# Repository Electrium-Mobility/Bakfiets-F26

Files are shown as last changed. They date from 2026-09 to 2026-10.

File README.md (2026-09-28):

# Bakfiets F26

Electrium Mobility's electric cargo bike ("Bak Choy"), Fall 2026. This repo holds everything from the 2024 build and the 2025 co-op CAD.

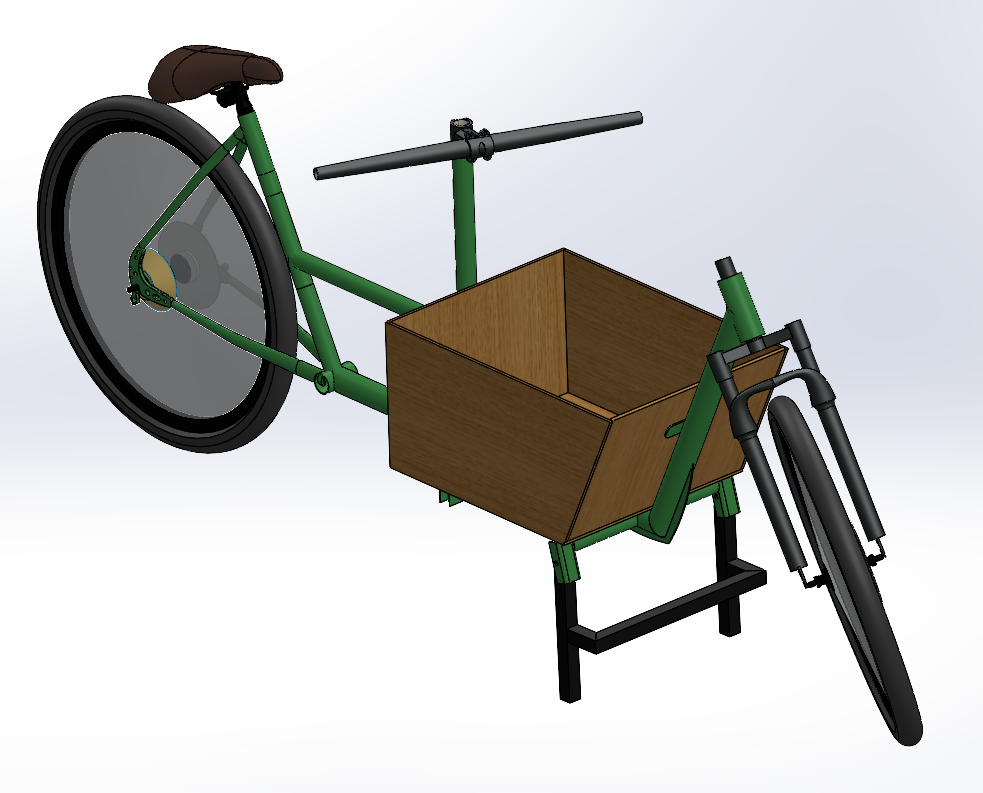
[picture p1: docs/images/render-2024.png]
2024 render of the bakfiets


## New here?

**Open [ONBOARDING.md](ONBOARDING.md).** Everything you need is there, starting with a short to-do list at the top. Setup takes about 2 to 3 hours. Questions go in your subteam's channel.

## What's in this repo

| Folder | What's inside | Start with |
| --- | --- | --- |
| [`mechanical/`](mechanical/) | All SolidWorks CAD | [`mechanical/README.md`](mechanical/README.md) |
| [`mechanical/cad-2025-coop/`](mechanical/cad-2025-coop/) | Newest model (May 2025), matches the partly built bike | `bakfiets_main_asm.SLDASM` |
| [`mechanical/cad-2024/`](mechanical/cad-2024/) | The 2024 design: frame, steering, kickstand, cargo box, welding jig, notching guides, FEA study | `Assem1.SLDASM` |
| [`electrical/`](electrical/) | The 2024 block diagram and notes on reusable boards | [`electrical/README.md`](electrical/README.md) |
| [`firmware/`](firmware/) | Display code, a ready-to-run desk demo, the CAN bus example | [`firmware/desk-demo/desk-demo.ino`](firmware/desk-demo/desk-demo.ino) |
| [`docs/setup/`](docs/setup/) | Extra setup detail and videos for each subteam | [`2-mechanical.md`](docs/setup/2-mechanical.md) |
| [`docs/term-projects.md`](docs/term-projects.md) | The main goals for the term, for after onboarding | |
| [`docs/reference-projects.md`](docs/reference-projects.md) | Other Electrium repos worth copying from | |
| [`docs/meetings/`](docs/meetings/) | Agenda and notes for each team meeting | [`2026-09-30.md`](docs/meetings/2026-09-30.md) |
| [`docs/diagrams/`](docs/diagrams/) | Onboarding path, bike overview, team structure, how to submit, term project map (with the scripts that draw them) | |
| [`docs/images/`](docs/images/) | Renders, CAD previews, photos | |
| [`docs/history/`](docs/history/) | Old README, website pages, and where every file came from | [`SOURCES.md`](docs/history/SOURCES.md) |

## Where the project stands

See [Where It Stands](ONBOARDING.md#where-it-stands) and [Open Questions](ONBOARDING.md#open-questions) in the onboarding guide. The main goals for the term are in [docs/term-projects.md](docs/term-projects.md).

## Rules for this repo

- Work on a branch and open a pull request. Don't push straight to `main`.
- Don't move or rename SolidWorks files inside `cad-2024/` or `cad-2025-coop/`. Assemblies find their parts by folder path, and moving files breaks them.
- Put new work in a new folder, for example `mechanical/cad-2026/` or `firmware/display-2026/`. Copy CAD with SolidWorks **Pack and Go**, and only one person edits a CAD file at a time.

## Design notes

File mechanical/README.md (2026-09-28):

# Mechanical

All SolidWorks files for the bakfiets. Setup steps are in [docs/setup/2-mechanical.md](../docs/setup/2-mechanical.md).

**Don't move or rename files inside `cad-2024/` or `cad-2025-coop/`.** The assemblies find their parts by folder path. Put new work in `cad-2026/`, copying what you need with **File > Pack and Go** (add a prefix so names don't clash). One person edits a CAD file at a time: say on your issue which files you're changing, because Git can't merge two edits to the same SolidWorks file.

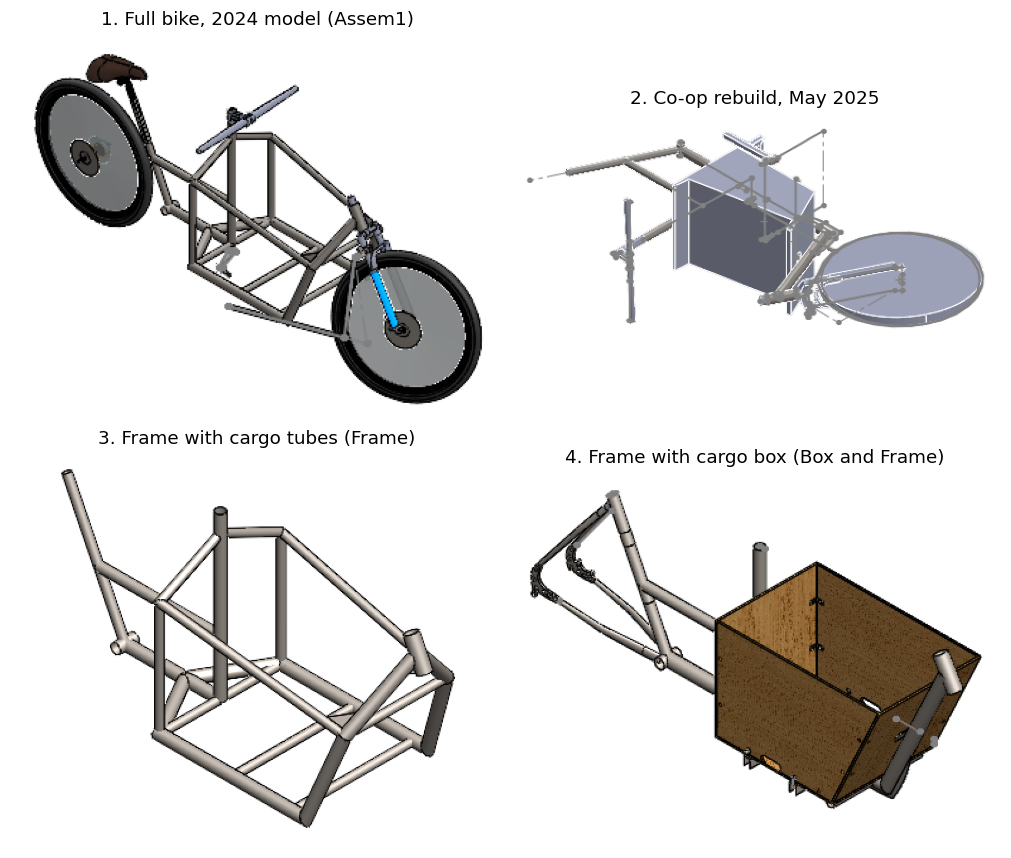
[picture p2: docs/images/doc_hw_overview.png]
CAD overview


## Which model to use

| Folder | What it is | When to use it |
| --- | --- | --- |
| [`cad-2025-coop/`](cad-2025-coop/) | A clean rebuild from May 2025, on the `summer2025coop` branch (GitHub user Anthony3141). One master sketch drives the frame, suspension, steering rod, kickstand and a simple cargo box. Its commit says it models the partly built bike | Start here |
| [`cad-2024/`](cad-2024/) | The full 2024 design, exactly as the 2024 team left it | For parts the co-op model lacks: the jig, the notching guides, detailed steering and cargo box |
| [`cad-2025-coop/edited-2024-parts/`](cad-2025-coop/edited-2024-parts/) | Five 2024 parts the `summer2025coop` branch changed (kickstand, cargo box, aluminium angles) | Compare with the 2024 versions before using either |

## cad-2025-coop: the newest model

| File | What it is |
| --- | --- |
| `bakfiets_main_asm.SLDASM` | **Open this.** The whole bike |
| `bakfiets_master_sketch.SLDPRT` | The layout sketch every part follows |
| `bakfiets_frame.SLDPRT` | The frame (weldment) |
| `bakfiets_front_suspension.SLDPRT`, `bakfiets_front_wheel.SLDPRT` | Front end |
| `bakfiets_steering_handlebars.SLDPRT`, `bakfiets_steering_rod.SLDPRT`, `bakfiets_ball_joint.SLDPRT` | Steering linkage |
| `bakfiets_kickstand.SLDPRT` | Kickstand |
| `bakfiets_cargo_box_low_detail.SLDPRT` | Simple cargo box |
| `bakfiets_weldment_profiles/` | Tube profiles. Add the `cad-2025-coop` folder under SolidWorks File Locations > Weldment Profiles (see the setup guide) |

## cad-2024: the full 2024 design

| Part | Where | Notes |
| --- | --- | --- |
| Whole bike | `Assem1.SLDASM` | The 2024 top-level assembly |
| Frame | `Frame 2.0.SLDPRT`, drawing `Frame 2.0-Sweep8.SLDDRW` | Latest 2024 frame. Nobody recorded whether the drawing was used to build it |
| Tube sizes | `Weldment Cross-section/` | In the file names, as outside diameter x wall. Main tube 1.5" x 0.065", steering tube 36 x 1.1 mm, cargo tube 1" x 0.065", bottom bracket 38.1 x 3.3 mm, seat tube 28.6 x 0.6 mm, top tube 31.7 x 0.5 mm, head tube 1" x 0.065" or 46 x 1.5 mm. Unverified: a 1" head tube can't hold a standard headset, and 0.5 to 0.6 mm walls are donor-bike tubing, not something students can TIG weld. Confirm on the real frame in #4 |
| FEA | `Frame 2.0-Static 2.*` | One static study on Frame 2.0 (June 2024). The 95 MB results file was left out, so rerun the study to regenerate it. No record of the loads used |
| Welding jig | `jig/Jig/JigV2.SLDASM`, cut files `jig/Jig/*.dwg`, `*.DXF` | Laser-cut MDF jig for the main frame |
| Notching guides | `notches/*.STL` | 3D-print, slide over the tube, and cut to the line |
| Steering | `steering system/steeringAssembly.SLDASM` | Linkage, ball joint, steering plates |
| Kickstand | `KickstandAssembly.SLDASM`, `Kickstand.SLDPRT`, `KickstandBracketFeb15.SLDPRT` | |
| Cargo box | `Cargo Box/Cargo Box.SLDASM`, `Box and Frame.SLDASM`, `Box with angles.SLDASM` | Several versions, none marked final |
| Motor | `MotorCrank/CrankMotorAssembly.SLDASM` | A crank-mounted (mid-drive) motor model |
| Printed parts | `scrap bike parts/stem parts/turnSignalCase*.STL`, `battery box/battery pack/Antispark cover.SLDPRT` | Turn signal housing and antispark cover |
| Donor parts | `scrap bike parts/` | Fork, wheels, seat and stem modelled from scrap bikes |

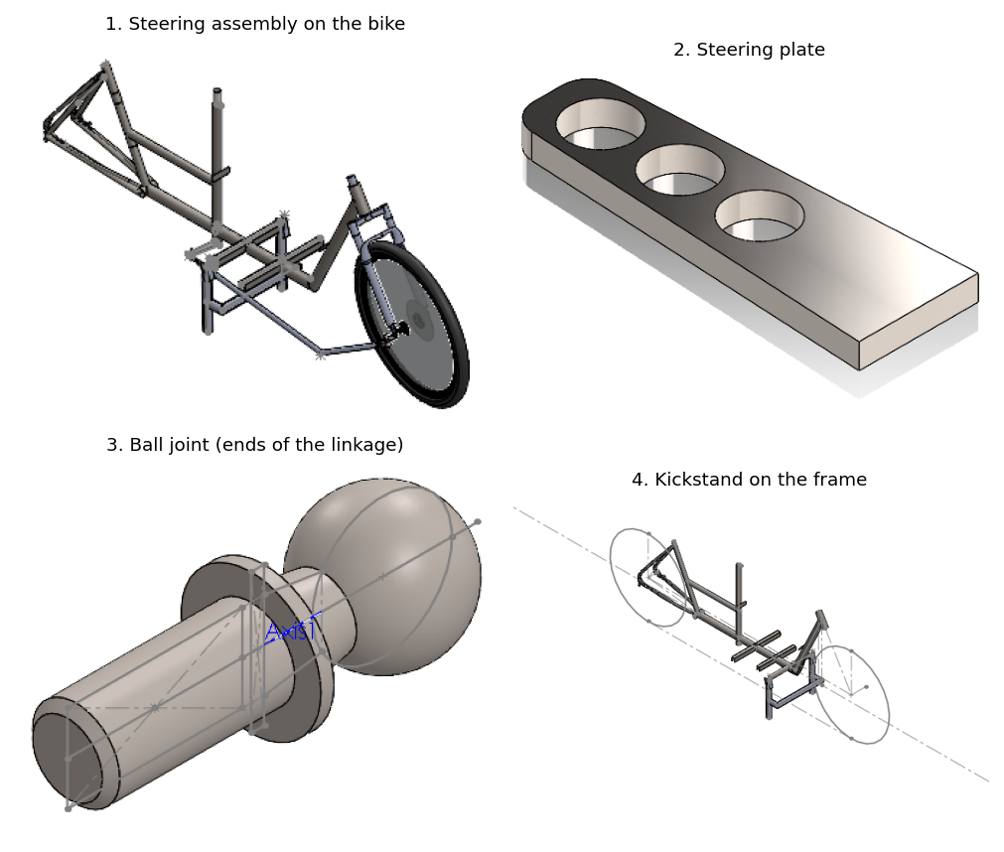
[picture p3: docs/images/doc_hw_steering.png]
Steering and kickstand


*How the steering works: the handlebars turn a plate under the frame. A rod with a ball joint at each end carries that motion forward to a plate on the fork, so the front wheel turns.*

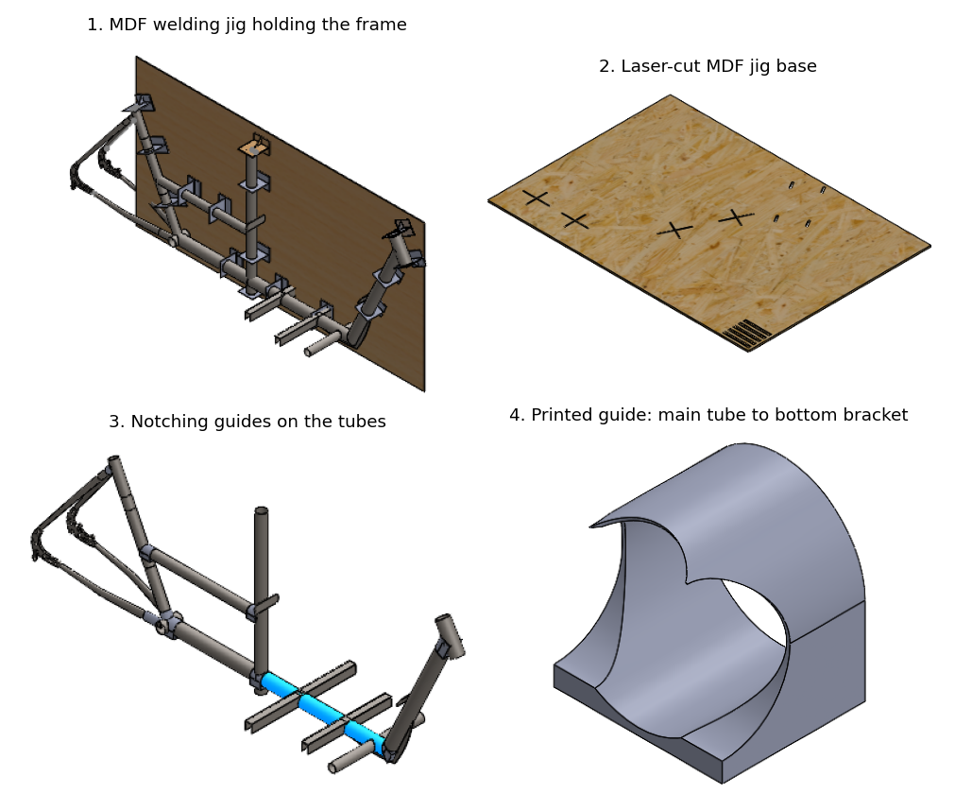
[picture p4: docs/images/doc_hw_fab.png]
Jig and notching guides


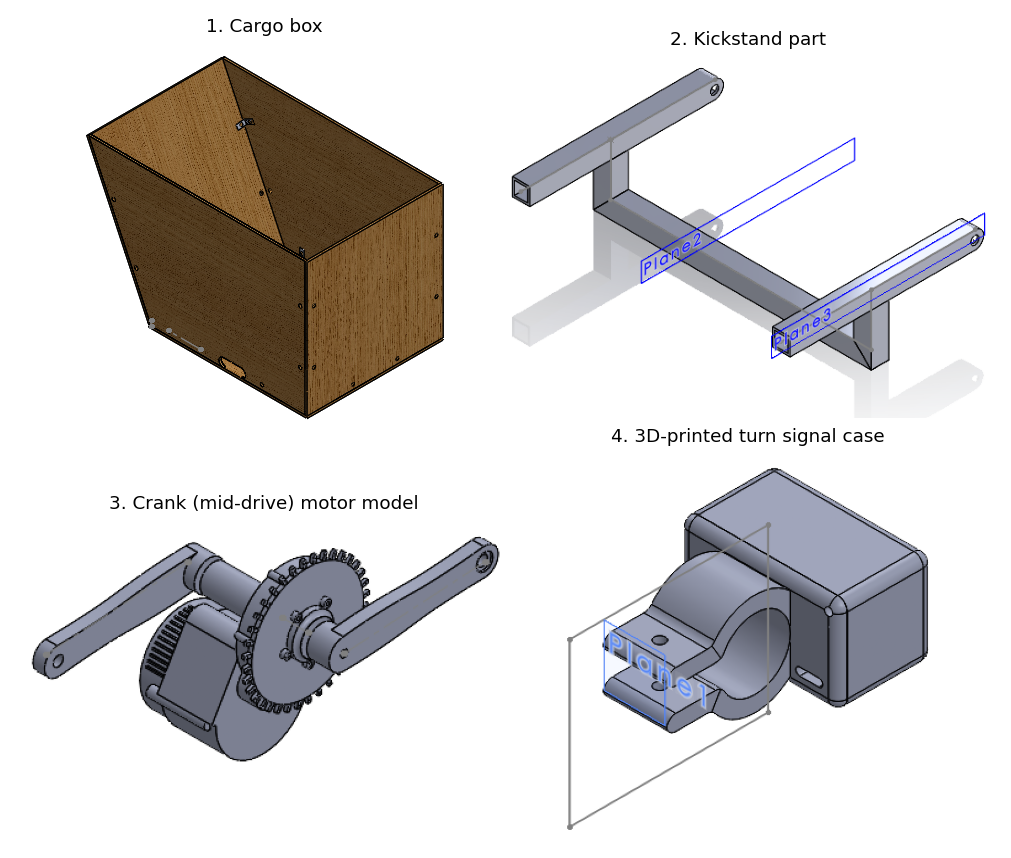
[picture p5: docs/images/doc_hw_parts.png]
Other parts


More previews of individual parts are in [`docs/images/cad-previews/`](../docs/images/cad-previews/).

## Gaps

- No record of the FEA loads or results
- No battery mount in any model
- Nobody has recorded how much of the real frame is welded

Don't send any drawing out for cutting or welding until the FEA loads and results are written down ([issue #6](https://github.com/Electrium-Mobility/Bakfiets-F26/issues/6)) and the mechanical lead and project lead have approved it.

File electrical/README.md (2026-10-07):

# Electrical

Setup steps are in [docs/setup/3-electrical.md](../docs/setup/3-electrical.md).

Only one electrical file survived from 2024: a block diagram, redrawn below. We'll use Pack 4, a 48 V pack labelled 12S2P, and a 48 V, 2000 W direct-drive hub motor in a 24" wheel. Both are in the Electrium bay ([#21](https://github.com/Electrium-Mobility/Bakfiets-F26/issues/21), [#1](https://github.com/Electrium-Mobility/Bakfiets-F26/issues/1)). The team already has a BMS and a charger, so neither needs buying. Photos of the motor, controller and packs are in [docs/photos/bay-2026-10](../docs/photos/bay-2026-10/README.md). We'll set the motor controller to 500 W in VESC Tool ([#18](https://github.com/Electrium-Mobility/Bakfiets-F26/issues/18)). The 2024 schematics and pack notes aren't in any Electrium repo. This term starts the electrical design fresh.

## The pack is "48 V"

Pack 4 is labelled 12S2P: 12 groups in series, each group being 2 cells in parallel, 24 cells in total. That's about 44 V nominal, 50.4 V full and about 36 V empty. "48 V" is the class name. (The website says the 2024 pack was 12S3P, but that pack hasn't been found.) **Every part that touches the battery must be rated well above 50.4 V: 100 V MOSFETs and capacitors, and fuses DC-rated for at least 60 V. The one exception is a surge (TVS) diode, whose standoff should sit just above 50.4 V (about 54 to 58 V), with its clamp voltage below 100 V.**

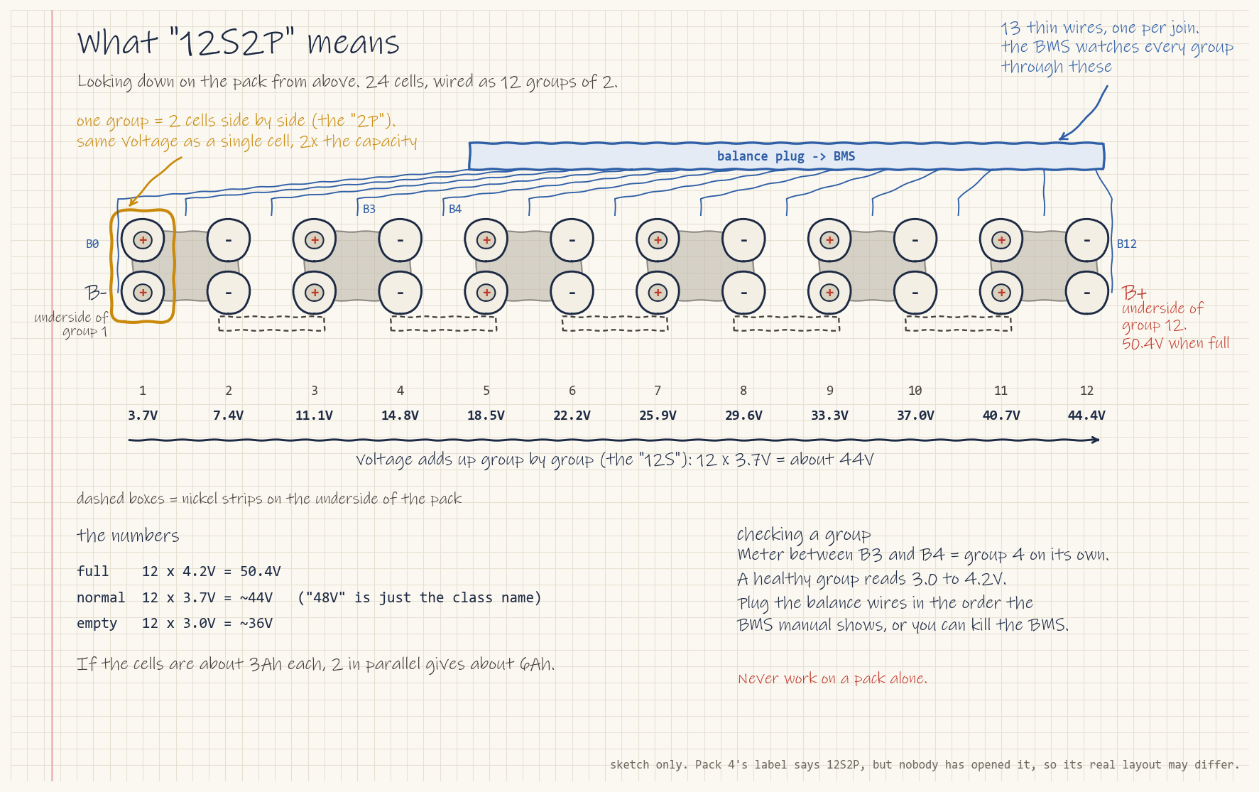
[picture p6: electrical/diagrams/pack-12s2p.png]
Inside a 12S2P pack


## How power flows through the bike

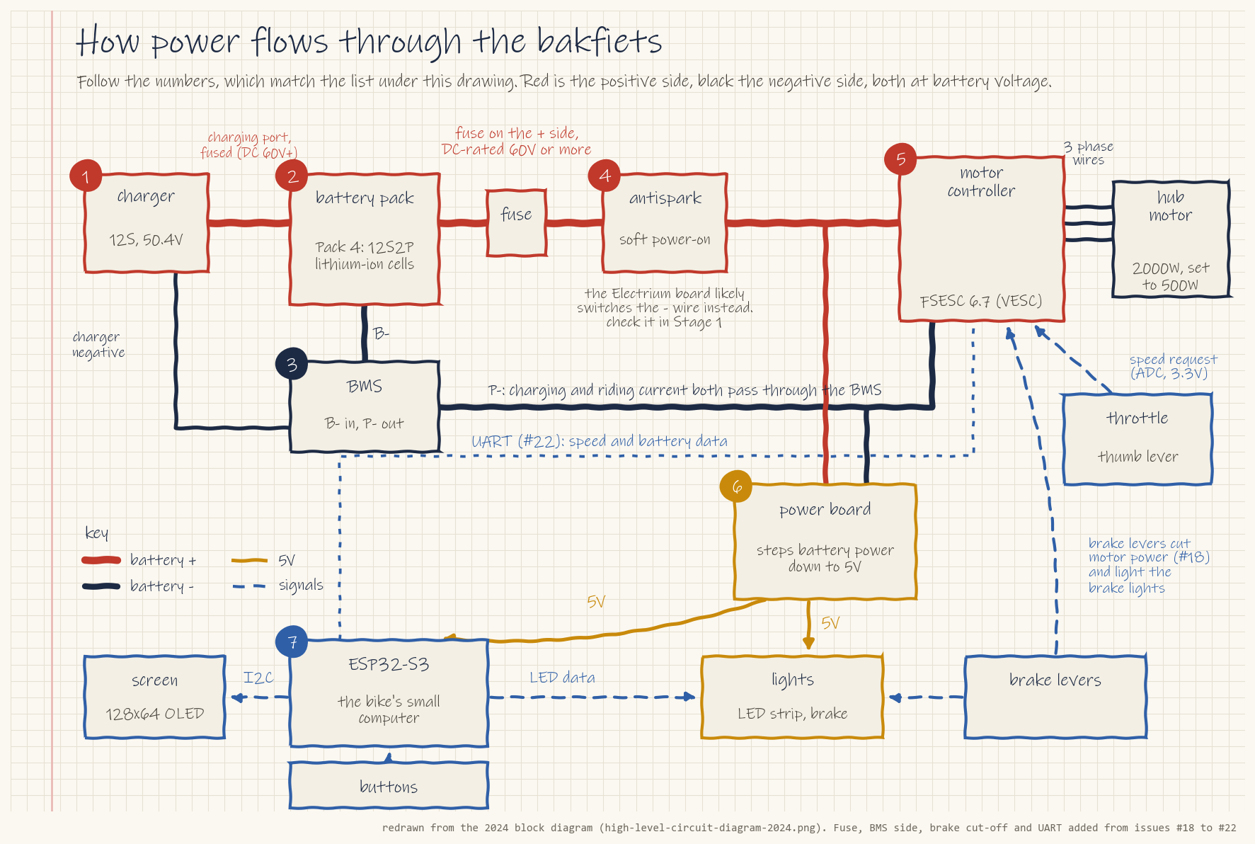
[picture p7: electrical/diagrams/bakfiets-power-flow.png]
How power flows through the bakfiets


A redrawn, color-coded version of the 2024 block diagram. Red lines carry full battery voltage and orange lines carry 5 V. Dashed blue lines are signals only. The original is [`diagrams/high-level-circuit-diagram-2024.png`](diagrams/high-level-circuit-diagram-2024.png), and the script that draws this one is next to it.

Follow the numbers:

1. **Charger.** Plugs into a charging port on the frame and fills the pack to 50.4 V.
2. **Battery pack.** Pack 4, 12S2P. Its positive side goes through a fuse, DC-rated for 60 V or more.
3. **BMS.** Sits on the pack's negative side (B- in, P- out), so charging and riding current both pass through it. Cuts the pack off on overcharge, over-discharge, overheating or a short.
4. **Antispark.** The power button turns it on, so the controller's capacitors charge gently instead of sparking. The Electrium anti-spark board uses N-channel MOSFETs, which usually means it switches the negative wire. Check its schematic. If it does switch the negative wire, the power board and the ESP32 must take their negative from the switched side too. Otherwise the ESP32's ground wire to the controller becomes a path around the antispark, which can damage the controller's COMM port or the ESP32.
5. **Motor controller.** The ESC turns battery power into the three motor wires. The throttle sends it a speed request, and the brake levers tell it to cut power.
6. **Power board.** The PDB steps 48 V down to 5 V for the electronics and lights.
7. **ESP32-S3.** It drives the display over I2C and the LED strip, reads the buttons, and gets speed and battery data from the controller over UART. The brake levers also switch the brake lights.

## What plugs into the motor controller

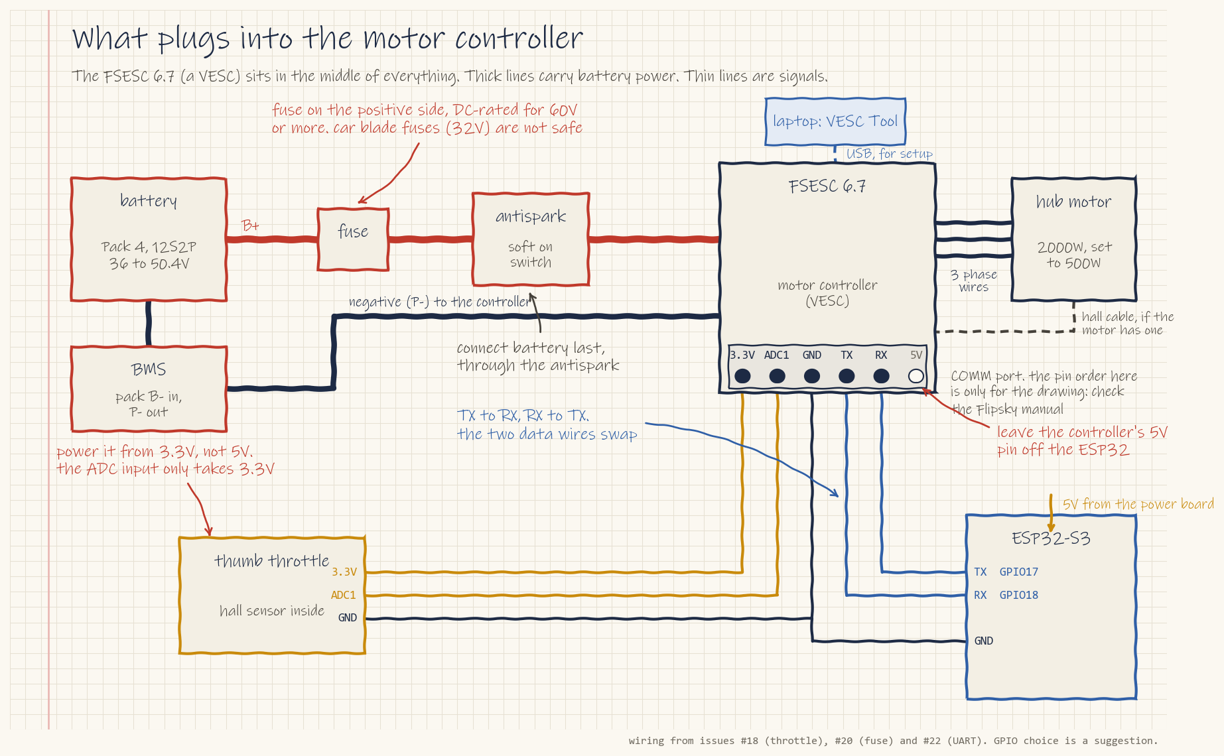
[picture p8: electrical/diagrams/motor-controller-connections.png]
Motor controller connections


The throttle, UART and fuse details come from term projects #18, #20 and #22. The COMM port pin order in the drawing is only for layout, so check the Flipsky manual.

## Boards you can learn from or reuse

| Board | Repo | Use it for |
| --- | --- | --- |
| Antispark switch (2023) | [anti-spark](https://github.com/Electrium-Mobility/anti-spark) | Your first schematic to read: 18 parts, three 100 V MOSFETs, gerbers included |
| Power distribution + antispark (2026) | [power-distribution-antispark](https://github.com/Electrium-Mobility/power-distribution-antispark) | Reference only, see below |
| ESC (2026) | [esc-w26](https://github.com/Electrium-Mobility/esc-w26) | A well-documented README with input protection explained. Built for 36 V |
| Small complete board | [raspberry-pi-breakout](https://github.com/Electrium-Mobility/raspberry-pi-breakout) | A tidy, recent KiCad project with reviewer notes |
| Lights and telemetry | [skateboards26-telemetrylights](https://github.com/Electrium-Mobility/skateboards26-telemetrylights) | Lights and a display fed by power-board signals |

**The 2026 power board can't be used as-is** (from reading its schematic, to be confirmed with the datasheets). Its note says "Max Vin = 48V" and its MOSFETs are 60 V parts, which leaves little margin over a 50.4 V full pack. Its TVS diode (SMCJ48CA) has a 48 V standoff, so a full 50.4 V pack sits above its rating with little margin (breakdown starts at 53.3 V). It also clamps at 77.4 V, above what the 60 V MOSFETs survive. A new version needs 100 V MOSFETs and capacitors, a TVS with a standoff of about 54 to 58 V whose clamp stays below 100 V, and a buck converter rated to match.

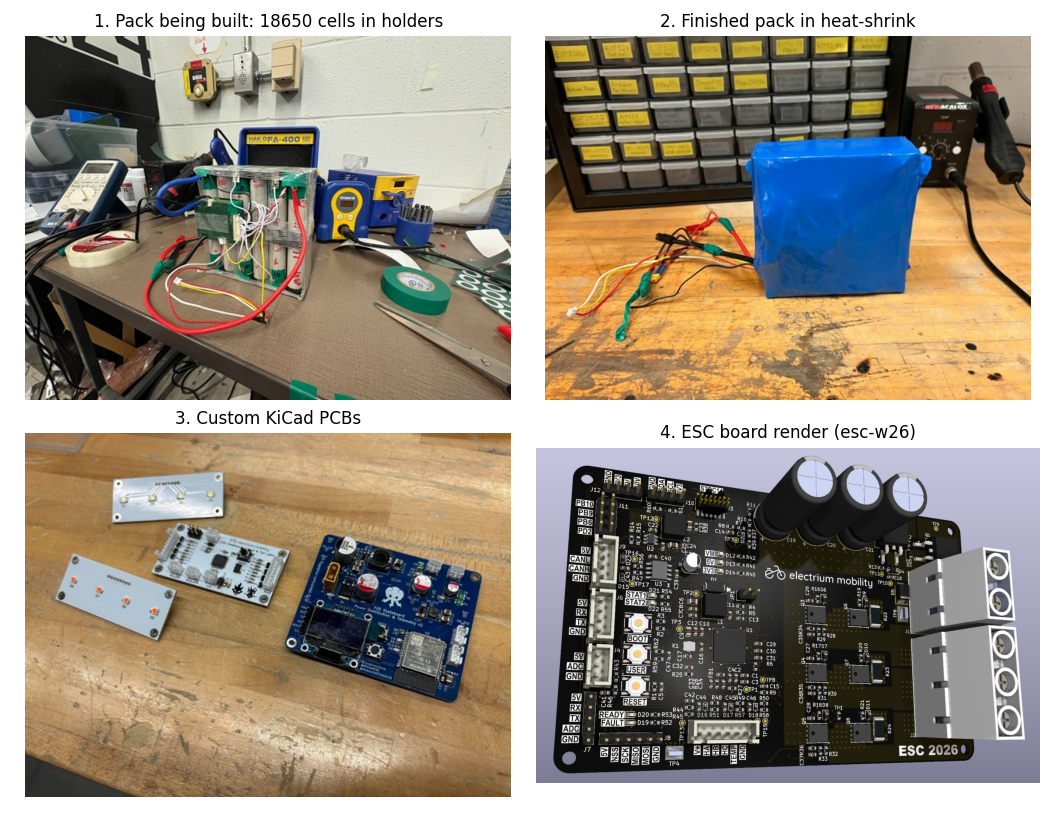
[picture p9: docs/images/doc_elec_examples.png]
Electrical work on other Electrium projects


*Photos 1 to 3 are from the F25 skateboard, and 4 is the esc-w26 board. This is what finished electrical work looks like on this team.*

## Gaps

- Confirm the motor and controller on the real bike ([issue #1](https://github.com/Electrium-Mobility/Bakfiets-F26/issues/1))
- Schematic and PCB for the bakfiets power board
- Pack cells, BMS model and charge port
- Wiring harness, connector pinout and a BOM

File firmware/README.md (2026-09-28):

# Firmware

To run the desk demo, follow [Firmware Stage 1](../ONBOARDING.md#stage-1-run-the-desk-demo) in the onboarding guide. [docs/setup/4-firmware.md](../docs/setup/4-firmware.md) has the same steps with extra help.

| Folder | What it is | Status |
| --- | --- | --- |
| [`desk-demo/`](desk-demo/) | **Start here.** The 2024 display code as a ready-to-open Arduino sketch, with the LED pin moved off GPIO 9 | Should run on an ESP32-S3 with an SSD1306 OLED. The first hardware test is #12 |
| [`display-2024/`](display-2024/) | The original 2024 code (`main.cpp`) and the hand-drawn screen layout | Fixed numbers only, kept unchanged for reference |
| [`can-twai-2024/`](can-twai-2024/) | Two ESP-IDF projects based on Espressif's TWAI (CAN) example, one with an OLED drawn with LVGL (Nov 2024). The folder names are reversed: the "receiver" is the board that transmits | Fixed values on screen (60% and 18), and targets a plain ESP32. ESP-IDF is a different tool from Arduino IDE, and you don't need it for onboarding |
| [`simulator-2024/`](simulator-2024/) | A Rust desktop mock-up of the 128x64 screen | Optional, skip it for onboarding. Setup notes are for macOS |

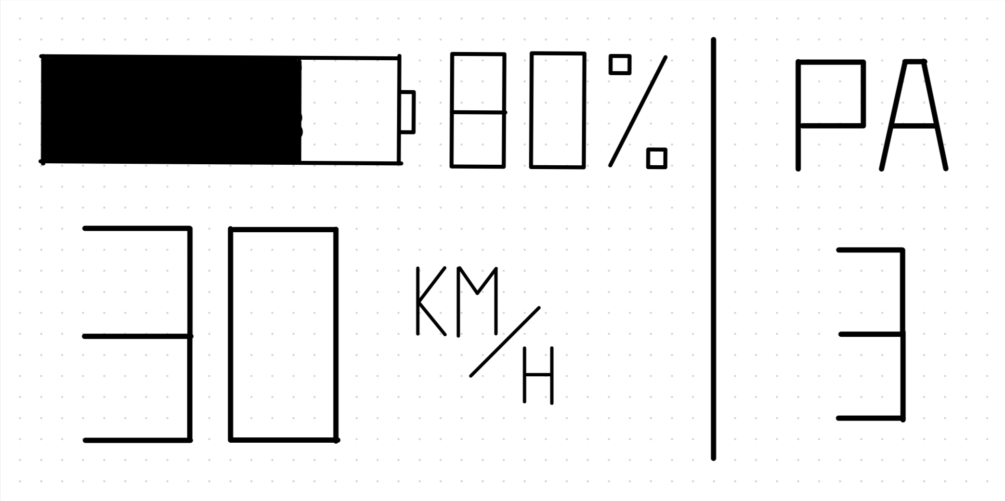
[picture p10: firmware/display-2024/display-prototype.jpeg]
Screen layout


## What the 2024 display does

- SSD1306 128x64 OLED over I2C (SDA GPIO 10, SCL GPIO 9) shows battery %, speed in km/h and pedal-assist level
- A 125-LED WS2813 strip plays a right-turn sweep with FastLED (a left-turn function exists but is never called)
- Every value is fixed in code: battery 50%, 36 km/h, PA 5. Nothing reads the motor, battery or buttons yet

## Known bugs in `display-2024/main.cpp`

1. The LED strip and the OLED clock both use GPIO 9. **Fixed in `desk-demo/`** (LED moved to GPIO 5).
2. The LED animations pause on `delay(10)` for every LED. Five sweeps run before each screen refresh, so the screen updates only every 8 to 9 seconds. Fix: use `millis()` and move one LED per loop.
3. `setup()` calls `loop()` directly.
4. A comment says it tests the left signal, but the code calls `rightTurn()`.
5. Small: the FastLED settings are defined after the library is included, so they do nothing. LED 62 belongs to both sweeps, and `NUMFLAKES` and `logo_bmp` are unused.

## CAN code notes

- Pins: TX GPIO 14, RX GPIO 27. On an ESP32-S3, GPIO 27 is used by the flash and memory chips, so choose new CAN pins before moving this code to the S3.
- Build with ESP-IDF: see the README inside each folder.

## Missing: real motor data

The 2024 README says the team reverse-engineered the Bafang BBS02 motor protocol, but that code isn't in any Electrium repo. The current plan is a hub motor with a VESC controller (to be confirmed in [issue #1](https://github.com/Electrium-Mobility/Bakfiets-F26/issues/1)), and other Electrium repos already read a VESC: see [docs/reference-projects.md](../docs/reference-projects.md#firmware).

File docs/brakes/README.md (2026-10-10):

# Brakes on the Bakfiets

The bike needs a working brake on each wheel before anyone rides it. This page collects what's known so far, with photos of the bike, as a starting point for the brakes task ([#32](https://github.com/Electrium-Mobility/Bakfiets-F26/issues/32)).

## The short version

Side view of the bike with the rear brake line and two example front brake line routes

- The front wheel has a hydraulic disc brake with a hose too short to reach the handlebars. The handlebars sit in the middle of the bike and the front wheel is past the cargo box.
- The back wheel is the hub motor. It has no brake yet, and the motor and frame have no obvious place to mount one.
- Ontario law says pulling either brake lever has to stop the motor.

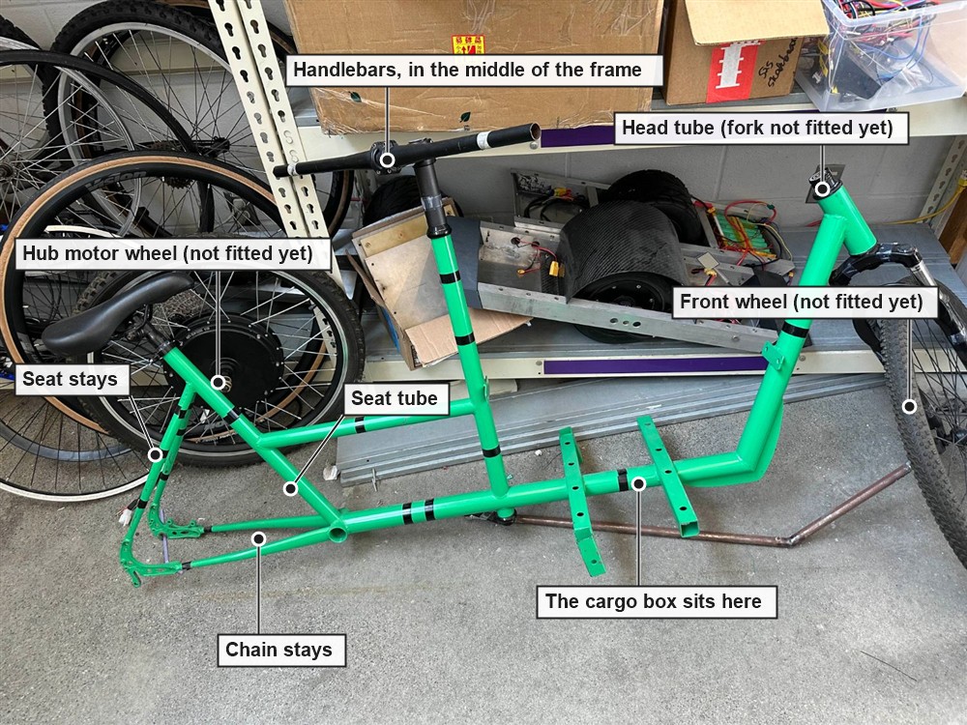
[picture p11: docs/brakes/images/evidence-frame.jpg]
Our frame, labelled


Our frame, with the parts this page talks about. Both wheels are still off the frame.

## Limits

- Each wheel needs its own brake, and together they have to stop the bike from 30 km/h within 9 m on level pavement ([ontario.ca](https://www.ontario.ca/page/riding-e-bike), [O. Reg. 369/09](https://www.ontario.ca/laws/regulation/090369) s. 5). The same regulation caps the bike's unladen weight at 120 kg.
- The motor has to stop pushing when a brake is applied (O. Reg. 369/09 s. 3(2)). A switch on each lever, wired to the controller's ADC2 input, is the usual way ([#18](https://github.com/Electrium-Mobility/Bakfiets-F26/issues/18), step 7).
- Steering and brakes share roughly $220 to $260 of the term's budget, so money spent on one comes out of the other.
- Changing the frame (welding, drilling, filing) needs approval from a mechanical lead and the project lead, because a bad weld or hole weakens a frame that carries cargo.
- Parts go through the project lead once the specs they need to match are posted, so orders stay inside the shared budget.
- Regen (the motor slowing the wheel) can't count as one of the two brakes. It stops working if the controller or battery cuts out, and fades away at low speed.

## Front wheel

The front brake is a hydraulic disc brake. The lever pushes fluid down a hose to a caliper, which grips a metal disc (the rotor) bolted to the hub.

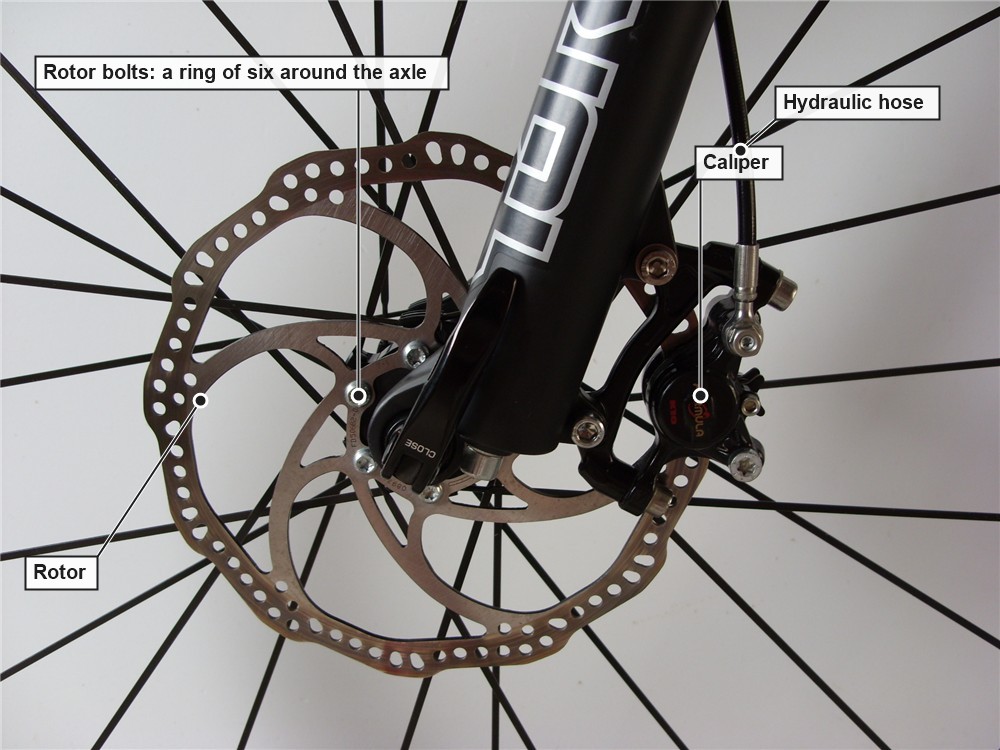
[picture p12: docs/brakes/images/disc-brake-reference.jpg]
A disc brake on another bike, labelled


What a disc brake looks like, on another bike. Ours is the same kind of brake.

Its hose is too short for this layout (seen in the bay). Its brand, model and fluid type decide which parts are compatible, so a close photo of the lever and caliper is the first thing to get.

The handlebars are far from the fork, so whatever steering design gets picked ([#25](https://github.com/Electrium-Mobility/Bakfiets-F26/issues/25)) links the two, and both ends turn. The brake line has to bend at both ends and still reach the caliper at the front axle. It could cross over the cargo box or follow the frame tubes under it (the two examples in the side view).

A long line also changes which kind of brake makes sense. A long cable gets more friction and feels mushier at the lever. A long hydraulic hose stays firm, but every part has to match the brake's fluid and it needs bleeding.

## Back wheel

### The motor has no disc mount

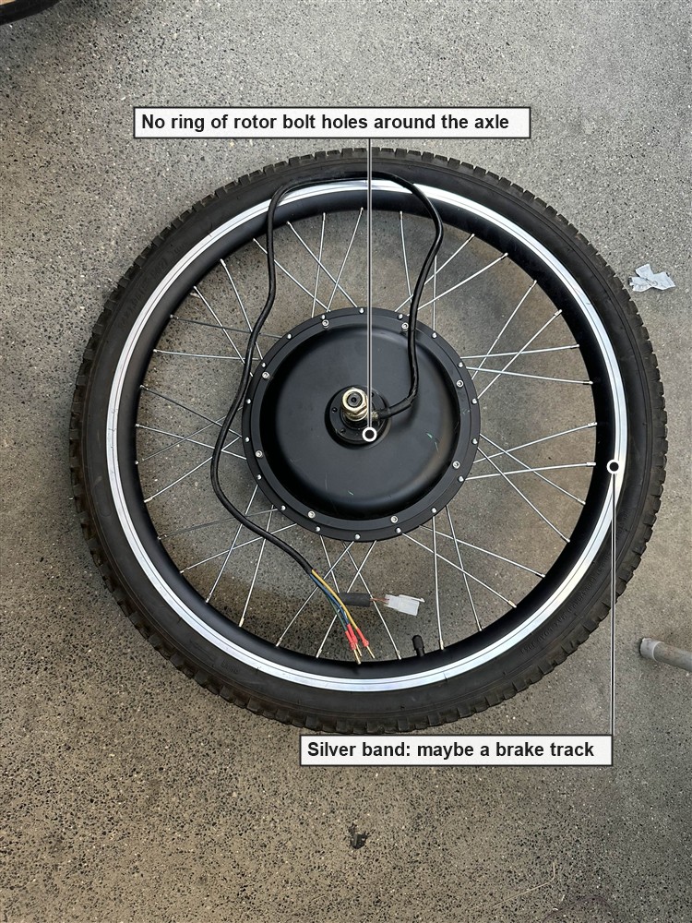
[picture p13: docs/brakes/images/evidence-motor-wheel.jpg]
The motor's cable side, labelled


A disc rotor bolts to a ring of six holes around the axle, like in the disc brake photo above. Both sides of our motor are plain covers held on by small screws.

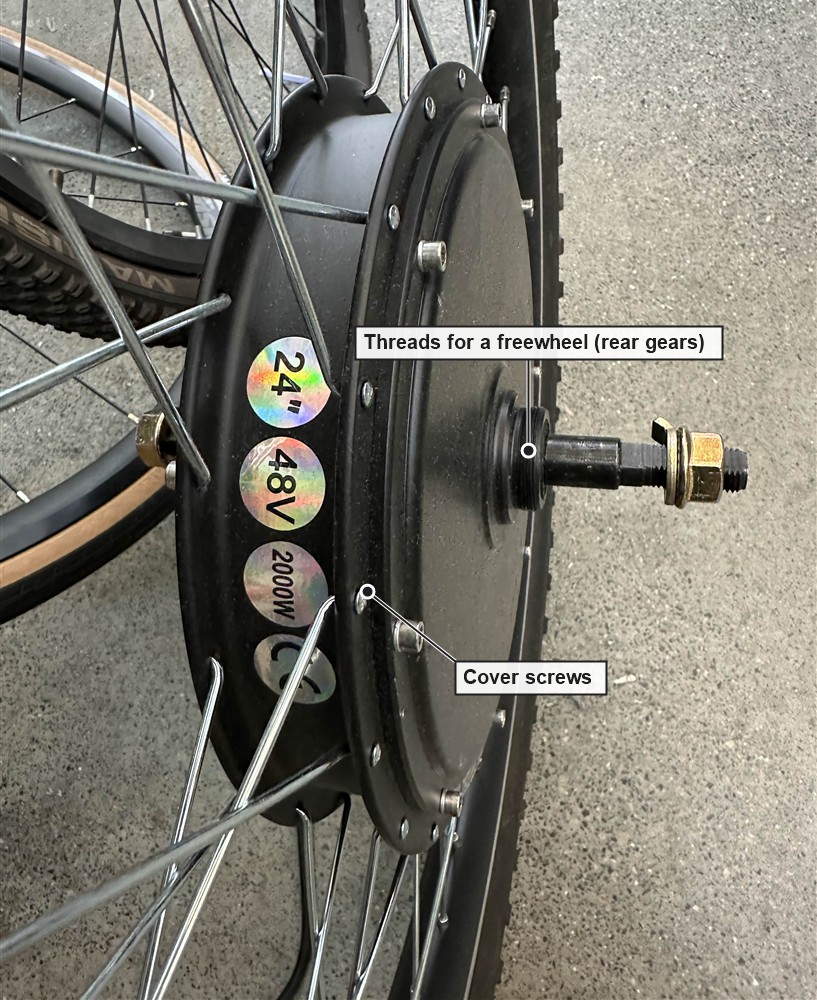
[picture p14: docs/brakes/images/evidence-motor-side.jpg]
The motor's freewheel side, labelled


The motor is built for the back: its axle is wider than a front fork, and the threads next to it are for rear gears. So the back wheel has to be braked around the motor.

### The frame has no rim brake mounts

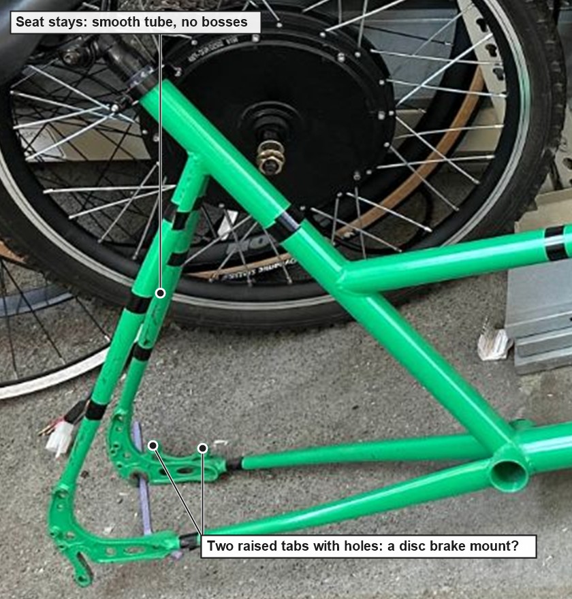
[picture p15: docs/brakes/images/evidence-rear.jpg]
The rear of our frame, labelled


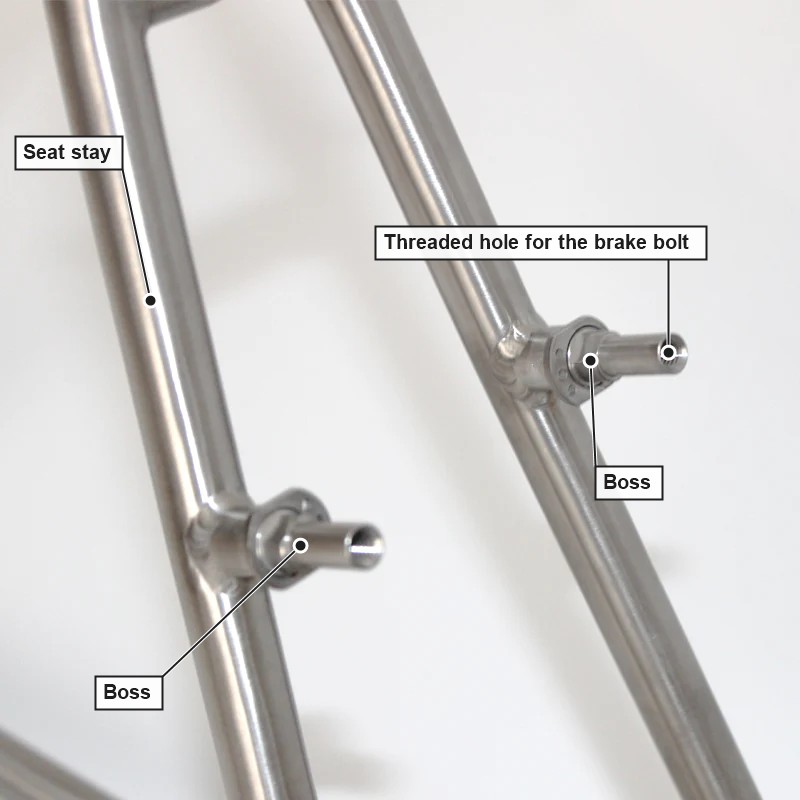
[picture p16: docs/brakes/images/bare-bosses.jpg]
Bare bosses on another bike's seat stays, labelled


V-brakes and cantilever brakes mount on bosses: two short posts on the seat stays, just below the rim (the second photo, from another bike). Our seat stays are smooth tube with no bosses. An old style caliper rim brake needs a bridge between the stays to bolt through, so ours would need one added.

The rim has a silver band along its edge, which is usually a surface for rim brakes, if it's flat enough for the pads to grip.

One dropout plate has two raised tabs with holes in them. A disc caliper bolts to a pair of tabs like that, so they might be a disc brake mount (check 3 below covers how to tell).

### Approaches people use

For a rear hub motor with no disc mount:
- Bosses brazed or welded onto the seat stays, then a V-brake. Changes the frame.
- Clamp-on boss plates. Leaves the frame alone, but riders worry the clamps can slip under braking ([forum thread](https://cyclechat.net/threads/v-brakes-fitting-to-a-frame-without-bosses.26234)).
- An adapter that bolts a rotor to the motor's cover screws. Those screws are small and weren't made for braking loads, and it still needs a caliper mount on the frame.
- A disc tab, if the dropouts turn out to have one.
- A different motor with a disc mount.

Drum and coaster brakes need a hub built for them, which rules them out here. Braking on the motor shell itself would put heat right next to the magnets, which weaken when hot.

## Open questions

Check in the bay first:
1. The front brake's brand, model, fluid type and hose fittings. A longer hose, a new lever or a bleed kit all have to match these, and mixing mineral oil with DOT fluid ruins the seals.
2. The silver band on the rim, up close. A rim brake needs a flat metal surface to grip, so this decides whether rim brakes are an option for the back at all.
3. The two raised tabs on the dropout: the spacing between their holes and which side of the bike they're on. 51 mm apart is an IS disc mount and 74 mm is a post mount, and a rear disc tab only works on the left side. If it's a disc tab, a disc brake on the back becomes possible.

Then work out:
1. Reuse the front brake with a longer hose, or replace it? What would make each one the better choice?
2. Over the box or along the frame, and how long is the line then? The length decides what to buy, and the route has to survive the steering turning at both ends.
3. How will the back wheel be braked, what does it cost, and does it change the frame? Every rear option needs new mounts, an adapter or a different motor, so it could take a big share of the budget.
4. Which cut-off switch fits the levers you pick? It has to plug into the controller's ADC2 input. Some levers have one built in, others need a separate sensor.

## What the brakes task should produce

Front brake, due Wed 21 Oct:
- a chosen setup, with the reasons
- the parts and the specs they have to match (hose length and fittings, fluid type, levers with a cut-off switch)

Back brake, due Wed 28 Oct:
- the options compared, with costs
- any frame change or motor swap, flagged for approval

## Background

<details>
<summary>How a rim brake works on bosses</summary>

A rim brake mounted on bosses, seen from behind the wheel (simplified)

Each brake arm pivots on a boss. The cable pulls the tops of the arms together, so the pads squeeze the rim.

A real V-brake mounted on bosses, labelled

A real V-brake. The boss is hidden under the pivot bolt.

</details>

<details>
<summary>How the hub motor works</summary>

Inside a direct-drive hub motor

The axle and the stator (copper coils) are fixed to the frame and never turn. The shell, with magnets on its inside, spins around them and turns the wheel through the spokes. The controller sends current through the three phase wires in a rotating pattern, so the coils' magnetic field turns and drags the magnets along. This is also why braking on the shell is a bad idea: the magnets sit right under it and weaken when hot.

</details>

<details>
<summary>Words used here</summary>

- ADC2: the controller input the brake cut-off switch plugs into.
- Boss: a short post on the frame that a V-brake or cantilever arm pivots on.
- Bleed kit: tools and fluid for filling a hydraulic brake and pushing out air.
- Caliper: the part that squeezes. On a disc brake it grips the rotor.
- Dropouts: the plates at the back where the rear axle sits.
- Freewheel: the rear gears, which screw onto the hub.
- IS and post mount: the two common ways a disc caliper bolts to a frame or fork.
- Rotor: the metal disc on the hub that a disc caliper grips.
- Seat stays and chain stays: the pairs of tubes that run to the rear axle, from under the seat and from the pedals.

</details>

## Image credits

- Disc brake photo: [StromBer, Wikimedia Commons](https://commons.wikimedia.org/wiki/File:BrakeDiskVR.JPG), CC BY 3.0. Resized and labelled.
- V-brake photo: [Keithonearth, from a photo by ArnoldReinhold, Wikimedia Commons](https://commons.wikimedia.org/wiki/File:Linear_pull_bicycle_brake_highlighted.jpg), CC BY-SA 3.0. Resized and labelled.
- Bare bosses photo: [Bicycles Stack Exchange](https://bicycles.stackexchange.com/questions/87966/aside-from-brakes-what-items-can-be-mounted-to-v-brake-mounts), CC BY-SA. Resized and labelled.
- Frame and motor photos, labels and diagrams: Bakfiets F26.

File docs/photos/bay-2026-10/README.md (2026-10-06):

# What's in the bay (October 2026)

Photos taken in the Electrium bay in early October 2026. Look only: nobody plugs in, charges or opens a pack until it has been checked ([#21](https://github.com/Electrium-Mobility/Bakfiets-F26/issues/21)).

## Hub motor

The motor the bike uses: a direct-drive hub motor already built into a 24" wheel. The stickers say 24", 48 V and 2000 W. It has three thick phase wires with bullet plugs and a separate hall sensor plug.

| Photo | What it shows |
| --- | --- |
| [hub-motor-24in-48v-2000w-stickers.jpg](hub-motor-24in-48v-2000w-stickers.jpg) | The 24", 48 V, 2000 W stickers |
| [hub-motor-axle-label.jpg](hub-motor-axle-label.jpg) | The axle side, with the motor's printed code |
| [hub-motor-wheel.jpg](hub-motor-wheel.jpg) | The whole wheel |
| [hub-motor-phase-and-hall-plugs.jpg](hub-motor-phase-and-hall-plugs.jpg) | The three phase wires and the hall plug |
| [hub-motor-hall-plug.jpg](hub-motor-hall-plug.jpg) | The hall sensor plug up close |

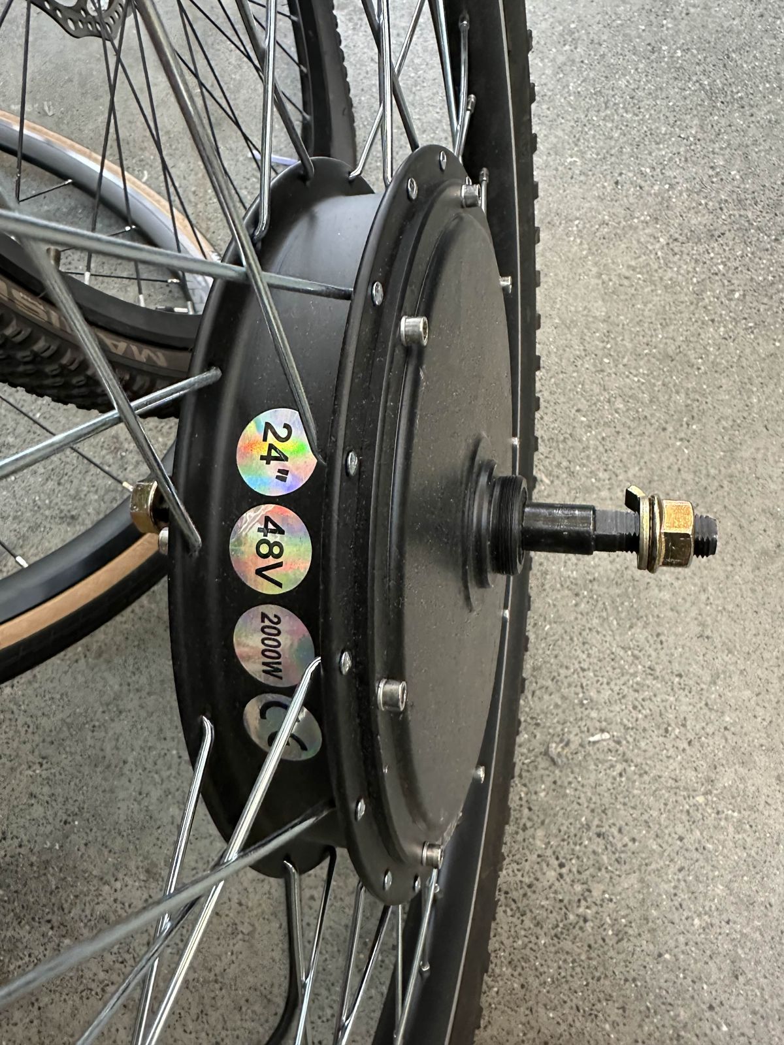
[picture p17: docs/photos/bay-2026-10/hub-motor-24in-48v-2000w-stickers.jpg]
Hub motor stickers: 24 inch, 48 V, 2000 W


## Motor controller and antispark

The controller has a USB-C port and three 100 V capacitors, which fits a VESC-style controller. No model label shows in these photos, so check the underside before powering it ([#18](https://github.com/Electrium-Mobility/Bakfiets-F26/issues/18)).

| Photo | What it shows |
| --- | --- |
| [motor-controller-heatsink.jpg](motor-controller-heatsink.jpg) | The controller from the heatsink side |
| [motor-controller-ports.jpg](motor-controller-ports.jpg) | The other side: USB-C and signal connectors |
| [antispark.jpg](antispark.jpg) | The antispark that goes between the battery and the controller |

## Battery packs

Four labelled packs. The bike uses **Pack 4**. The team also has a BMS and a charger.

| Photo | Label |
| --- | --- |
| [pack4-48v-12s2p-label.jpg](pack4-48v-12s2p-label.jpg) | **Pack 4: 48 V (12S2P)**, last charged 30 Jul 2026. The one we use |
| [pack3-36v-10s2p-label.jpg](pack3-36v-10s2p-label.jpg) | Pack 3: 36 V (10S2P) |
| [pack3-back.jpg](pack3-back.jpg) | Pack 3, other side |
| [pack3-connector-and-charge-cable.jpg](pack3-connector-and-charge-cable.jpg) | Pack 3's main plug and a charge cable |
| [pack2-36v-label.jpg](pack2-36v-label.jpg) | Pack 2: 36 V, last charged 30 Jul 2026 |
| [pack1-label-faded.jpg](pack1-label-faded.jpg) | Pack 1: label too faded to read, last charged 9 Sep 2026 |
| [pack1-leads.jpg](pack1-leads.jpg) | Pack 1's leads |

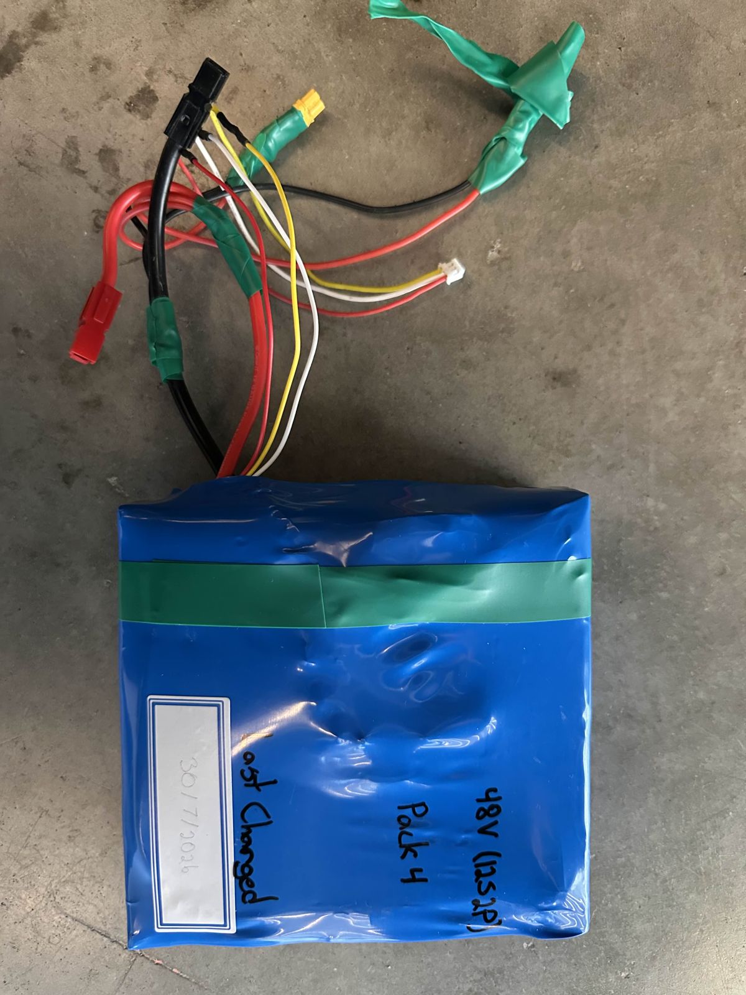
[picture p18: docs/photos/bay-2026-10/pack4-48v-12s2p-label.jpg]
Pack 4 label: 48 V, 12S2P


## Other

| Photo | What it shows |
| --- | --- |
| [esp32-s3-devkitc-1-box.jpg](esp32-s3-devkitc-1-box.jpg) | The ESP32 boards: Espressif ESP32-S3-DevKitC-1, the board the desk demo is written for |
| [esp32-s3-devkitc-1.jpg](esp32-s3-devkitc-1.jpg) | One of the boards out of its box |
| [spot-welder.jpg](spot-welder.jpg) | A portable spot welder (Kerpu), for building packs |

The full-size originals are kept by the project lead.

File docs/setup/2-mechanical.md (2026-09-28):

# Setup for mechanical

Do [Getting Started](../../ONBOARDING.md#getting-started) in the onboarding guide first. Your files are in the `mechanical/` folder of your clone.

The steps you have to do are in [Mechanical Stage 1](../../ONBOARDING.md#stage-1-open-the-bike). This page repeats them with extra help, so you don't need to do anything twice.

## 1. Get SolidWorks 2026

The team uses **SolidWorks 2026**, the version on the campus lab PCs. Files saved in 2026 can't be opened in older versions.

- **On campus:** the Engineering Computing labs Fulcrum, Helix, Lever and WEEF have SolidWorks 2026 ([lab software list](https://uwaterloo.ca/engineering-computing/computer-labs/lab-software)). The Sedra Student Design Centre also has a 14-seat CAD studio for teams.
- **On your own laptop:** SolidWorks sells a student licence ([solidworks.com/product/students](https://www.solidworks.com/product/students)). It runs on Windows only, so on a Mac, use a lab PC.

First time? Watch [Beginners Guide to SOLIDWORKS: Your First Part](https://www.youtube.com/watch?v=qjtYqxNpj50) (SOLIDWORKS, 8 min).

## 2. Tell SolidWorks where the tube profiles are

The frame is built from custom tube shapes ("weldment profiles") stored in your clone. SolidWorks needs to know where they are, or the frame won't rebuild. This way needs no admin rights, so it also works on lab PCs.

1. Open SolidWorks and choose **Tools > Options > System Options > File Locations**.
2. In **Show folders for**, pick **Weldment Profiles**.
3. Click **Add** and choose your clone's `mechanical\cad-2025-coop` folder (the one that contains `bakfiets_weldment_profiles`).
4. Click **OK**, then **Yes** if asked to confirm.

## 3. Open the bike

1. In SolidWorks, choose **File > Open**.
2. Go to your clone's `mechanical\cad-2025-coop` folder and open `bakfiets_main_asm.SLDASM`.
3. If SolidWorks asks where a part is, point it at the same `cad-2025-coop` folder.
4. You're done when the whole bike is on screen and the FeatureManager tree on the left has no red or yellow warning icons. When you close it, click **Don't Save** if SolidWorks asks.

The parts are built around one master sketch, `bakfiets_master_sketch.SLDPRT`. To change the geometry, make a copy in `mechanical/cad-2026/` with **File > Pack and Go** (add a prefix so names don't clash) and work on the copy. Don't save files while they're open from `cad-2025-coop`: SolidWorks 2026 converts them on save. One person edits a CAD file at a time: say on your issue which files you're changing, because Git can't merge two edits to the same SolidWorks file.

If the frame still shows rebuild errors, copy the `bakfiets_weldment_profiles` folder into the default Weldment Profiles folder listed in the same File Locations dialog (this one needs admin rights).

## 4. Learn the frame tools

Optional. Watch these when a Stage 2 task needs them: weldments help with any CAD task, and FEA is only for #6.

- Weldments (how the frame is built): [Introduction to Weldments](https://www.youtube.com/watch?v=nbMxA178ADM) (CAD Decoded, 15 min)
- FEA (checking the frame is strong enough): [Static analysis for beginners](https://www.youtube.com/watch?v=Ys0eT57DzT4) (CAD Hub, 28 min)
- Tube mitering (shaping tube ends to fit): [How to miter bicycle tubes with a hand file](https://www.youtube.com/watch?v=mqS2rbv58Zs) (Cobra Framebuilding, 12 min)
- TIG welding chromoly, to understand the process only: [Learn how to TIG weld 4130 tubing](https://www.youtube.com/watch?v=nQ3bRaoMv74) (Miller, 3 min)

## 5. Where the 2024 files are

| Need | File in your clone |
| --- | --- |
| Whole 2024 bike | `mechanical/cad-2024/Assem1.SLDASM` |
| Frame and its drawing | `mechanical/cad-2024/Frame 2.0.SLDPRT`, `mechanical/cad-2024/Frame 2.0-Sweep8.SLDDRW` |
| Welding jig | `mechanical/cad-2024/jig/Jig/JigV2.SLDASM` |
| Notching guides | `mechanical/cad-2024/notches/` |
| Steering | `mechanical/cad-2024/steering system/steeringAssembly.SLDASM` |

Every file is explained in [`mechanical/README.md`](../../mechanical/README.md). Don't move or rename anything in `cad-2024` or `cad-2025-coop`. Save your work in `mechanical/cad-2026/` (create the folder if it's missing).

## 6. Pick a first task

First do Mechanical Stage 1 in [ONBOARDING.md](../../ONBOARDING.md#mechanical-onboarding) (open the bike and post a screenshot in the **#bakfiets-mech** channel), then pick a Stage 2 task there, such as #2 or #3.

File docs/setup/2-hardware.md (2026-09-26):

# Setup for mechanical

Finish [Setup for everyone](1-everyone.md) first. Your files are in the `hardware/` folder of your clone.

## 1. Get SolidWorks 2026

The team uses **SolidWorks 2026**, the version on the campus lab PCs. Files saved in 2026 can't be opened in older versions.

- **On campus:** the Engineering Computing labs Fulcrum, Helix, Lever and WEEF have SolidWorks 2026 ([lab software list](https://uwaterloo.ca/engineering-computing/computer-labs/lab-software)). The Sedra Student Design Centre also has a 14-seat CAD studio for teams.
- **On your own laptop:** SolidWorks Design Standard for Students is free ([solidworks.com/product/students](https://www.solidworks.com/product/students)). It runs on Windows only; on a Mac, use a lab PC.

First time? Watch [Beginners Guide to SOLIDWORKS: Your First Part](https://www.youtube.com/watch?v=qjtYqxNpj50) (SOLIDWORKS, 8 min).

## 2. Tell SolidWorks where the tube profiles are

The frame is built from custom tube shapes ("weldment profiles") stored in your clone. SolidWorks needs to know where they are, or the frame won't rebuild. This way needs no admin rights, so it also works on lab PCs.

1. Open SolidWorks and choose **Tools > Options > System Options > File Locations**.
2. In **Show folders for**, pick **Weldment Profiles**.
3. Click **Add** and choose your clone's `hardware\cad-2025-coop` folder (the one that contains `bakfiets_weldment_profiles`).
4. Click **OK**, then **Yes** if asked to confirm.

## 3. Open the bike

1. In SolidWorks, choose **File > Open**.
2. Go to your clone's `hardware\cad-2025-coop` folder and open `bakfiets_main_asm.SLDASM`.
3. If SolidWorks asks where a part is, point it at the same `cad-2025-coop` folder.

Every part follows one master sketch, `bakfiets_master_sketch.SLDPRT`. Change the sketch and the whole bike updates.

## 4. Learn the frame tools

- Weldments (how the frame is built): [Introduction to Weldments](https://www.youtube.com/watch?v=nbMxA178ADM) (CAD Decoded, 15 min)
- FEA (checking the frame is strong enough): [Static analysis for beginners](https://www.youtube.com/watch?v=Ys0eT57DzT4) (CAD Hub, 28 min)
- Tube mitering (shaping tube ends to fit): [How to miter bicycle tubes with a hand file](https://www.youtube.com/watch?v=mqS2rbv58Zs) (Cobra Framebuilding, 12 min)
- TIG welding chromoly, to understand the process only: [Learn how to TIG weld 4130 tubing](https://www.youtube.com/watch?v=nQ3bRaoMv74) (Miller, 3 min)

## 5. Where the 2024 files are

| Need | File in your clone |
| --- | --- |
| Whole 2024 bike | `hardware/cad-2024/Assem1.SLDASM` |
| Frame and its drawing | `hardware/cad-2024/Frame 2.0.SLDPRT`, `hardware/cad-2024/Frame 2.0-Sweep8.SLDDRW` |
| Welding jig | `hardware/cad-2024/jig/Jig/JigV2.SLDASM` |
| Notching guides | `hardware/cad-2024/notches/` |
| Steering | `hardware/cad-2024/steering system/steeringAssembly.SLDASM` |

Every file is explained in [`hardware/README.md`](../../hardware/README.md). Don't move or rename anything in `cad-2024` or `cad-2025-coop`; save your work in `hardware/cad-2026/` (create the folder if it's missing).

## 6. Pick a first task

See the [mechanical issues](https://github.com/Electrium-Mobility/Bakfiets-F26/issues?q=is%3Aissue+is%3Aopen+label%3Ahardware). Good first ones: #2 (photograph the frame) and #3 (list the parts).

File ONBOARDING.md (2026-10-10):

# Bakfiets F26 Onboarding

Last updated 2026-10-06 · Justin Gu, project lead

You're joining the team finishing an electric cargo bike. A bakfiets is a Dutch bike with a big box in front of the rider, and ours adds a motor, a 48 V battery, lights and a small screen. Electrium Mobility started it in Winter 2024 and partly built it, and the last recorded work was a CAD update in May 2025.

Tick the list below from top to bottom and you'll go from zero to your first contribution. Every file lives in this repo, and the [README](README.md) maps the folders.

You don't need to read every section. Read Getting Started and The Project, then only your own subteam's section, How to Submit and the term projects. Any word you don't know is in the [Glossary](#glossary) at the bottom.

SolidWorks render of the bakfiets with its wooden cargo box

*The 2024 design, from the club website. The rider sits at the back and the cargo box rides between the rider and the front wheel.*

## Your To-Do List

Setup takes about 2 to 3 hours in total, spread over a few days.

- [ ] **Mechanical:** you don't need SolidWorks on your own laptop, since the campus labs have it. If you want it on a Windows laptop, start that download first because it's large. On a Mac, use a lab PC ([Software](#software))
- [ ] Make a GitHub account and join the Discord ([Accounts and Discord](#accounts-and-discord))
- [ ] Post your GitHub username in the **Github usernames** thread, then keep going. Don't wait for a reply ([Accounts and Discord](#accounts-and-discord))
- [ ] Clone the repo with GitHub Desktop. About 60 MB, plus a 22 min video if Git is new to you ([Download the Files](#download-the-files))
- [ ] Install your subteam's software. This is most of your setup time. Firmware: also do Stage 1 steps 1 to 3 before the meeting ([Software](#software))
- [ ] Do WHMIS on LEARN (about 30 minutes) and post a screenshot of the certificate in the **Github usernames** thread ([Safety Training](#safety-training))
- [ ] Read the battery rules, about 5 minutes ([Safety Training](#safety-training), Step 3)
- [ ] Accept the GitHub invite to the repo when the email arrives ([Accounts and Discord](#accounts-and-discord))
- [ ] Come to the Wednesday meeting, 6:30 to 7:30 pm in the Electrium bay. The door has a code lock, and a lead lets you in ([Where the bike is](#step-4-know-where-the-bike-is-and-how-to-get-in))

After the meeting:

- [ ] Do your subteam's Stage 1: [Mechanical](#stage-1-open-the-bike) · [Electrical](#stage-1-read-a-real-board) · [Firmware](#stage-1-run-the-desk-demo)
- [ ] Finish one Stage 2 task, then move on to the [term projects](#after-onboarding-term-projects)

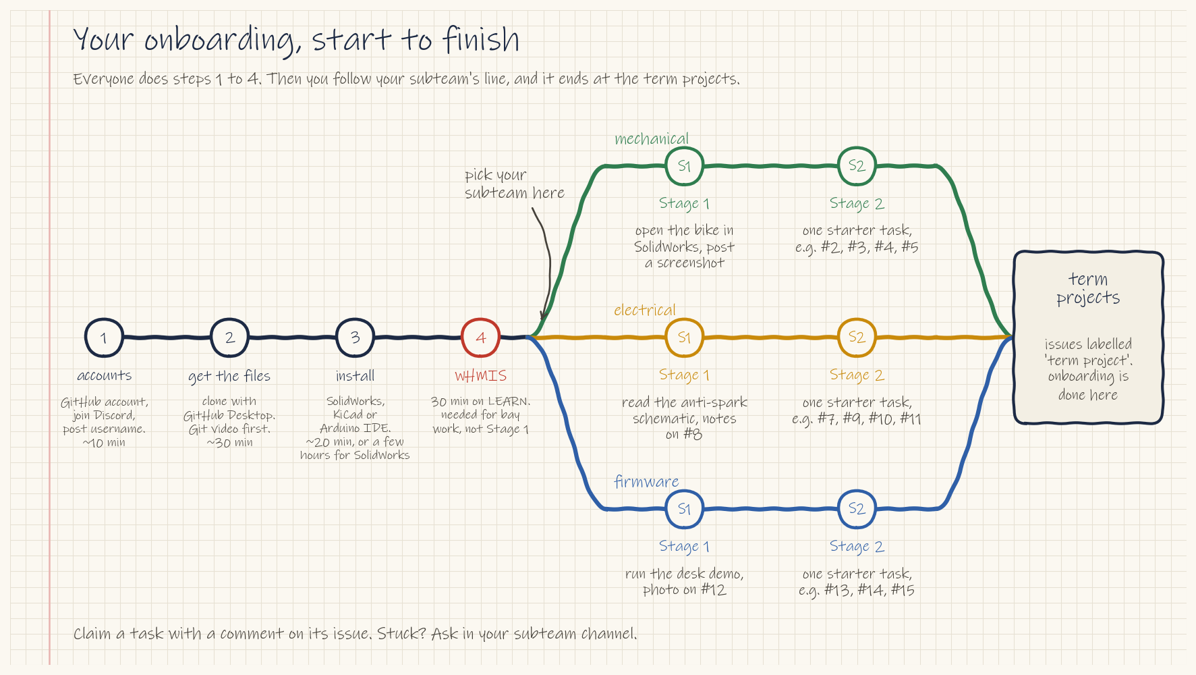
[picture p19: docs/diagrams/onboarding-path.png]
Onboarding path: accounts, files, software and WHMIS, then each subteam's Stage 1 and Stage 2, ending at the term projects


## Rules

These apply from day one.

1. Finish WHMIS and read the battery rules ([Safety Training](#safety-training)) before you use any tool or touch a battery.
2. Never work on a battery pack alone. Battery work always needs the electrical lead (Jack Huang) there.
3. Work on a branch and open a pull request. Never push straight to `main`.
4. One person edits a CAD file at a time: say which files you're changing on your issue. Git can't merge two edits to the same SolidWorks file.
5. Never move or rename files in `mechanical/cad-2024/` or `mechanical/cad-2025-coop/`. Assemblies find their parts by folder path, and moving a file breaks them.
6. Post questions in your subteam's Discord channel, not in DMs. That way one answer helps everyone.

## Getting Started

### Accounts and Discord

1. Make a free GitHub account at [github.com/signup](https://github.com/signup).
2. Join the Electrium Discord with the [club invite](https://discord.gg/jggFVza4XR).
3. Open the **Bakfiets F26** category. You'll use:
   - **#bakfiets-general** for the whole team, with the **Github usernames** thread inside it
   - **#bakfiets-mech**, **#bakfiets-elec** or **#bakfiets-firm** for your subteam's questions
   - **bakfiets**, the voice channel
4. Post your GitHub username in the **Github usernames** thread.
5. Go straight on to [Download the Files](#download-the-files). The repo is public, so you can download it and do all of setup and Stage 1 before anyone replies.
6. Later, GitHub emails you an invite to **Electrium-Mobility/Bakfiets-F26** once the project lead adds you. Click **View invitation**, then **Accept invitation**. This lets you upload your work.

**💡 Hint:** no invite accepted yet when you submit? Use the fork hint in [How to Submit](#how-to-submit).

### Download the Files

**New to Git?** Watch [Git, GitHub and GitHub Desktop for beginners](https://www.youtube.com/watch?v=8Dd7KRpKeaE) (22 min) first. The rest of this guide uses the words clone, branch and commit, and the video and the Glossary explain them.

1. Install [GitHub Desktop](https://desktop.github.com/) and sign in.
2. Choose **File > Clone repository > URL** and paste `Electrium-Mobility/Bakfiets-F26`.
3. Leave the local path as it is: `Documents\GitHub\Bakfiets-F26` on Windows, `Documents/GitHub/Bakfiets-F26` on a Mac.
4. Click **Clone** (about 60 MB).
5. Choose **Repository > Show in Explorer** (**Show in Finder** on a Mac). This folder is **your clone**. Every later step opens files from here, not from the GitHub website.

To get the team's latest changes later: click **Fetch origin**, then **Pull origin**. ("origin" just means the copy on GitHub.)

### Software

| Subteam | Install | Notes |
| --- | --- | --- |
| Mechanical | SolidWorks 2026 | You don't need to buy it: the campus labs Fulcrum, Helix, Lever and WEEF run 2026, and the SDC has a CAD studio for teams. If you'd rather have it on your own Windows laptop, SolidWorks sells a [student licence](https://www.solidworks.com/product/students) |
| Electrical | KiCad 9.0.9 (direct download for [Windows](https://downloads.kicad.org/kicad/windows/explore/stable/download/kicad-9.0.9-x86_64.exe) or [Mac](https://downloads.kicad.org/kicad/macos/explore/stable/download/kicad-unified-universal-9.0.9.dmg)) | Free. Use 9, not KiCad 10, because all the tutorial videos use 9. Install with the default libraries |
| Firmware | [Arduino IDE 2](https://www.arduino.cc/en/software) with ESP32 support | Free. Follow [this written guide](https://randomnerdtutorials.com/installing-esp32-arduino-ide-2-0/) to add ESP32 boards |

**On a Mac:** GitHub Desktop, KiCad and Arduino IDE all have Mac versions, so electrical and firmware setup work the same way. Under **Tools > Port**, the board shows up as `/dev/cu.usbmodem…` instead of a COM port. SolidWorks doesn't run on a Mac, so mechanical members use a lab PC or pair up with someone at the meeting.

**On a lab PC:** you don't need GitHub Desktop to open the model. On the [repo page](https://github.com/Electrium-Mobility/Bakfiets-F26), click the green **Code** button, then **Download ZIP**. Unzip it to your N: drive so it isn't wiped when you log out, and use that folder as your clone for Stage 1. To submit work later, copy your new files to your own laptop and use GitHub Desktop there.

**⚠️ Warning:** the team uses SolidWorks **2026** and KiCad **9**. A SolidWorks 2026 file can't be opened in an older version, so don't install an older one. A file saved in KiCad 10 can't be opened in KiCad 9, so don't upgrade to 10.

### Prerequisites

You don't need any experience. Each Stage 1 teaches its own tools. If a basic idea below is new, the video next to it covers it.

| Subteam | What to know | Video |
| --- | --- | --- |
| Mechanical | Making a part in SolidWorks (you'll open an assembly in Stage 1) | [Your First Part](https://www.youtube.com/watch?v=qjtYqxNpj50) (8 min) |
| Electrical | Ohm's law, and what series and parallel mean | [Batteries in series vs parallel](https://www.youtube.com/watch?v=5lBDdcF6eAk) (3 min) |
| Firmware | Basic C or C++: variables, loops, functions | [Arduino Tutorial 1 for absolute beginners](https://www.youtube.com/watch?v=fJWR7dBuc18) (24 min) |

### Safety Training

You can start setup, CAD and code right away. Finish the training below before you use tools or touch a battery.

#### Step 1: Do WHMIS (about 30 minutes)

1. Go to [LEARN](https://learn.uwaterloo.ca/) > Self Registration and take **WHMIS 2015** (course code **SO2017**). Details are on the [Safety Office page](https://uwaterloo.ca/safety-office/training/student-safety-orientation-whmis).
2. Post a screenshot of the certificate in the **Github usernames** thread, with your student number cropped out. That tells the leads you've done it.

You need WHMIS for any hands-on work in the shop or our bay: tools, batteries, the bike. You can attend meetings without it. WHMIS isn't battery training: any battery work also needs the electrical lead there. Renew it every 5 years.

#### Step 2: Check the other trainings

Do these only when you need the place or machine they cover. No onboarding task needs welding or the laser cutter.

| Training | Needed for | Where |
| --- | --- | --- |
| Engineering Student Machine Shop Orientation | The Engineering Student Shops. You get an access card afterwards | LEARN. Score 100% on each module quiz ([Student Shops page](https://uwaterloo.ca/engineering-student-shops/getting-started)). Shop hours this term: 8:30 am to 4:30 pm, Monday to Friday, plus every second Saturday |
| Welding | The SDC welding room | Run by the MME department's new welding lab. Everyone, including previously approved welders, must pass the weld test before using the room |
| Laser cutter | Only that machine | Hands-on, from the shop that runs it |

#### Step 3: ⚠️ Learn the battery rules

From the UW [Lithium Cell and Battery Standard](https://uwaterloo.ca/safety-office/laboratory-safety/batteries), plus common practice:

1. Wear safety glasses, take off rings and watches, use insulated tools, and tape over bare terminals.
2. Store packs in a metal box or battery cabinet. A LiPo bag is too small for a 24-cell e-bike pack.
3. Charge on a non-combustible surface (concrete or a metal tray) away from anything that burns. Stay with a pack the whole time it charges, and unplug it once it's full.
4. Use only a charger marked 12S with a 50.4 V output (12S means 12 cell groups in series). Our pack reaches 50.4 V when full, and UW's standard calls for extra safety steps at 50 V and above. That's why battery work always needs the electrical lead there.
5. Pack 4 is the pack we use. Ling says it's working and still has charge. Look it over before using it, and only use it wired through the BMS, a fuse and the antispark ([#21](https://github.com/Electrium-Mobility/Bakfiets-F26/issues/21)).
6. Never use a swollen or damaged pack.
7. If a pack gets hot, smells or smokes, get everyone away and pull the fire alarm if there's fire. Then tell the electrical lead and the project lead.
8. Every pack goes on the SDC's shared battery and chemical inventory sheet, which the SDC is setting up this term.

#### Step 4: Know where the bike is and how to get in

1. **Where:** the Electrium bay (workbay 1002 on SDC sheets), in the Sedra Student Design Centre (SDC) in Engineering 5. The bike frame, the cargo box, the battery packs, the hub motor and the ESP32 boards (on the black parts organizer) are all there.
2. **Meetings:** the bay door has a code lock, and only leads have the code. A lead lets you in. Post in #bakfiets-general when you get to the door.
3. **Other times:** arrange bay work with your subteam lead in your subteam channel.
4. **If you ever learn the code:** don't pass it on. The bay holds items that can hurt someone who doesn't know them.

#### Step 5: Follow the SDC house rules

1. The four shared SDC rooms use sign-up sheets. Book before you use one and leave it tidy.
2. Put work tables away when it isn't busy.
3. Keep our bay clean. Electrium's safety captain, Ayaan Salim, inspects it in the first week of each month.

## The Project

### Where It Stands

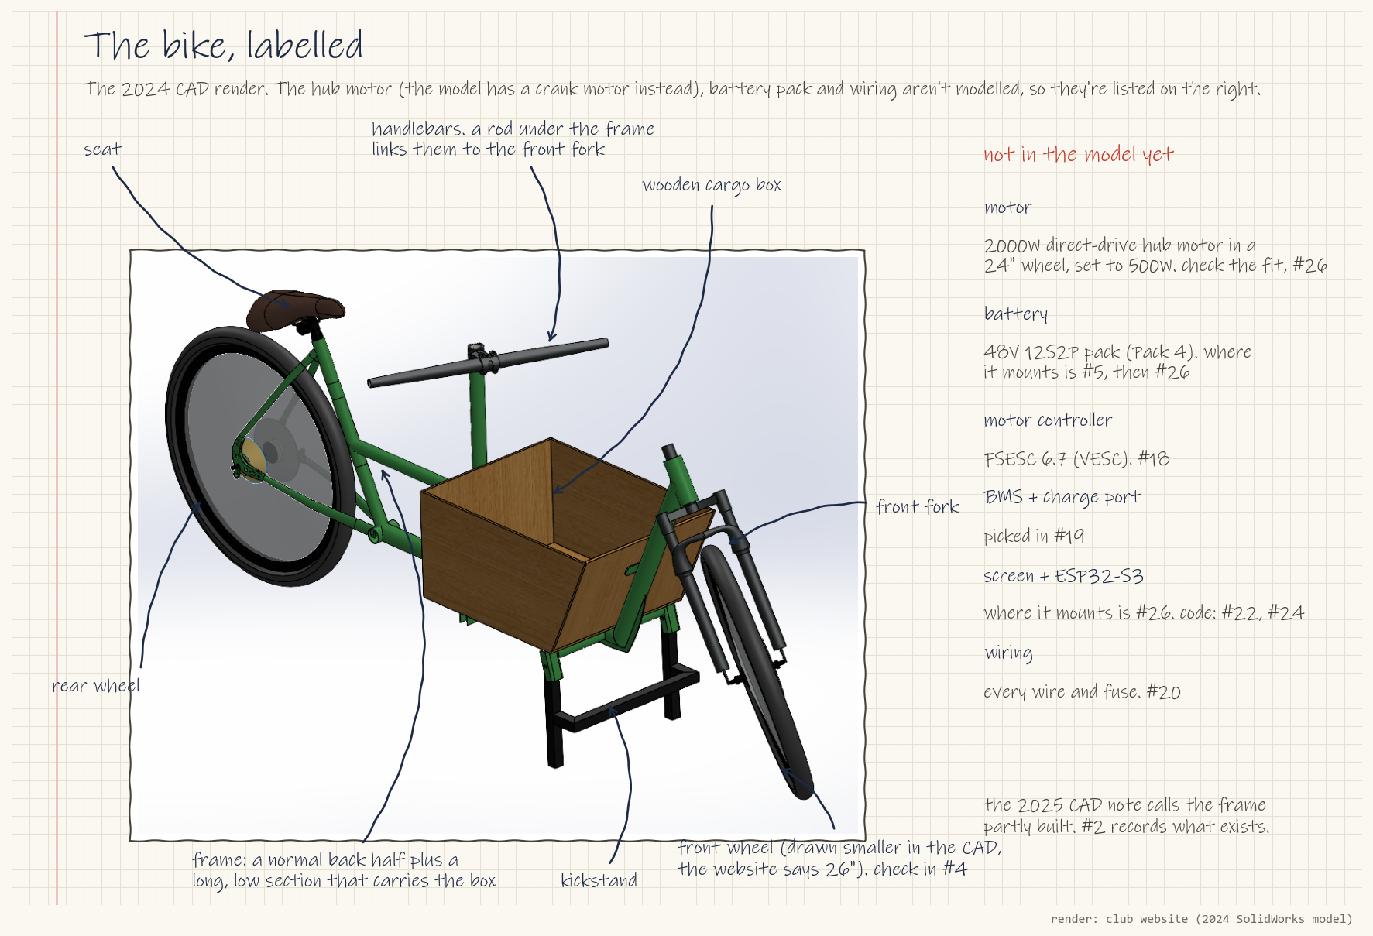
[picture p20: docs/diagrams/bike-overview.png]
The 2024 CAD render with each part labelled, and a list of what is not in the model yet


| Area | What exists | Next milestone |
| --- | --- | --- |
| Mechanical | A SolidWorks model, a welding jig, notching guides, one FEA study and a partly built frame | Record what is welded, then rerun FEA with written load cases |
| Electrical | A power flow diagram, a 48 V battery pack (Pack 4) and a 2000 W hub motor, both in the bay. The 2024 schematics aren't in any Electrium repo | Get Pack 4 ready (#21), bench test the motor (#18), then draft the power board schematic |
| Firmware | A screen and LED demo with fixed numbers, and ESP32 boards in the bay (no screens yet, we'll probably buy some) | Show a real battery voltage and one working button |

Photos of everything in the bay (motor, controller, packs, ESP32 boards) are in [docs/photos/bay-2026-10](docs/photos/bay-2026-10/README.md).

### Open Questions

The 2024 files disagree on a few basics. Below is the answer we're working from for each, and how we know. Until a check says otherwise, plan around these answers. This section is background: you don't need to follow every detail yet, and the [Glossary](#glossary) explains the terms.

#### 1. Which motor does the bike have?

- **Decided (6 Oct):** a 48 V, 2000 W direct-drive hub motor, already built into a 24" wheel, driven by a VESC-based motor controller (the club website names the Flipsky FSESC 6.7).
- **Why:** it was found in the bay ([#1](https://github.com/Electrium-Mobility/Bakfiets-F26/issues/1)) and it drives the wheel directly. The other motor in the bay, a Flipsky 6374 skateboard motor, would need about a 30:1 gear reduction. The 2024 README and crank-motor CAD (`mechanical/cad-2024/MotorCrank/`) mention a Bafang BBS02 mid-drive, but no mid-drive was found in the bay.
- **The power limit:** we'll set the motor controller to 500 W and 32 km/h in VESC Tool ([#18](https://github.com/Electrium-Mobility/Bakfiets-F26/issues/18)). Ling (Electrium team lead) has okayed using this motor. Running it below its 2000 W rating also saves battery.
- **Still to check:** that the 24" wheel fits the frame's dropouts ([#26](https://github.com/Electrium-Mobility/Bakfiets-F26/issues/26)), and the motor controller's label against the FSESC 6.7 ([#18](https://github.com/Electrium-Mobility/Bakfiets-F26/issues/18)).

#### 2. Which microcontroller runs the screen?

- **Our answer:** an ESP32-S3.
- **Why:** the 2024 website says "ESP32 S3 Pico", and the display code uses GPIO 9 and 10, which a plain ESP32 can't use because they connect to its flash chip. The November 2024 CAN test code targets a plain ESP32 dev board.
- **How to check:** the board test (Firmware Stage 1, step 4) uploads to the board, which only works if it's an ESP32-S3.
- **If we're wrong:** the screen and LED pins in the desk demo would need to move to other GPIOs.

#### 3. What happened to the 2024 electrical design?

- **Our answer:** nothing beyond the block diagram was saved, so this term designs the power board and wiring from scratch.
- **Why:** no schematic, PCB or pack file for the bakfiets exists in any Electrium repo. The only electrical file is the block diagram redrawn in Electrical Onboarding.
- **How to check:** photograph any boards, pack or wiring still on the bike ([issue #7](https://github.com/Electrium-Mobility/Bakfiets-F26/issues/7)). Anything found becomes a reference, not a finished design.
- **If we're wrong:** nothing is lost. A found board saves time, but the new design still has to be rated for the 50.4 V pack.

#### 4. How much of the frame is built?

- **Our answer:** partly. The May 2025 CAD note calls the bike partially built. No model has a battery mount, and none of the cargo box versions is marked final.
- **Why:** the latest note, from the May 2025 CAD rebuild, calls the bike "partially built" and models it that way.
- **How to check:** photograph the frame and list which joints are welded ([issue #2](https://github.com/Electrium-Mobility/Bakfiets-F26/issues/2)), then measure it against the CAD ([issue #4](https://github.com/Electrium-Mobility/Bakfiets-F26/issues/4)).
- **If we're wrong:** the mechanical plan shifts between finishing the welds and starting over on parts of the frame. Nothing gets cut or welded until the FEA check ([issue #6](https://github.com/Electrium-Mobility/Bakfiets-F26/issues/6)) is done either way.

### Who Leads What

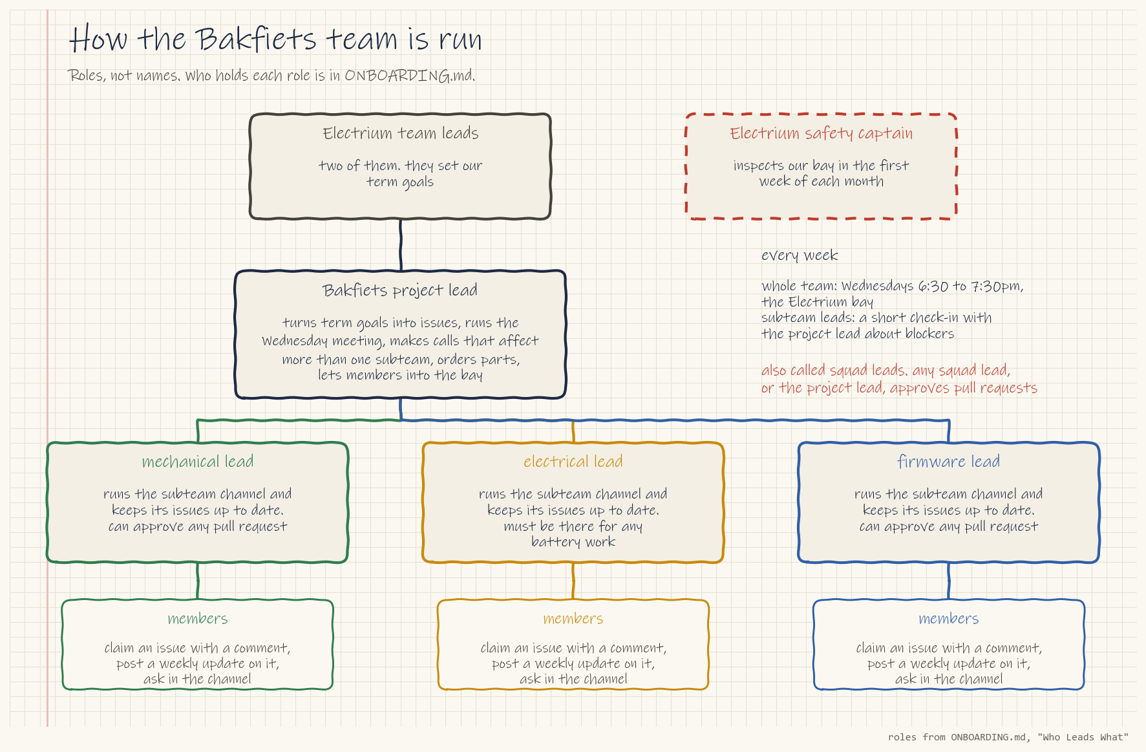
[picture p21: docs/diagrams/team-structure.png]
Team structure: Electrium leadership and safety captain, the project lead, three subteam leads, and members


| Role | Person | What they do |
| --- | --- | --- |
| Project lead | Justin Gu | Priorities, decisions that affect more than one subteam, purchases (through Electrium's ordering process, about $300 for this term, mostly for steering) and letting members into the bay |
| Mechanical leads | Annie Luangphinith and Aarush Lingamchetti (co-leads) | Run #bakfiets-mech and keep mechanical issues current |
| Electrical lead | Jack Huang | Runs #bakfiets-elec, keeps electrical issues current, and supervises all battery work |
| Firmware lead | David Ertel | Runs #bakfiets-firm and keeps firmware issues current |

The subteam leads are also called squad leads, and they were chosen at the 2026-09-30 meeting. Any squad lead, or the project lead, can approve a pull request in any part of the repo. The whole team meets **Wednesdays, 6:30 to 7:30 pm, in the Electrium bay (workbay 1002)**. Design reviews and team decisions happen there. Subteam leads also meet the project lead briefly each week to raise blockers. The first team meeting was on 2026-09-23. Agendas and notes from 2026-09-30 on are in [docs/meetings/](docs/meetings/).

**How work flows:** you claim a task by leaving a comment on its GitHub issue saying you're working on it. Nobody needs to assign you. Read the issue's comments first. If someone has already claimed it, pick another one or ask in your subteam channel to pair up. The Stage 1 issues (#8 and #12) are for everyone, so post there without claiming. You post a short update on your issue each week: what you did, what's next, and anything blocking you. Anyone can comment on a pull request, and a squad lead or the project lead approves it.

## Mechanical Onboarding

You will open the bike in SolidWorks, then make your first contribution to it. Mechanical is the furthest along: the model exists and the frame is partly built. What's missing is a battery mount, a finished cargo box and a written strength check.

Four CAD views: full 2024 bike, 2025 co-op assembly, bare frame, frame with cargo box

*(1) The 2024 model of the whole bike. (2) The May 2025 model, which its author says models the partly built frame. (3, 4) The frame: a normal rear half plus a long, low section that carries the box.*

### Stage 1: Open the Bike

No hardware needed: do all of Stage 1 on your own laptop or a lab PC.

#### Task

Open the newest model of the bike, `bakfiets_main_asm.SLDASM`, with every part loaded. You're done when the whole bike is on screen and the list of parts on the left (the FeatureManager tree) has no red or yellow warning icons.

#### Steps

1. With SolidWorks 2026 installed (see Software), tell SolidWorks where the custom tube shapes are. Choose **Tools > Options > System Options > File Locations**, set **Show folders for** to **Weldment Profiles**, click **Add**, and choose your clone's `mechanical\cad-2025-coop` folder. Click **OK**. This needs no admin rights.
2. Choose **File > Open** and open `mechanical\cad-2025-coop\bakfiets_main_asm.SLDASM` from your clone.

**💡 Hint:** if SolidWorks asks where a part is, point it at the same `cad-2025-coop` folder. When you close the model, SolidWorks may ask to save: click **Don't Save**. Saving converts the team's files to the 2026 format, and that folder stays unchanged. If the frame still shows red or yellow icons, copy the `bakfiets_weldment_profiles` folder into the default Weldment Profiles folder listed in that same File Locations dialog. That needs admin rights, so on a lab PC post a screenshot in #bakfiets-mech instead.

First time in SolidWorks? Watch [Your First Part](https://www.youtube.com/watch?v=qjtYqxNpj50) (8 min), then [Introduction to Weldments](https://www.youtube.com/watch?v=nbMxA178ADM) (15 min), which shows how tube frames are built.

#### Deliverable

A screenshot of the full assembly open in SolidWorks, posted in the **#bakfiets-mech** channel.

### Stage 2: First Contribution

#### Task

Pick one of these and claim it with a comment on the issue saying you're working on it. Steering, brakes and the motor fit come first. Two or more people on one issue is fine.

| Issue | What you'll do |
| --- | --- |
| [#25](https://github.com/Electrium-Mobility/Bakfiets-F26/issues/25) | Compare rod, cable and hydraulic steering, then design the one we pick. Top priority |
| [#32](https://github.com/Electrium-Mobility/Bakfiets-F26/issues/32) | Pick brakes that fit the frame, with levers that cut the motor. The bike has none |
| [#31](https://github.com/Electrium-Mobility/Bakfiets-F26/issues/31) | Check the hub motor wheel fits the frame and pick torque arms (safety training first) |
| [#2](https://github.com/Electrium-Mobility/Bakfiets-F26/issues/2) | Photograph the real frame and record which joints are welded (safety training first, look only) |
| [#4](https://github.com/Electrium-Mobility/Bakfiets-F26/issues/4) | Measure the real frame against the CAD, with a mechanical lead (after #2, safety training first) |
| [#5](https://github.com/Electrium-Mobility/Bakfiets-F26/issues/5) | Sketch two battery mount options for Pack 4 |
| [#3](https://github.com/Electrium-Mobility/Bakfiets-F26/issues/3) | List every part in the co-op model, with its material and whether we own it |

#### Constraints

| Requirement | Value |
| --- | --- |
| Software | SolidWorks 2026 |
| Where new files go | `mechanical/cad-2026/` (create it if it's missing) |
| Frozen folders | Never edit, move or rename anything in `cad-2024` or `cad-2025-coop` |
| Fabrication | Nothing goes out for cutting or welding until #6 is done and the mechanical lead and project lead approve it. Welders must have passed the SDC weld test |

**Changing the model:** copy what you need into `mechanical/cad-2026/` with **File > Pack and Go** (see the Glossary), add a prefix so names don't clash, and work on the copy. A plain Explorer copy can still point at the originals. Every part follows one master sketch, `bakfiets_master_sketch.SLDPRT`, so changing it moves the whole bike.

#### Deliverables

A pull request ([How to Submit](#how-to-submit)) that includes your files, says `Closes #<issue number>`, and has screenshots in its description. Photos and measurement notes can go straight into the issue instead: open the issue, drag your photos into the comment box at the bottom, add a line or two, and click **Comment**.

### Reference

| What | File in your clone |
| --- | --- |
| Newest whole bike | [`mechanical/cad-2025-coop/bakfiets_main_asm.SLDASM`](mechanical/cad-2025-coop/bakfiets_main_asm.SLDASM) |
| 2024 whole bike | [`mechanical/cad-2024/Assem1.SLDASM`](mechanical/cad-2024/Assem1.SLDASM) |
| 2024 frame | [`mechanical/cad-2024/Frame 2.0.SLDPRT`](mechanical/cad-2024/Frame%202.0.SLDPRT) and its drawing [`Frame 2.0-Sweep8.SLDDRW`](mechanical/cad-2024/Frame%202.0-Sweep8.SLDDRW) |
| Tube sizes | [`mechanical/cad-2024/Weldment Cross-section/`](mechanical/cad-2024/Weldment%20Cross-section) |
| Steering | [`mechanical/cad-2024/steering system/`](mechanical/cad-2024/steering%20system) |
| Welding jig and laser-cut files | [`mechanical/cad-2024/jig/Jig/`](mechanical/cad-2024/jig/Jig) |
| Printable notching guides | [`mechanical/cad-2024/notches/`](mechanical/cad-2024/notches) |
| Every file, explained | [`mechanical/README.md`](mechanical/README.md) |

Steering assembly, steering plate, ball joint and kickstand from the CAD

*How the steering works: the handlebars turn a plate under the frame. A rod with a ball joint at each end (3) pushes a plate on the fork, so the front wheel turns. The kickstand (4) sits under the box.*

Welding jig, laser-cut jig base, notching guides on tubes, single printed notching guide

*How the 2024 team set up the frame build. A laser-cut wooden jig (1, 2) holds the tubes for welding. 3D-printed guides (3, 4) mark where to cut each tube end.*

Other Electrium teams have solved similar problems: the [longtail cargo frame](https://github.com/Electrium-Mobility/longtail-conversion-kit/tree/main/Mechanical/LongtailFrameV7) has drawings and printable weld angle blocks, and the [vroom battery box](https://github.com/Electrium-Mobility/vroom_mechanical/tree/main/Mechanical/Battery%20Box) shows a BMS mount for issue #5. The full list is in [docs/reference-projects.md](docs/reference-projects.md).

## Electrical Onboarding

You will learn to read a real Electrium board, then help design the bike's electrical system from scratch. The 2024 schematics aren't in any Electrium repo, so this term starts fresh.

### Background: How Power Flows

How power flows through the bakfiets: battery side, motor and power board, low-voltage electronics

*Thick red lines carry full battery voltage (about 36 to 50 V). Orange lines carry 5 V. Dashed blue lines are signals only.*

1. **Charger** plugs into a charging port on the frame and fills the pack to 50.4 V.
2. **Battery pack**: Pack 4, a 48 V pack labelled 12S2P. That's 12 groups wired in series, with 2 cells in parallel in each group: 24 cells, about 44 V in normal use. "48 V" is just the name shops use for packs this size. [#21](https://github.com/Electrium-Mobility/Bakfiets-F26/issues/21) confirms the 12S by counting the balance wires before anyone uses it. The drawing under this list shows how the cells connect. The positive side goes through a fuse (DC-rated for 60 V or more).
3. **BMS** (battery management system) sits on the pack's negative side, so both charging and riding current pass through it. It cuts the pack off on overcharge, over-discharge, overheating or a short.
4. **Antispark**: the power button switches it on, and it lets power in slowly so the controller's capacitors charge without a spark. *Design note for later, not needed for Stage 1:* the Electrium anti-spark board you read in Stage 1 uses N-channel MOSFETs, which usually means it switches the negative wire. Check that in its schematic. If it does switch the negative wire, the power board and the ESP32 must take their negative from the switched side too. Otherwise the ESP32's ground wire to the controller becomes a path around the antispark, which can damage the controller's COMM port or the ESP32.
5. **Motor controller (ESC)** turns battery power into the three motor wires. The throttle sends it a speed request, and the brake levers tell it to cut power.
6. **Power board (PDB)** steps 48 V down to 5 V for the small electronics and lights.
7. **ESP32-S3** runs the display and LED strip, reads the buttons, and gets speed and battery data from the controller over UART.

A 12S2P pack seen from above: 12 groups of 2 cells, voltages adding up to about 44 V, and 13 balance wires to the BMS

**⚠️ Warning:** you'll need this when you choose parts (issue #9 onward), not for Stage 1. Parts that carry the battery voltage need margin above 50.4 V: use MOSFETs and capacitors rated 100 V. Surge (TVS) diodes are the exception: pick one whose standoff voltage sits just above 50.4 V, about 54 to 58 V. Then check its clamp voltage: a 54 to 58 V part clamps at roughly 87 to 94 V, which is why the MOSFETs need 100 V and not 80 V. Fuses on the battery side must be DC-rated for at least 60 V, because ordinary car blade fuses are rated only 32 V.

### Stage 1: Read a Real Board

No hardware needed: do all of Stage 1 on your own laptop.

#### Task

Read the 2023 [anti-spark](https://github.com/Electrium-Mobility/anti-spark) schematic and explain how it works. It's a small, real Electrium board: 18 parts, with three 100 V MOSFETs. You need KiCad 9 installed first (see Software).

Watch first: [MOSFET as a switch](https://www.youtube.com/watch?v=o4_NeqlJgOs) (6 min) and part 1 of [KiCad 9 Getting Started](https://www.youtube.com/watch?v=0WCi1rhueH4) (4 min). [What a BMS does](https://www.youtube.com/watch?v=rT-1gvkFj60) (13 min) helps too.

#### Steps

1. In GitHub Desktop, choose **File > Clone repository > URL** and paste `Electrium-Mobility/anti-spark`.
2. In KiCad, choose **File > Open Project** and pick `Anti-Spark Switch.kicad_pro` in your `anti-spark` folder.
3. KiCad says the project is from an older version and offers to upgrade it. Click OK. GitHub Desktop will then show those files as changed. That's normal: leave them, and don't commit them.
4. In the left panel, double-click `Anti-Spark Switch.kicad_sch`.
5. Find the three MOSFETs, labelled Q1, Q2 and Q3. Then trace where the battery connects: follow the wires from the battery connector with your eye.

**💡 Hint:** if you open the PCB, KiCad warns that the `XT60PW-F` footprint library is missing. The 2023 designer kept it on their own computer. It doesn't affect the schematic.

#### Deliverable

A comment on [issue #8](https://github.com/Electrium-Mobility/Bakfiets-F26/issues/8) that explains, in your own words, what each MOSFET does and what happens when the battery is plugged in. Four to six sentences is enough, and questions are welcome if part of it doesn't make sense.

### Stage 2: First Contribution

#### Task

Pick one of these and claim it with a comment on the issue saying you're working on it. Two or more people on one issue is fine. Getting Pack 4 ready ([#21](https://github.com/Electrium-Mobility/Bakfiets-F26/issues/21)) is run by the electrical lead.

| Issue | What you'll do |
| --- | --- |
| [#18](https://github.com/Electrium-Mobility/Bakfiets-F26/issues/18) | Bench test the motor controller and hub motor on a bench power supply (safety training first) |
| [#19](https://github.com/Electrium-Mobility/Bakfiets-F26/issues/19) | Check the BMS and charger we have suit Pack 4 |
| [#10](https://github.com/Electrium-Mobility/Bakfiets-F26/issues/10) | Redraw the block diagram with real connectors and wire sizes |
| [#11](https://github.com/Electrium-Mobility/Bakfiets-F26/issues/11) | Start the parts list (BOM) |
| [#9](https://github.com/Electrium-Mobility/Bakfiets-F26/issues/9) | List what the 2026 power board needs changed for our pack. Do Stage 1 first |

#### Constraints

| Requirement | Value |
| --- | --- |
| Software | KiCad 9, or [draw.io](https://app.diagrams.net/) for diagrams |
| Voltage rating | MOSFETs and capacitors on the battery side rated 100 V. TVS diode standoff about 54 to 58 V, with its clamp voltage below 100 V. Fuses DC-rated for at least 60 V |
| Where new files go | `electrical/` in the Bakfiets-F26 repo (the BOM goes in `docs/BOM.md`) |
| Battery work | Only with the electrical lead present, after WHMIS (SO2017) |

#### Deliverables

A pull request with your files ([How to Submit](#how-to-submit)), or photos and notes posted in the issue. Say `Closes #<issue number>` in the pull request.

### Reference

| Resource | What you'll learn |
| --- | --- |
| [Motor controller connections](electrical/diagrams/motor-controller-connections.png) | What plugs into the FSESC 6.7: battery chain, motor, throttle and ESP32 |
| [`electrical/README.md`](electrical/README.md) | Everything known about the bike's electrical system |
| [anti-spark](https://github.com/Electrium-Mobility/anti-spark) | Your Stage 1 board |
| [power-distribution-antispark](https://github.com/Electrium-Mobility/power-distribution-antispark) | A 2026 Electrium 48 V power board with an antispark. Its 60 V MOSFETs and SMCJ48CA surge diode are rated too low for a 50.4 V pack, so treat it as a design reference |
| [esc-w26](https://github.com/Electrium-Mobility/esc-w26) | A well-documented board with input protection explained |
| [F25 Skateboard write-up](https://github.com/Electrium-Mobility/electrium-w24website/blob/main/docs/F2025-projects/F25%20Skateboard.md) | A finished Electrium project with a 12S pack, BMS and power board |

More videos: [soldering](https://www.youtube.com/watch?v=QKbJxytERvg) (5 min), [multimeter](https://www.youtube.com/watch?v=SLkPtmnglOI) (11 min), [buck converter](https://www.youtube.com/watch?v=m8rK9gU30v4) (6 min), [VESC Tool setup](https://www.youtube.com/watch?v=YFl3VvZTRb0) (23 min).

Photos from the F25 skateboard and esc-w26: a pack being built, the finished pack, custom PCBs, an ESC render

*Finished electrical work on this team: a pack being built, the finished pack and custom PCBs from the F25 skateboard, plus the esc-w26 board.*

## Firmware Onboarding

You will get the 2024 display code running on your desk, then start connecting it to real data. Right now the screen shows fixed numbers. By the end of the term it should show the real speed and battery level from the motor controller.

Hand-drawn screen layout: battery bar at 80%, speed 30 km/h, PA 3

*The screen layout the 2024 team drew: battery top left, speed bottom left, pedal-assist (PA) level on the right.*

### Stage 1: Run the Desk Demo

**This stage is split in three.** Steps 1 to 3 need no hardware: do them on your own laptop, then click **Verify** (the checkmark button, top left) to check the code builds. Step 4 needs only a board, which you borrow in the bay. Steps 5 to 7 need a screen too. Electrium may not have spares, so we'll probably buy a few. Do those steps once they arrive.

#### Task

Run [`firmware/desk-demo/desk-demo.ino`](firmware/desk-demo/desk-demo.ino) on an ESP32-S3 with a screen attached.

#### Materials

| Part | Notes |
| --- | --- |
| ESP32-S3 dev board, such as the ESP32-S3-DevKitC-1 | Borrow one from the black parts organizer in the bay. Electrium's boards are ESP32-S3-DevKitC-1 ([photo](docs/photos/bay-2026-10/esp32-s3-devkitc-1-box.jpg)), the board this guide is written for |
| SSD1306 128x64 I2C OLED (the common 0.96-inch screen) | We'll probably buy a few, since Electrium may not have spares. Don't buy your own |
| 4 female-to-female jumper wires, and a USB-C data cable | Ask for the wires with the board. Charge-only cables don't work. No LED strip is needed |
| For Stage 2: a push button, a breadboard and a few resistors | Needed for #14 and #15. #15 also uses a bench power supply |

#### Steps

1. With Arduino IDE and ESP32 support installed (see Software), choose **Tools > Manage Libraries** and install **Adafruit SSD1306** and **FastLED**. Click **Install all** when asked, which adds Adafruit GFX and BusIO too. The code needs FastLED to build even without an LED strip.
2. Choose **File > Open** and pick `firmware\desk-demo\desk-demo.ino` in your clone.
3. Choose **Tools > Board > esp32 > ESP32S3 Dev Module**, and set **Tools > USB CDC On Boot** to **Enabled**. Click **Verify** now. The first build can take a few minutes, and it worked when the bottom panel says **Done compiling**. If it says a `.h` file is missing, redo step 1.
4. **Board test, no screen needed.** Open [`firmware/board-test/board-test.ino`](firmware/board-test/board-test.ino). Plug the board in with the USB-C port labelled **USB** (not UART), and pick its COM port under **Tools > Port**. Not sure which one? Unplug the board and look again: the one that disappears is yours. Click **Upload**, then open **Tools > Serial Monitor** and set the speed at the bottom right to **115200**. Every second it prints a line such as `Hello from Bakfiets! Chip: ESP32-S3`. If the upload fails with "This chip is ESP32, not ESP32-S3" (or another chip name), that board isn't an S3, so swap it.
5. Once you have a screen, wire it: VCC to 3.3 V, GND to GND, SDA to GPIO 10, SCL to GPIO 9, as in the drawing below. The drawing shows an ESP32-S3-DevKitC-1. On any other S3 board, go by the GPIO labels printed on the board, and if it has only one USB port, use that one.

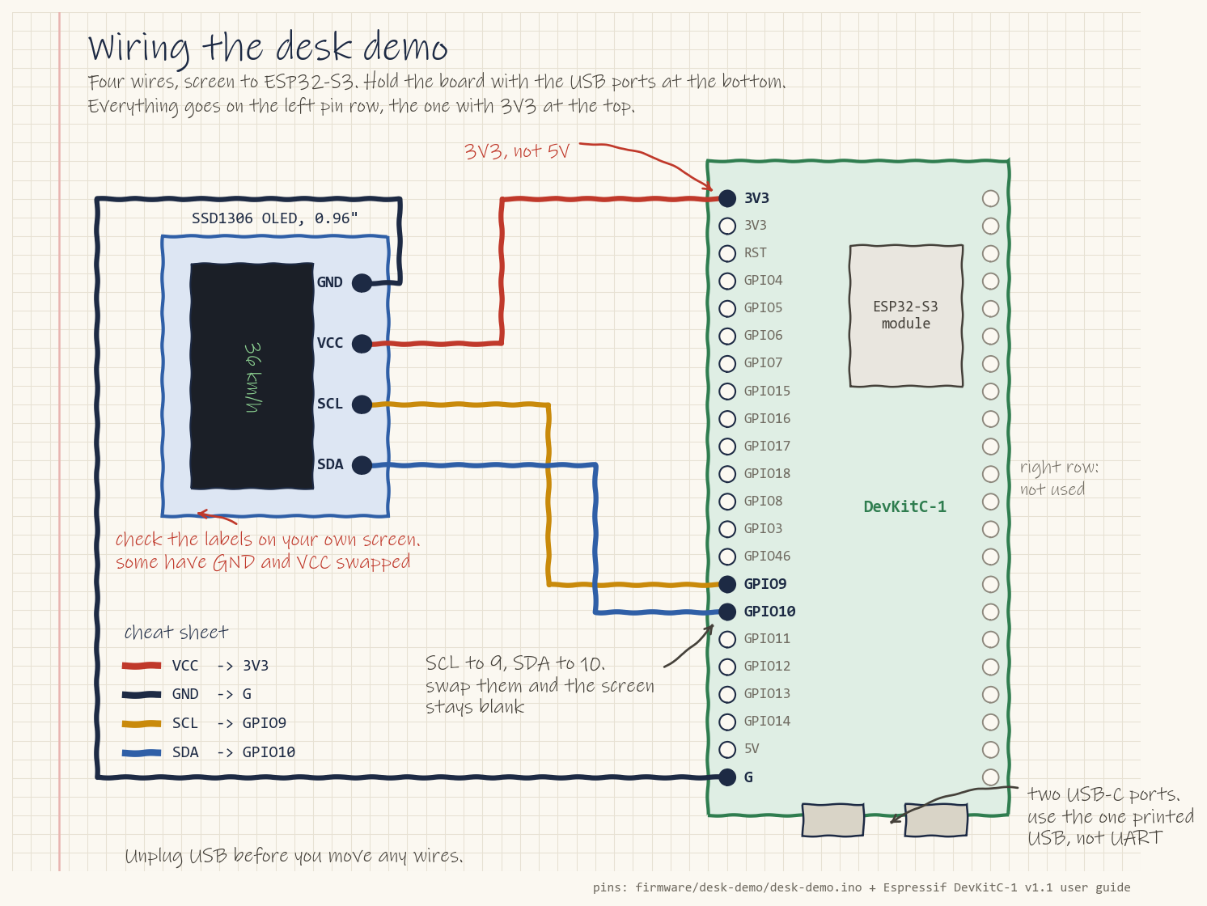
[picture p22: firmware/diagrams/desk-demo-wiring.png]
Desk demo wiring: four wires from the OLED screen to the ESP32-S3-DevKitC-1
   

6. Open `firmware\desk-demo\desk-demo.ino` again and plug the board in the same way as step 4.
7. Click **Upload**. After about 10 seconds the screen shows 50%, 36 km/h and PA 5. It stays blank at first because the code plays the LED animation before it draws.

**💡 Hint:** upload says "Failed to connect"? Hold **BOOT**, tap **RST**, release BOOT, and upload again. No COM port? Try another cable, since some only charge. If you're on the port labelled UART instead, install the CP210x or CH340 USB driver and set USB CDC On Boot to **Disabled**. Blank screen? Check SDA and SCL. Then, near the top of `desk-demo.ino`, change `#define SCREEN_ADDRESS 0x3C` to `0x3D` and upload again.

Video: [ESP32 OLED tutorial for beginners](https://www.youtube.com/watch?v=u8g34BS8Ouw) (17 min).

#### Deliverable

For now, a screenshot of the Serial Monitor from step 4, showing the chip name, posted on [issue #12](https://github.com/Electrium-Mobility/Bakfiets-F26/issues/12). Once you have a screen, add a photo of it showing 50%, 36 km/h and PA 5.

### Stage 2: First Contribution

#### Task

Pick one of these and claim it with a comment on the issue saying you're working on it. Two or more people on one issue is fine.

| Issue | What you'll do |
| --- | --- |
| [#22](https://github.com/Electrium-Mobility/Bakfiets-F26/issues/22) | Read speed and battery data from the motor controller (VESC) over UART |
| [#23](https://github.com/Electrium-Mobility/Bakfiets-F26/issues/23) | Decide whether the bike needs a screen, and which one |
| [#13](https://github.com/Electrium-Mobility/Bakfiets-F26/issues/13) | Stop the LED animation from freezing the code, using `millis()` ([video](https://www.youtube.com/watch?v=BYKQ9rk0FEQ), 14 min) |
| [#14](https://github.com/Electrium-Mobility/Bakfiets-F26/issues/14) | Add a button that changes the PA level |
| [#16](https://github.com/Electrium-Mobility/Bakfiets-F26/issues/16) | Compare one ESP32 with two boards linked by CAN bus, and post a pros and cons list |
| [#15](https://github.com/Electrium-Mobility/Bakfiets-F26/issues/15) | Show a real battery voltage, read through a voltage divider (needs a bench supply and the electrical lead) |

#### Constraints

| Requirement | Value |
| --- | --- |
| Board | ESP32-S3 |
| Pins | Screen SDA GPIO 10, SCL GPIO 9. LED strip GPIO 5. Motor controller UART (suggested) TX GPIO 17, RX GPIO 18 |
| Loop timing | No `delay()` longer than 20 ms in `loop()` |
| Where new code goes | A new folder, such as `firmware/display-2026/`. To make it, open the desk demo, choose **File > Save As**, and save it as `display-2026` inside `firmware/`. Arduino needs the folder and the `.ino` file to share a name. Leave `display-2024/` unchanged |
| Battery input | Test with a bench power supply, not the pack, until the electrical lead checks your divider |

#### Deliverables

A pull request with your code, a photo or short video of it working, and `Closes #<issue number>`.

### Reference

| What | File or repo |
| --- | --- |
| Original 2024 code | [`firmware/display-2024/main.cpp`](firmware/display-2024/main.cpp) |
| Known bugs in it | [`firmware/README.md`](firmware/README.md) |
| CAN bus test code (Nov 2024) | [`firmware/can-twai-2024/`](firmware/can-twai-2024) |
| VESC data on an OLED | [VESC6\_LCD\_EBIKE.ino](https://github.com/Electrium-Mobility/firmware-workshop/blob/main/VESC6_LCD_EBIKE/VESC6_LCD_EBIKE.ino) in firmware-workshop |
| A minimal VESC dashboard | [F25 bike](https://github.com/Electrium-Mobility/F25-Bike-Repository/tree/main/src/VescUartComunication). Its battery % assumes a smaller pack, and ours runs about 36 to 50.4 V |
| VESC over CAN | [Longtail VescCAN driver](https://github.com/Electrium-Mobility/longtail-conversion-kit/tree/main/Bike-Computer/Firmware/components/VescCAN) |
| Debounced buttons | [capyware-firmware](https://github.com/Electrium-Mobility/capyware-firmware) |

**⚠️ Warning:** the longtail app file `Bike-Computer/Firmware/src/vesc_comm.c` sends 5 A to the motor for 1 second at startup (lines 46 to 48), which would likely spin it. Delete those lines before you test that code on a real motor.

## Final Checklist

You're done onboarding when every box in [Your To-Do List](#your-to-do-list) at the top is ticked: your Stage 1 deliverable is posted, and one Stage 2 issue is finished (its pull request merged, or its photos and notes posted).

## How to Submit

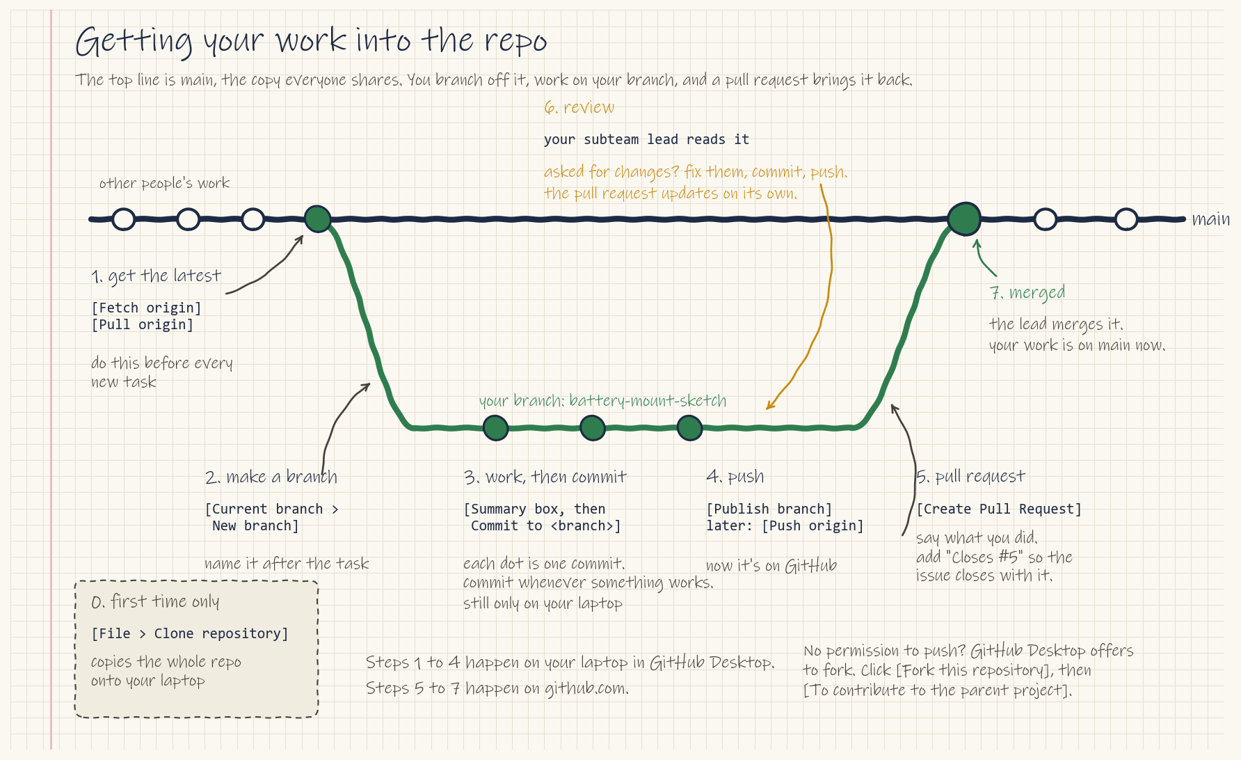
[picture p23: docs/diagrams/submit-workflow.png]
Submitting work: get the latest main, branch, commit, push, open a pull request, review, merge


1. In GitHub Desktop, switch **Current branch** to `main`, click **Fetch origin**, then **Pull origin**. Then click **Current branch > New branch** and name it after your task, for example `battery-mount-sketch`.
2. Add your files in the right folder (see your Stage 2 constraints).
3. Type a one-line summary in the **Summary** box at the bottom left (GitHub Desktop won't commit without one), click **Commit to your-branch**, then **Publish branch**, then **Create Pull Request**.
4. In the pull request, say what you did, add screenshots, and write `Closes #<issue number>`.
5. Post the link in your subteam channel. A squad lead (usually your own) reviews it, asks for changes if needed, and merges it. GitHub won't merge a pull request until a squad lead or the project lead approves it.

**💡 Hint:** if GitHub Desktop says you don't have permission to push and offers to **create a fork**, click **Fork this repository**, then choose **To contribute to the parent project**. A fork is your own copy of the repo on GitHub. Your pull request still goes to Bakfiets-F26 as normal. This only happens until you've accepted your invite to the repo.

GitHub's [Hello World guide](https://docs.github.com/en/get-started/start-your-journey/hello-world) walks through branches and pull requests.

## After Onboarding: Term Projects

Once you've finished your subteam's Stage 1 and one Stage 2 starter task, you're done onboarding. Your squad lead may also give you one of these term projects as your Stage 2 task. Move on to the main goals for the term, set by Ling, one of Electrium's two team leads (the other is Samantha Chong).

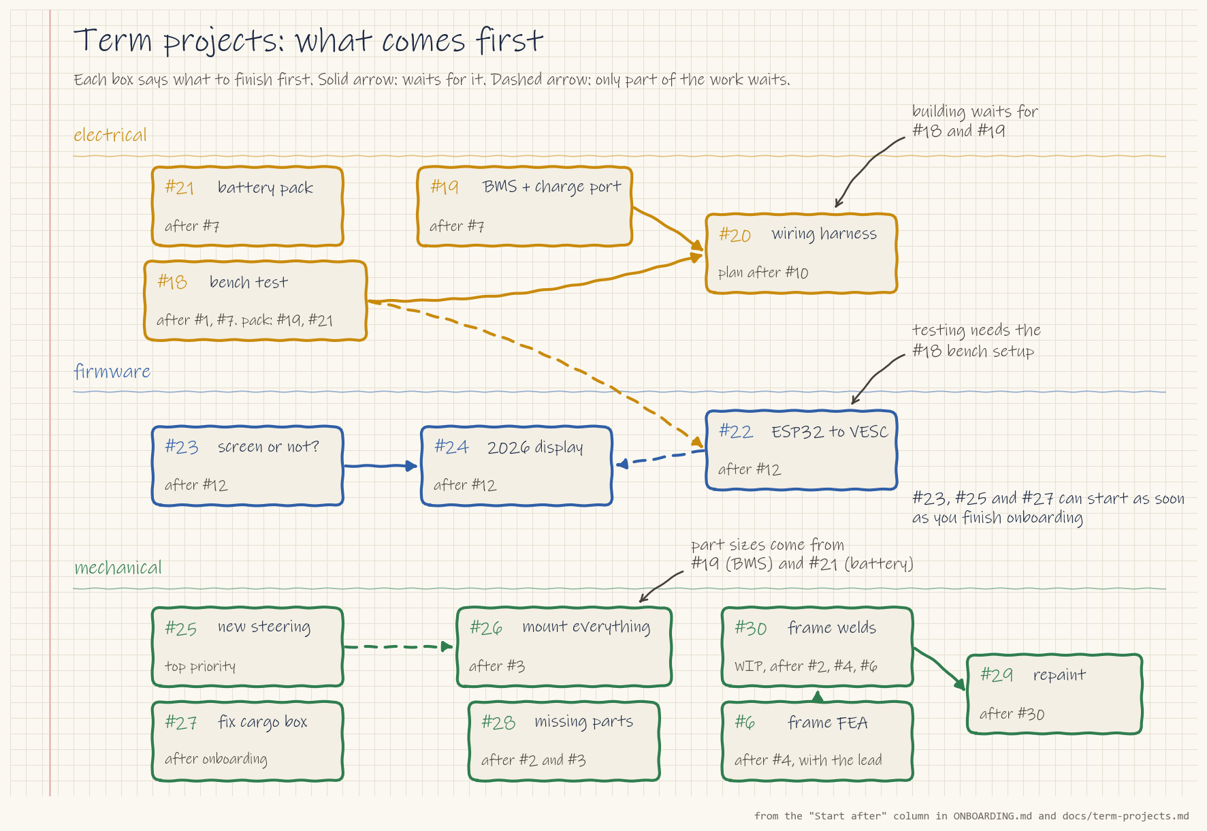
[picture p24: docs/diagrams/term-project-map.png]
Term projects by subteam, with what each one needs finished first


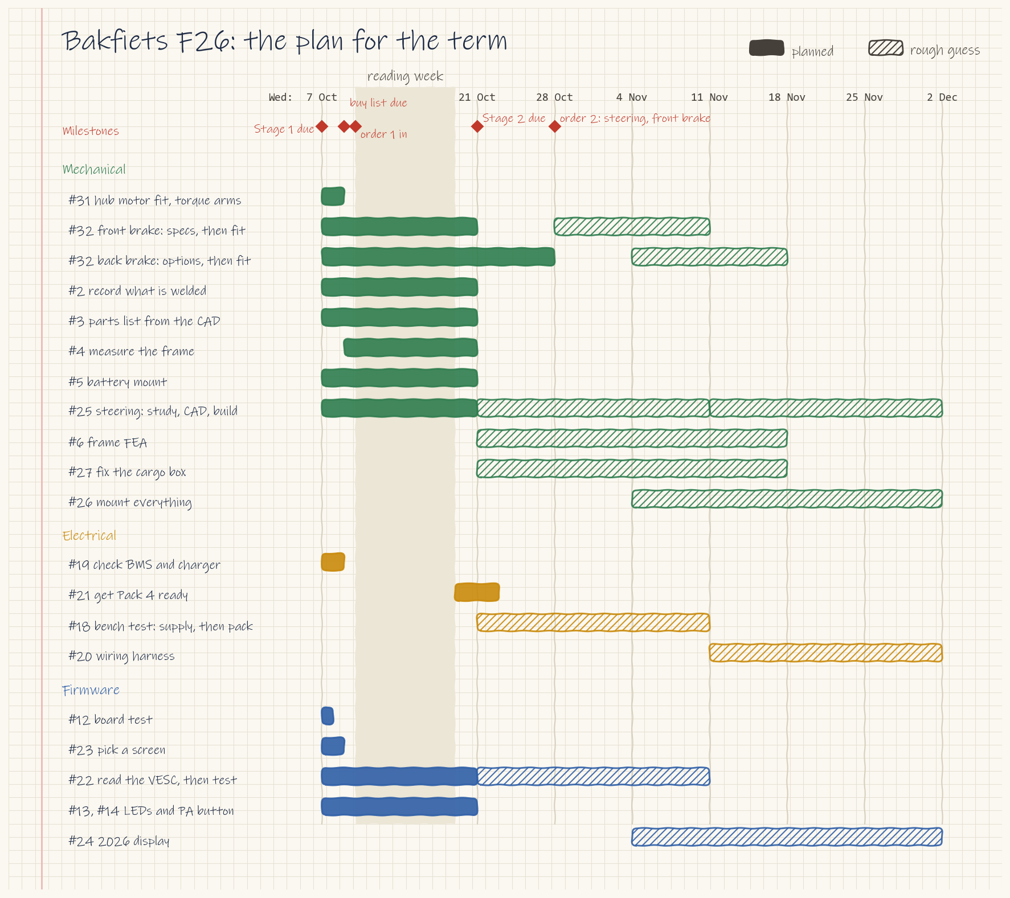
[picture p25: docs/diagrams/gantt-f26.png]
Rough plan for the term: tasks by subteam from 7 Oct to 2 Dec, with reading week and the two parts orders


*A rough timeline. Solid bars are planned, hatched bars are a guess the squad leads will firm up.*

Each project is a GitHub issue labelled `term project`. Each issue lists what to finish first and gives step-by-step instructions with safety notes, videos and example code. It ends with a clear "done when". Claim one the same way, with a comment on the issue. Work through them roughly in the order below.

### Electrical

| Order | Project | Start after |
| --- | --- | --- |
| 1 | [#21 Battery pack: get Pack 4 ready for the bike](https://github.com/Electrium-Mobility/Bakfiets-F26/issues/21) | #7 |
| 2 | [#19 Choose a BMS and charging port](https://github.com/Electrium-Mobility/Bakfiets-F26/issues/19) | #7 |
| 3 | [#18 Bench test: battery, motor controller, motor and thumb throttle](https://github.com/Electrium-Mobility/Bakfiets-F26/issues/18) | #1 and #7 for the bench-supply steps. The pack steps also need #21 and #19 |
| 4 | [#20 Plan and build the wiring harness](https://github.com/Electrium-Mobility/Bakfiets-F26/issues/20) | #10 to plan, then #18 and #19 before building |

### Firmware

| Order | Project | Start after |
| --- | --- | --- |
| 1 | [#23 Decide: screen or no screen, and which one](https://github.com/Electrium-Mobility/Bakfiets-F26/issues/23) | #12 |
| 2 | [#22 Connect the ESP32-S3 to the VESC and show real speed and battery](https://github.com/Electrium-Mobility/Bakfiets-F26/issues/22) | #12. Testing needs the bench setup from #18 |
| 3 | [#24 Build the 2026 display on top of the 2024 work](https://github.com/Electrium-Mobility/Bakfiets-F26/issues/24) | #23 and #12. Live data needs #22 |

### Mechanical

| Order | Project | Start after |
| --- | --- | --- |
| 1 | [#25 Design a new steering mechanism (rod, cable or hydraulic)](https://github.com/Electrium-Mobility/Bakfiets-F26/issues/25) | Onboarding. This is the top mechanical priority, and most of the parts budget goes to it |
| 2 | [#32 Choose and fit brakes, with levers that cut the motor](https://github.com/Electrium-Mobility/Bakfiets-F26/issues/32) | Onboarding. Nobody rides the bike without brakes |
| 3 | [#31 Fit the hub motor wheel to the frame, with torque arms](https://github.com/Electrium-Mobility/Bakfiets-F26/issues/31) | Onboarding. Nothing gets powered on the bike before this |
| 4 | [#6 Rerun the frame FEA with written load cases](https://github.com/Electrium-Mobility/Bakfiets-F26/issues/6) | #4, done with a mechanical lead. All cutting and welding waits for it |
| 5 | [#26 Mount everything on the frame](https://github.com/Electrium-Mobility/Bakfiets-F26/issues/26) | #3. Part sizes come from #19 and #21. Only mounts near the steering wait for #25 |
| 6 | [#27 Inspect and fix the cargo box](https://github.com/Electrium-Mobility/Bakfiets-F26/issues/27) | Onboarding |
| 7 | [#28 Find and buy missing bike parts](https://github.com/Electrium-Mobility/Bakfiets-F26/issues/28) | #2 and #3 |
| 8 | [#30 Plan and finish the frame welds (work in progress)](https://github.com/Electrium-Mobility/Bakfiets-F26/issues/30) | #2, #4 and #6. Needs a welder who passed the SDC weld test |
| 9 | [#29 Repaint the frame](https://github.com/Electrium-Mobility/Bakfiets-F26/issues/29) | Last: after #30, once all welding is done and #6 is approved |

The same list is in the repo at [docs/term-projects.md](docs/term-projects.md).

## Glossary

### General

| Term | Meaning | Learn more |
| --- | --- | --- |
| Electrium Mobility | The UW student design team that runs this project |  |
| Repo (repository) | An online folder of a project's files and their full change history |  |
| Clone / push | Clone copies a repo to your computer, and push sends your changes back to GitHub | [GitHub Desktop guide](https://docs.github.com/en/desktop/adding-and-cloning-repositories/cloning-a-repository-from-github-to-github-desktop) |
| Commit | One saved set of changes |  |
| Branch / pull request | A separate copy of the files you work on, and a request to merge it back after review | [GitHub Hello World](https://docs.github.com/en/get-started/start-your-journey/hello-world) |
| Main | The official branch of a repo |  |
| Issue | A task card on GitHub. `good first issue` marks the easiest starter tasks, and `term project` marks the main work after onboarding |  |
| Fork | A copy of a repo under your own GitHub account. GitHub Desktop offers one if you can't push yet. (A bike fork is the part that holds the front wheel.) |  |
| Fetch / pull / origin | Fetch checks GitHub for new changes, and pull downloads them into your clone. Origin is the copy on GitHub |  |
| Discord channel / thread | A channel is a chat room in the Discord server: #bakfiets-general for everyone, and #bakfiets-mech, #bakfiets-elec and #bakfiets-firm for the subteams. A thread is a side conversation inside a channel, like Github usernames inside #bakfiets-general |  |
| LEARN | UW's online course site, where the safety courses are |  |
| WHMIS | Workplace Hazardous Materials Information System, the chemical safety course |  |
| SDC | The Sedra Student Design Centre, the building with the team work bays |  |
| CAD | Computer-aided design: 3D models and drawings of parts |  |
| BOM | Bill of materials: every part, with quantity and where to buy it |  |
| Datasheet | The maker's document with a part's ratings and limits |  |
| Design review | A short meeting where the subteam looks at a design and suggests changes before anything is built or bought |  |
| Term codes | F26 = Fall 2026, W2024 = Winter 2024 |  |

### Mechanical

| Term | Meaning | Learn more |
| --- | --- | --- |
| Bakfiets | A Dutch "box bike" with the cargo box in front of the rider | [Wikipedia](https://en.wikipedia.org/wiki/Bakfiets) |
| 10 | The steel the 2024 design specifies for the main tubes. It's strong for its weight and weldable. Some tubes may be donor-bike steel instead, and [#4](https://github.com/Electrium-Mobility/Bakfiets-F26/issues/4) records which | [41xx steel](https://en.wikipedia.org/wiki/41xx_steel) |
| Weldment | A SolidWorks feature that builds a frame from a 3D sketch plus tube sizes | [Javelin walkthrough](https://www.javelin-tech.com/blog/2024/05/solidworks-weldments/) |
| Weldment profile | The cross-section shape of a tube, stored as a file SolidWorks can reuse |  |
| Master sketch | One sketch of key points and lines that every part follows |  |
| Jig | A fixture that holds tubes at the right angles for welding | [Framebuilder Supply](https://framebuildersupply.com/pages/what-do-i-need-to-build-my-first-frame) |
| Notching | Cutting a tube end into a curved saddle so it sits flush against another tube | [Tube notching](https://en.wikipedia.org/wiki/Tube_notching) |
| Tube size | Outside diameter x wall thickness, for example 1.5" x 0.065" |  |
| Rear triangle | The seat stays and chain stays that hold the back wheel |  |
| MDF | A cheap fibreboard that cuts cleanly on a laser cutter |  |
| SLDPRT / SLDASM / SLDDRW | SolidWorks part, assembly and drawing files |  |
| Pack and Go | A SolidWorks command (**File > Pack and Go**) that copies an assembly and all its parts to a new folder, so the copy doesn't point back at the originals |  |
| FeatureManager tree | The list of parts and features on the left side of the SolidWorks window |  |
| Wheelbase / head tube angle | The distance between the front and rear axles / the angle of the tube the steering turns in, measured from the ground |  |
| DXF / STL | A 2D drawing for laser cutting / a 3D shape for printing |  |
| FEA | A simulation of how much a part bends and how stressed it gets under load | [Finite element method](https://en.wikipedia.org/wiki/Finite_element_method) |
| Load case / safety factor | A set of forces to test against / how many times stronger a part is than it needs to be |  |
| Hub motor / mid-drive | A motor inside a wheel (ours is direct-drive: no gears inside) / a motor that turns the pedal cranks | [Electric bicycle](https://en.wikipedia.org/wiki/Electric_bicycle) |

### Electrical

| Term | Meaning | Learn more |
| --- | --- | --- |
| 18650 cell | The standard cylindrical lithium-ion cell in our pack | [18650 battery](https://en.wikipedia.org/wiki/18650_battery) |
| 12S2P | 12 groups in series, each group being 2 cells in parallel (Pack 4). About 44 V nominal (its usual voltage in use), 50.4 V full, 36 V empty | [Battery University](https://batteryuniversity.com/article/bu-302-series-and-parallel-battery-configurations) |
| BMS | Battery management system. It balances cells and cuts power on overcharge, over-drain, overheating or a short | [Wikipedia](https://en.wikipedia.org/wiki/Battery_management_system) |
| Antispark / precharge | A circuit that stops the spark when a battery first connects to a motor controller | [Pre-charge](https://en.wikipedia.org/wiki/Pre-charge) |
| ESC / VESC / FSESC 6.7 | The motor controller. VESC is an open-source design; the FSESC 6.7 is the VESC-based model the club website says the 2024 team used | [VESC project](https://vesc-project.com/) |
| PDB | Power distribution board: splits battery power and steps 48 V down to 5 V |  |
| Buck converter | A circuit that steps voltage down efficiently | [Wikipedia](https://en.wikipedia.org/wiki/Buck_converter) |
| MOSFET | An electronic switch that a small signal can turn on | [MOSFET switch](https://projecthub.arduino.cc/ejshea/connecting-an-n-channel-mosfet-6a7325) |
| B+ / B- / P- | The pack's positive and negative terminals (B+, B-), and the BMS's output negative that the rest of the bike connects to (P-) |  |
| Balance wires | Thin wires from each cell group to the BMS, so it can check every group's voltage |  |
| DC-rated fuse | A fuse that can safely break a battery's steady current. Ordinary car fuses can't at 50 V |  |
| TVS diode | A surge protector. Its standoff voltage (the highest voltage it ignores) must sit just above 50.4 V; its clamp voltage (the most it lets through) must stay below what the other parts survive |  |
| Bench power supply | A lab box that gives an adjustable voltage with a current limit, used for safe testing instead of a battery |  |
| XT60 / JST | A common battery plug / a family of small signal connectors | [XT60](https://components101.com/connectors/xt60-connector) |
| LiPo bag | A fire-resistant bag for charging small batteries. Too small for our 24-cell pack, which goes in a metal box |  |
| Schematic / PCB | A drawing of a circuit / the printed circuit board it's built on | [KiCad getting started](https://docs.kicad.org/9.0/en/getting_started_in_kicad/getting_started_in_kicad.html) |
| Gerbers | The files a factory uses to make a PCB |  |
| Voltage divider | Two resistors that scale 50 V down to a level the ESP32 can measure | [SparkFun](https://learn.sparkfun.com/tutorials/voltage-dividers/all) |

### Firmware

| Term | Meaning | Learn more |
| --- | --- | --- |
| ESP32-S3 | The small computer (microcontroller) that runs our screen and lights | [ESP32](https://en.wikipedia.org/wiki/ESP32) |
| Dev board | A microcontroller on a board with USB, ready for testing |  |
| GPIO | One pin the code can read or switch | [GPIO](https://en.wikipedia.org/wiki/General-purpose_input/output) |
| VCC / GND / SDA / SCL | Power / ground / I2C data / I2C clock pins |  |
| I2C | The two-wire link to the screen | [SparkFun I2C](https://learn.sparkfun.com/tutorials/i2c/all) |
| UART | A simple serial link many motor controllers use | [SparkFun serial](https://learn.sparkfun.com/tutorials/serial-communication/all) |
| CAN / TWAI | A reliable two-wire link between boards. Espressif calls its CAN driver TWAI | [CAN bus](https://en.wikipedia.org/wiki/CAN_bus) |
| COM port / USB CDC | How Windows sees the board over USB / the setting that makes Serial Monitor work on the S3's USB port |  |
| OLED | A small screen where each pixel makes its own light |  |
| Sketch (Arduino) | One Arduino program: a `.ino` file in a folder with the same name |  |
| Serial Monitor | The Arduino IDE window (**Tools > Serial Monitor**) that shows messages the board prints |  |
| SSD1306 | The 128x64 OLED screen | [Random Nerd Tutorials](https://randomnerdtutorials.com/esp32-ssd1306-oled-display-arduino-ide/) |
| WS2813 / FastLED | An LED strip where each LED is set on its own / the library that drives it | [Random Nerd Tutorials](https://randomnerdtutorials.com/guide-for-ws2812b-addressable-rgb-led-strip-with-arduino/) |
| millis() / non-blocking | Arduino's clock / code that keeps running instead of pausing | [Blink Without Delay](https://docs.arduino.cc/built-in-examples/digital/BlinkWithoutDelay/) |
| ADC pin | A pin that measures a voltage |  |
| Breadboard | A plastic board with holes for building test circuits without soldering |  |
| Debounce | Ignoring the brief flicker when a button is pressed, so one press counts once |  |
| Silkscreen | The printed labels on a circuit board, such as pin names |  |

## Sources

- [Bakfiets-F26](https://github.com/Electrium-Mobility/Bakfiets-F26): this term's repo. [`docs/history/SOURCES.md`](docs/history/SOURCES.md) records where the 2024 and 2025 files came from, and the 2024 team roster
- [bakfiets](https://github.com/Electrium-Mobility/bakfiets): the original 2024 repo, kept unchanged as the archive
- Club website pages for [W2024](https://github.com/Electrium-Mobility/electrium-w24website/blob/main/docs/W2024-projects/project1_2023.md) and [W2025](https://github.com/Electrium-Mobility/electrium-w24website/blob/main/docs/W2025-projects/bakfiets_2024.md)
- UW: [SDC Forms and Team Information](https://uwaterloo.ca/sedra-student-design-centre/forms-and-team-information) (SDC room booking and team forms, UW login needed. Parts are ordered through Electrium, not these forms), [WHMIS](https://uwaterloo.ca/safety-office/training/student-safety-orientation-whmis), [student shops](https://uwaterloo.ca/engineering-student-shops/getting-started), [lithium battery standard](https://uwaterloo.ca/safety-office/laboratory-safety/batteries), [lab software](https://uwaterloo.ca/engineering-computing/computer-labs/lab-software)

This guide draws on all 82 repos in the Electrium-Mobility org, searched on 2026-09-25. Every video link was checked against YouTube.

This guide is new this term. If a step didn't work for you, fix it in a pull request or post what went wrong in #bakfiets-general, and the next person won't hit it. Welcome to the team.

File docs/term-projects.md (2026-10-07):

# Term projects (after onboarding)

These are the main goals for the term, from Ling, one of Electrium's two team leads (the other is Samantha Chong). Start them **after onboarding**: once you've finished your subteam's Stage 1 and one Stage 2 starter task from the [onboarding guide](../ONBOARDING.md).

Every project is a GitHub issue with the `term project` label. Each one lists what to finish first, step-by-step instructions, safety notes, links to videos and example code, and a clear "done when". Claim one with a comment on the issue saying you're working on it.

Term project map

Rough plan for the term: tasks by subteam from 7 Oct to 2 Dec, with reading week and the two parts orders

*A rough timeline. Solid bars are planned, hatched bars are a guess the squad leads will firm up.*

## Electrical

| Order | Project | Start after |
| --- | --- | --- |
| 1 | [#21 Battery pack: get Pack 4 ready for the bike](https://github.com/Electrium-Mobility/Bakfiets-F26/issues/21) | #7 |
| 2 | [#19 Choose a BMS and charging port](https://github.com/Electrium-Mobility/Bakfiets-F26/issues/19) | #7 |
| 3 | [#18 Bench test: battery, motor controller, motor and thumb throttle](https://github.com/Electrium-Mobility/Bakfiets-F26/issues/18) | #1 and #7 for the bench-supply steps. The pack steps also need #21 and #19 |
| 4 | [#20 Plan and build the wiring harness](https://github.com/Electrium-Mobility/Bakfiets-F26/issues/20) | #10, then #18 and #19 before building |

## Firmware

| Order | Project | Start after |
| --- | --- | --- |
| 1 | [#23 Decide: screen or no screen, and which one](https://github.com/Electrium-Mobility/Bakfiets-F26/issues/23) | #12 |
| 2 | [#22 Connect the ESP32-S3 to the VESC and show real speed and battery](https://github.com/Electrium-Mobility/Bakfiets-F26/issues/22) | #12. Testing needs #18 |
| 3 | [#24 Build the 2026 display on top of the 2024 work](https://github.com/Electrium-Mobility/Bakfiets-F26/issues/24) | #23, #12. Live data needs #22 |

## Mechanical

| Order | Project | Start after |
| --- | --- | --- |
| 1 | [#25 Design a new steering mechanism (rod, cable or hydraulic)](https://github.com/Electrium-Mobility/Bakfiets-F26/issues/25) | Onboarding. This is the top mechanical priority, and most of the parts budget goes to it |
| 2 | [#32 Choose and fit brakes, with levers that cut the motor](https://github.com/Electrium-Mobility/Bakfiets-F26/issues/32) | Onboarding. Nobody rides the bike without brakes |
| 3 | [#31 Fit the hub motor wheel to the frame, with torque arms](https://github.com/Electrium-Mobility/Bakfiets-F26/issues/31) | Onboarding. Nothing gets powered on the bike before this |
| 4 | [#6 Rerun the frame FEA with written load cases](https://github.com/Electrium-Mobility/Bakfiets-F26/issues/6) | #4, done with a mechanical lead. All cutting and welding waits for it |
| 5 | [#26 Mount everything on the frame](https://github.com/Electrium-Mobility/Bakfiets-F26/issues/26) | #3. Part sizes come from #19 and #21. Only mounts near the steering wait for #25 |
| 6 | [#27 Inspect and fix the cargo box](https://github.com/Electrium-Mobility/Bakfiets-F26/issues/27) | Onboarding |
| 7 | [#28 Find and buy missing bike parts](https://github.com/Electrium-Mobility/Bakfiets-F26/issues/28) | #2, #3 |
| 8 | [#30 Plan and finish the frame welds (work in progress)](https://github.com/Electrium-Mobility/Bakfiets-F26/issues/30) | #2, #4 and #6. Needs a welder who passed the SDC weld test |
| 9 | [#29 Repaint the frame](https://github.com/Electrium-Mobility/Bakfiets-F26/issues/29) | Last: after #30, once all welding is done and #6 is approved |

Decided (6 Oct): the bike uses the 48 V, 2000 W direct-drive hub motor in a 24" wheel and Pack 4 (48 V, 12S2P). Details are in [#1](https://github.com/Electrium-Mobility/Bakfiets-F26/issues/1) and [#21](https://github.com/Electrium-Mobility/Bakfiets-F26/issues/21).

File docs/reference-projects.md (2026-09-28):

# Other Electrium projects worth copying from

Other Electrium teams have solved many of our problems already. This list comes from checking all 82 repos in the org in September 2026. Repos marked Private are only visible to Electrium org members, and being added to Bakfiets-F26 doesn't include them. Your subteam lead can pass on anything you need from one.

## Mechanical

| Resource | What you'll learn | Access |
| --- | --- | --- |
| [Longtail kit frame V7](https://github.com/Electrium-Mobility/longtail-conversion-kit/tree/main/Mechanical/LongtailFrameV7) | Another cargo frame, with PDF drawings, cutting templates, and printable 75° and 105° weld angle blocks | Public |
| [vroom battery box](https://github.com/Electrium-Mobility/vroom_mechanical/tree/main/Mechanical/Battery%20Box) | A battery box with BMS mount, bus bars and cut list, with VESC and Daly BMS models next to it | Public |
| [Gokart mechanical](https://github.com/Electrium-Mobility/Gokart/tree/main/Mechanical) | A sheet-metal battery pack drawing with DXF, a printed button and screen housing, welding jigs | Public |
| [onewheel-w25](https://github.com/Electrium-Mobility/onewheel-w25) | Battery pack and BMS models, printable 18650 cell holders | Public |
| F24-Bike | A Bafang BBS02 model with bracket, and a saved paper with standard frame load cases | Private |
| S25Bike_CAD | Ready-made SolidWorks weldment profiles | Private |

Longtail kit

## Electrical

See the table in [electrical/README.md](../electrical/README.md#boards-you-can-learn-from-or-reuse). Also:

| Resource | What you'll learn | Access |
| --- | --- | --- |
| [Longtail wiring diagram](https://github.com/Electrium-Mobility/longtail-conversion-kit/blob/main/Electrical/wiring%20diagram.drawio) | Battery to BMS to ESC to motor, plus a buck for the ESP32. Opens in [draw.io](https://app.diagrams.net/) | Public |
| [F25 Skateboard write-up](https://github.com/Electrium-Mobility/electrium-w24website/blob/main/docs/F2025-projects/F25%20Skateboard.md) | A finished project: 12S2P pack with BMS, two-stage buck power board, ESP32 reading the VESC and BMS | Public |
| eHPV power board (branch `schematic-updates`) | A PDB with fuse, surge protection, E-stop, buck and CAN transceiver | Private |

## Firmware

| Resource | What you'll learn | Watch out for |
| --- | --- | --- |
| [VESC6_LCD_EBIKE.ino](https://github.com/Electrium-Mobility/firmware-workshop/blob/main/VESC6_LCD_EBIKE/VESC6_LCD_EBIKE.ino) | Reads a VESC over UART and shows it on an SSD1306 OLED, like our display | No README. Libraries ship as zip files (Sketch > Include Library > Add .ZIP) |
| [eskateboard-firmware](https://github.com/Electrium-Mobility/eskateboard-firmware/blob/main/src/main.cpp) | VESC UART data and a FastLED battery bar on ESP32 (PlatformIO) | Battery % is a fake test wave, and its second serial port uses the USB pins |
| [F25 bike VESC dashboard](https://github.com/Electrium-Mobility/F25-Bike-Repository/tree/main/src/VescUartComunication) | A minimal VescUart dashboard | Battery % assumes 30 to 36 V, but ours runs about 36 to 50.4 V |
| [Longtail VescCAN driver](https://github.com/Electrium-Mobility/longtail-conversion-kit/tree/main/Bike-Computer/Firmware/components/VescCAN) | An ESP-IDF driver that reads VESC status over CAN | **Its app file `src/vesc_comm.c` (lines 46 to 48) sends 5 A for 1 s at startup and would likely spin the motor. Delete those lines before testing** |
| [Gokart firmware](https://github.com/Electrium-Mobility/Gokart/tree/main/Firmware) | Working CAN (TWAI) send and receive, and an OLED menu with buttons | Not VESC code, and buttons aren't debounced |
| [capyware-firmware](https://github.com/Electrium-Mobility/capyware-firmware) | Step-by-step ESP-IDF setup, and debounced buttons | Setup only |
| [Go-kart pin map](https://github.com/Electrium-Mobility/W26-Electrium-Gokart-ESP32S3/tree/main/src/gokart_lcd_esp32s3) | A clean one-file pin table (`hardware.h`) to copy for our own `pins.h` | |

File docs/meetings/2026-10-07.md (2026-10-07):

# Team meeting: Wednesday 7 October 2026

6:30 to 7:30 pm, the Electrium bay (first floor of E5). Post in #bakfiets-general when you're at the door.

**Before you come:** pull the latest files in GitHub Desktop (**Fetch origin**, then **Pull origin**) and bring a laptop and charger.

## Agenda

| Time | What |
| --- | --- |
| 6:30 | Updates (project lead) |
| 6:45 | Subteam time (squad leads) |
| 7:20 | Wrap-up |

## Updates

- **Squad leads:** Annie and Aarush (mech), Jack (elec), David (firm). They approve pull requests.
- **What we're using:** the 2000 W hub motor (set to 500 W in VESC), Pack 4 (48 V, working and charged), and the ESP32-S3 boards on the black parts organizer. We already have a BMS, a charger and the antispark. No screens yet. [Photos](../photos/bay-2026-10/README.md)
- **Budget:** about $300. Fuse and torque arms first, the rest goes to steering and brakes.
- **Parts order:** goes in before reading week. Post anything we need on its issue with a link and price by **Fri 9 Oct**.
- **Bay inspection** is this week, so leave it tidy.

## Tonight's tasks

**Mechanical (Annie, Aarush)**
- [ ] Check the hub motor wheel fits the frame and pick torque arms ([#31](https://github.com/Electrium-Mobility/Bakfiets-F26/issues/31))
- [ ] See what brakes the frame can take ([#32](https://github.com/Electrium-Mobility/Bakfiets-F26/issues/32))
- [ ] Start the steering comparison ([#25](https://github.com/Electrium-Mobility/Bakfiets-F26/issues/25))

**Electrical (Jack)**
- [ ] Check the BMS and charger suit Pack 4 ([#19](https://github.com/Electrium-Mobility/Bakfiets-F26/issues/19))
- [ ] Find the motor controller's model, probably on its underside ([#18](https://github.com/Electrium-Mobility/Bakfiets-F26/issues/18))

**Firmware (David)**
- [ ] Run the board test on every laptop (Firmware Stage 1, step 4)
- [ ] Install VESC Tool with [David's VESC setup guide](https://docs.google.com/document/d/1j8MdOX_X7YmgLBL9RPZFvX0nbanl0cpTKmFx9X2taN4/edit)
- [ ] Look for screens. If there aren't any, pick one to buy ([#23](https://github.com/Electrium-Mobility/Bakfiets-F26/issues/23))

**Everyone:** claim a Stage 2 task from your subteam's table in the [onboarding guide](../../ONBOARDING.md) with a comment on its issue.

## Dates

- **Fri 9 Oct:** anything to buy posted on its issue
- **10 to 18 Oct:** reading week, no meeting on the 14th
- **Wed 21 Oct:** Stage 2 due, next meeting

## Notes

**Attendance:**

**Decisions:**

**Action items**

| What | Who | By |
| --- | --- | --- |
| Post anything to buy on its issue | Squad leads | Fri 9 Oct |
| Put in the parts order | Project lead | Weekend of 10 Oct |
| | | |

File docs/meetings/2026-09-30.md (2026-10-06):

# Team meeting: Wednesday 30 September 2026

**6:30 to 7:30 pm, the Electrium bay (workbay 1002), Sedra Student Design Centre (in Engineering 5)** · Run by the project lead

This is our first working meeting. We'll pick the subteam leads, then spend most of the hour on each subteam's Stage 1. A small group will look over the real bike at the same time.
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

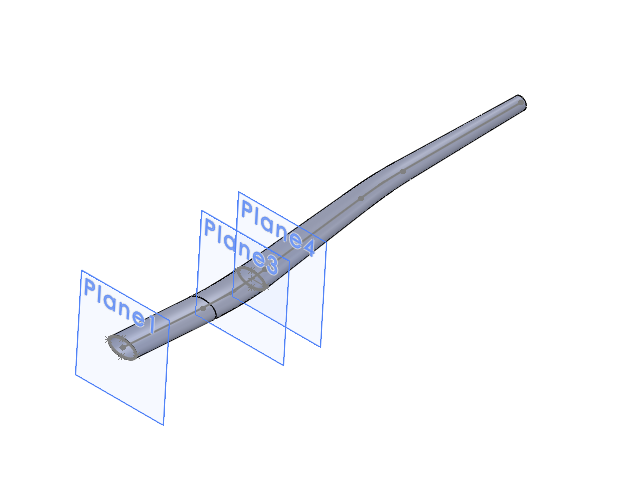
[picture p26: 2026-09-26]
docs/images/cad-previews/Chain_stays.png

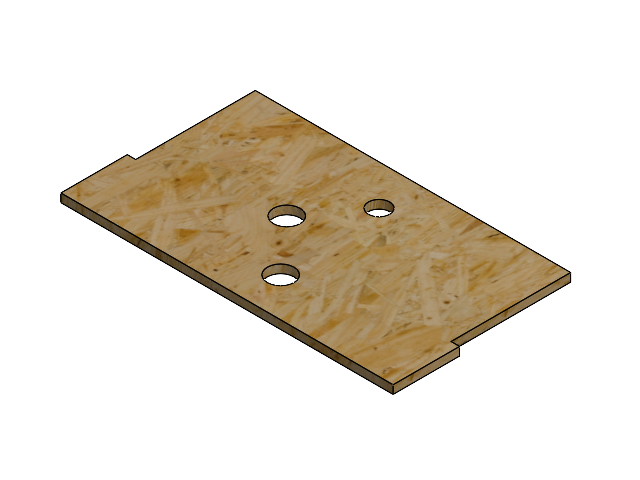
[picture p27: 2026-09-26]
docs/images/cad-previews/RearDropoutBracket.png

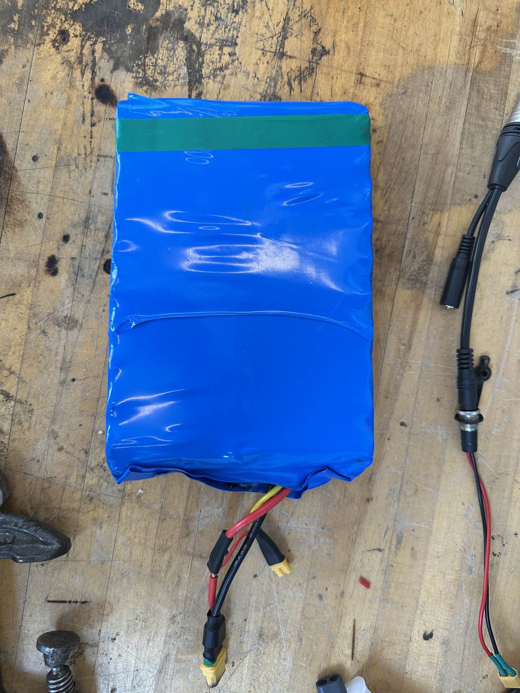
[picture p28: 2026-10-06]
docs/photos/bay-2026-10/pack3-back.jpg

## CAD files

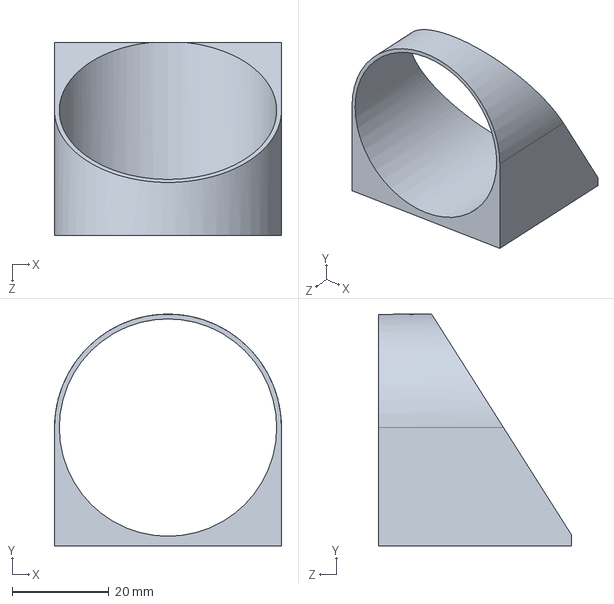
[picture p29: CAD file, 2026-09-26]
mechanical/cad-2024/notches/Main Tube to MTH.SLDPRT
47.0 x 48.0 x 40.0 mm

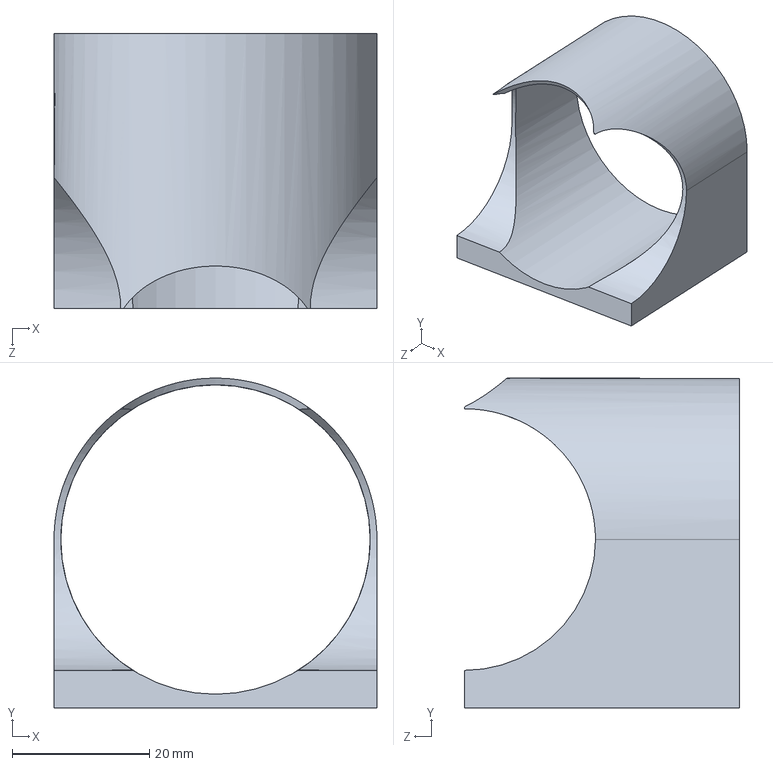
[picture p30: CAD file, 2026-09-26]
mechanical/cad-2024/notches/Main Tube to BB.SLDPRT
47.0 x 48.0 x 40.0 mm

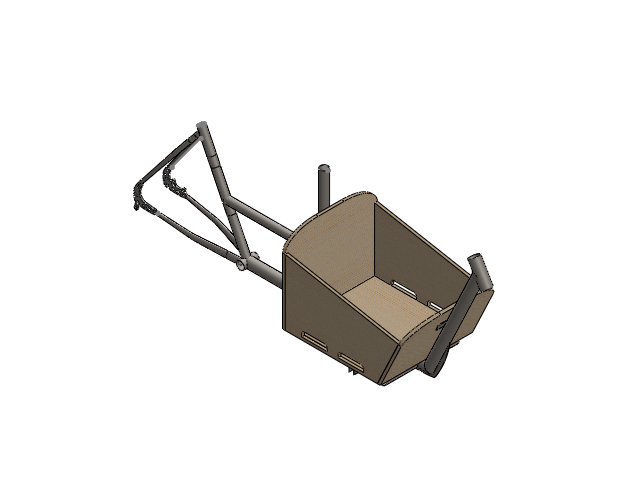
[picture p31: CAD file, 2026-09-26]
mechanical/cad-2024/Cargo Box/Cargo Box.SLDASM
Frame 2.0
Box Back
Box Front
Box Side x 2
Box Bottom

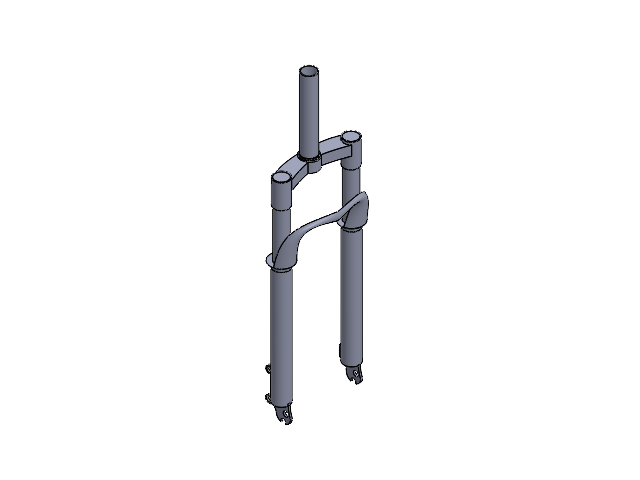
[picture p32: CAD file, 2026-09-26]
mechanical/cad-2024/scrap bike parts/front fork parts/bakfiets front fork.SLDASM
front fork
front fork two rod x 2
top rod fork
3 hole connecting part

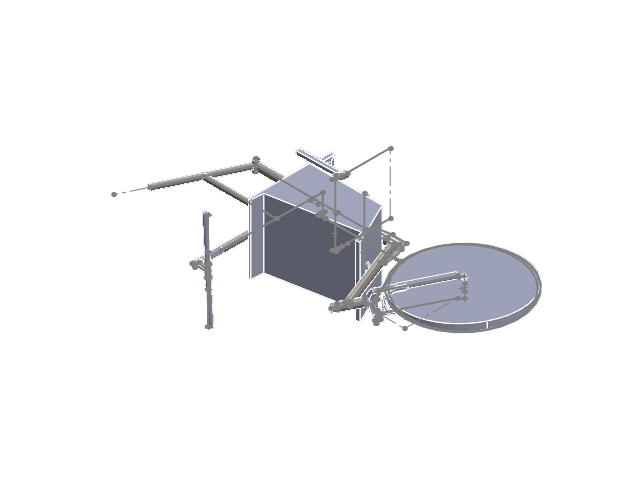
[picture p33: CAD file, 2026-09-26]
mechanical/cad-2025-coop/bakfiets_main_asm.SLDASM
bakfiets_master_sketch
bakfiets_frame
bakfiets_front_suspension
bakfiets_front_wheel
bakfiets_steering_handlebars
bakfiets_ball_joint x 2
bakfiets_steering_rod
bakfiets_kickstand
bakfiets_cargo_box_low_detail

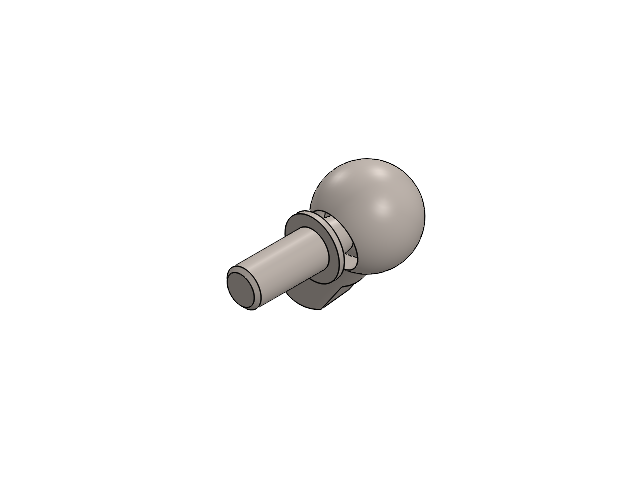
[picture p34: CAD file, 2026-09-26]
mechanical/cad-2024/steering system/ball joint/ball joint.SLDASM
socket
ball

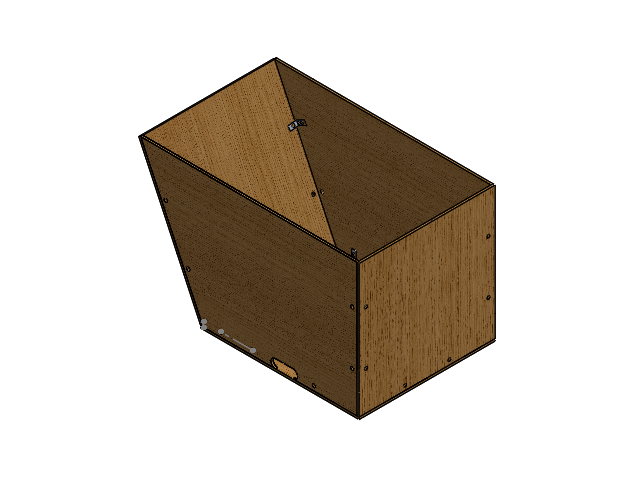
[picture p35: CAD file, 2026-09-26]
mechanical/cad-2025-coop/edited-2024-parts/Box with angles.SLDASM
Cargo Box 2
Aluminum Angle (1.25 x 0.125) x 12
Custom Angle for Sides 2 x 2
flat washer type b regular_ai x 2
hex bolt_ai x 2
hex nut_ai x 2

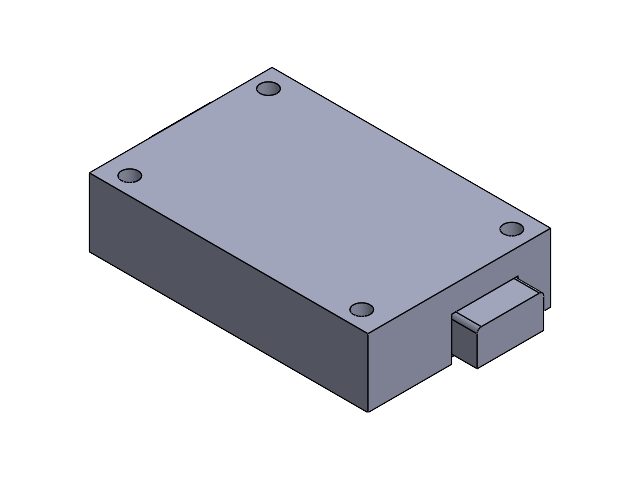
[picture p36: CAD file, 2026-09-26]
mechanical/cad-2024/battery box/battery pack/Antispark Assembly.SLDASM
Antispark
Antispark cover

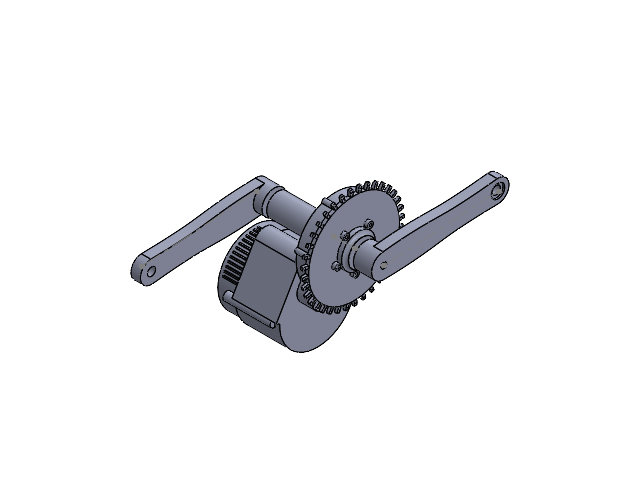
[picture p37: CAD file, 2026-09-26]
mechanical/cad-2024/MotorCrank/CrankMotorAssembly.SLDASM
Motor
Crank Shaft
Crank Wheel
Crank' x 2
Crank Wheel screws x 5

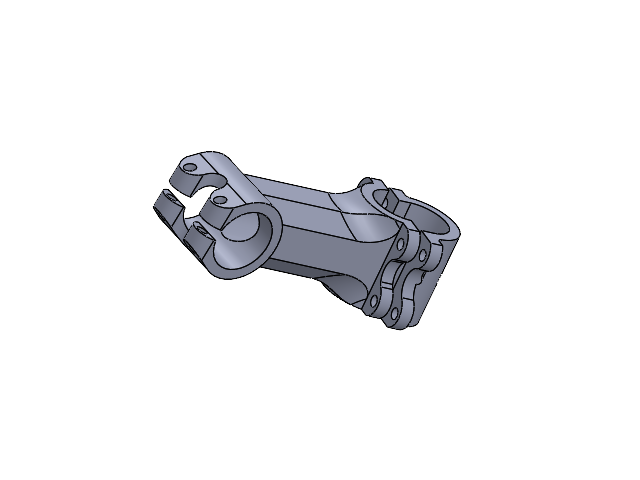
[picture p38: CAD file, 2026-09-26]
mechanical/cad-2024/scrap bike parts/stem parts/handlebar stem.SLDASM
stem
top stem

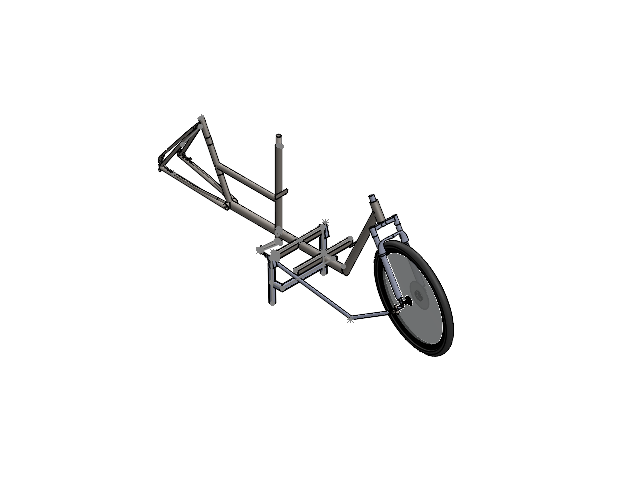
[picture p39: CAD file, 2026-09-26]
mechanical/cad-2024/steering system/steeringAssembly.SLDASM
Frame 2.0
steering shaft
front fork
front fork two rod x 2
top rod fork
3 hole connecting part
rear steering plate
front wheel
socket x 2
ball x 2
Part5^steeringAssembly
steeringLink
91280A626_Medium-Strength Class 8.8 Steel Hex Head Screw x 2
KickstandBracketFeb15 x 2
Kickstand

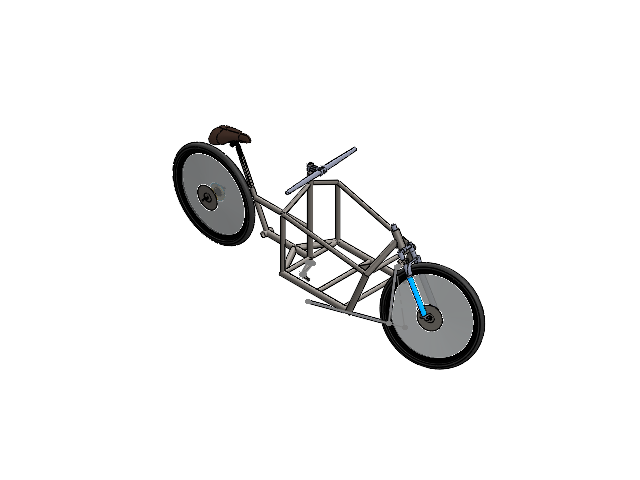
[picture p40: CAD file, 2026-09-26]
mechanical/cad-2024/Assem1.SLDASM
Frame
front fork
front fork two rod x 2
top rod fork
3 hole connecting part
front wheel
rear wheel
seat
steering shaft
rear steering plate
socket x 2
ball x 2
91280A626_Medium-Strength Class 8.8 Steel Hex Head Screw x 2
clamp x 2
front steering plate
handlebars rod
stem
top stem
linkage

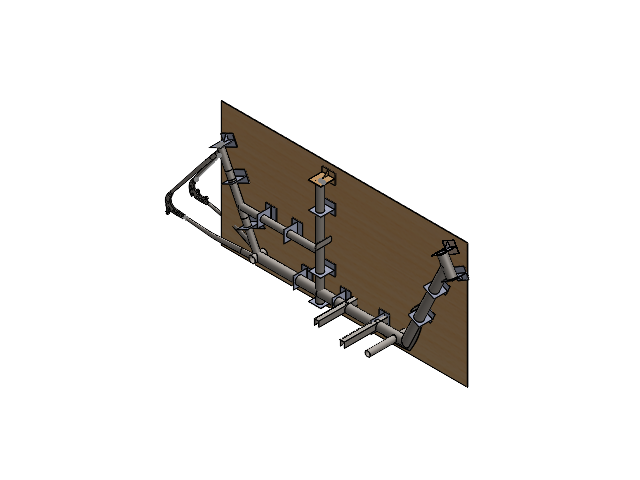
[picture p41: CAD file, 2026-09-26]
mechanical/cad-2024/jig/Jig/JigV2.SLDASM
Frame 2.0
JigBase
End1
MirrorEnd1
Part7^JigV2
MirrorPart7^JigV2
Part9^JigV2
Part10^JigV2 x 2
Part11^JigV2 x 5
Part12^JigV2 x 2
Part13^JigV2 x 2

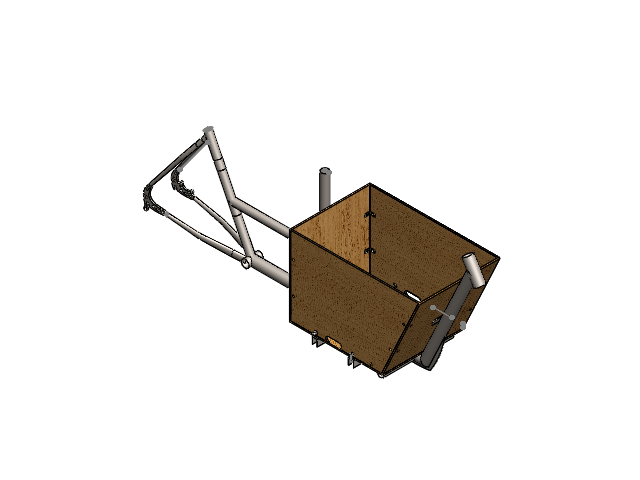
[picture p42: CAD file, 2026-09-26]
mechanical/cad-2024/Box and Frame.SLDASM
Frame 2.0
Cargo Box 2
Aluminum Angle (1.25 x 0.125) x 12
Custom Angle for Sides 2 x 2
flat washer type b regular_ai x 2
hex bolt_ai x 2
hex nut_ai x 2

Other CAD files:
mechanical/cad-2024/notches/Main Tube to HT.SLDPRT
mechanical/cad-2024/Box with angles.SLDASM
mechanical/cad-2024/notches/Main Tube H to MT.SLDPRT
mechanical/cad-2024/notches/Main Tube to StT.SLDPRT
mechanical/cad-2024/Aluminum Angle (1.25 x 0.125).SLDPRT
mechanical/cad-2024/Cargo Box 2.SLDPRT
mechanical/cad-2024/Cargo Box.SLDPRT
mechanical/cad-2024/Cargo Box/Box Back.SLDPRT
mechanical/cad-2024/Cargo Box/Box Bottom.SLDPRT
mechanical/cad-2024/Cargo Box/Box Front.SLDPRT
mechanical/cad-2024/Cargo Box/Box Side.SLDPRT
mechanical/cad-2024/Circular tubing frame (COPY).DXF
mechanical/cad-2024/Custom Angle for Sides 2.SLDPRT
mechanical/cad-2024/Custom Angle for Sides 3.SLDPRT
mechanical/cad-2024/Custom Angle for Sides.SLDPRT
mechanical/cad-2024/Frame 2.0-Sweep8.SLDDRW
mechanical/cad-2024/Frame 2.0-Sweep8.SLDPRT
mechanical/cad-2024/Frame 2.0.SLDPRT
mechanical/cad-2024/Frame.SLDPRT
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

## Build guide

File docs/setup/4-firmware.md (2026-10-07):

# Setup for firmware

Do [Getting Started](../../ONBOARDING.md#getting-started) in the onboarding guide first.

The steps you have to do are in [Firmware Stage 1](../../ONBOARDING.md#stage-1-run-the-desk-demo). This page repeats them with extra help, so you don't need to do anything twice.

## 1. What you need

- An **ESP32-S3 dev board**, such as the ESP32-S3-DevKitC-1. A plain ESP32 won't work: the code uses GPIO 9 and 10, which a plain ESP32 wires to its flash chip.
- An **SSD1306 128x64 I2C OLED** screen (the common 0.96-inch kind).
- Four female-to-female jumper wires and a USB-C data cable (charge-only cables don't work).
- No LED strip is needed for the desk demo.

Don't buy one. Electrium's ESP32 boards are on the black parts organizer in the bay. There are no screens yet, and we'll probably buy a few. Until you have one, do the board test: step 4 of [Firmware Stage 1](../../ONBOARDING.md#stage-1-run-the-desk-demo) in the onboarding guide (not step 4 below). Before that, do section 2 and steps 1 to 3 of section 3 on your own laptop, then click **Verify** (the checkmark button) to check it builds without a board.

## 2. Install Arduino IDE and ESP32 support

1. Download [Arduino IDE 2](https://www.arduino.cc/en/software) and install it.
2. Add ESP32 boards with the written guide [Installing ESP32 in Arduino IDE 2](https://randomnerdtutorials.com/installing-esp32-arduino-ide-2-0/), or watch [Set up ESP32 with Arduino IDE in 3 minutes](https://www.youtube.com/watch?v=ikBlhX-erSw).
3. Choose **Tools > Manage Libraries**, and install **Adafruit SSD1306** and **FastLED**. When asked, click **Install all**, which also installs Adafruit GFX and Adafruit BusIO. The code needs FastLED to build even without an LED strip.

## 3. Run the desk demo

Steps 1 to 3 need no board. Click **Verify** (the checkmark, top left) after step 3 to check the code builds. The first build can take a few minutes, and it worked when the bottom panel says **Done compiling**.

1. In Arduino IDE, choose **File > Open** and pick `firmware\desk-demo\desk-demo.ino` in your clone (by default `Documents\GitHub\Bakfiets-F26\firmware\desk-demo\desk-demo.ino`).
2. Choose **Tools > Board > esp32 > ESP32S3 Dev Module**.
3. Set **Tools > USB CDC On Boot > Enabled** (set it to **Disabled** if you plug into the port labelled UART, or Serial Monitor stays blank).
4. Wire the screen: VCC to 3.3 V, GND to GND, SDA to GPIO 10, SCL to GPIO 9.

   Desk demo wiring

5. Plug the board in using the USB-C port labelled **USB** (not the one labelled UART). Choose its COM port under **Tools > Port**. Not sure which one? Unplug the board and look again: the one that disappears is yours.
6. Click **Upload**.
7. Wait about 10 seconds. The screen should show 50%, 36 km/h and PA 5. It's blank at first because the code plays the LED animation before it draws.

**Upload says "Failed to connect"?** Hold the **BOOT** button, tap **RST**, release BOOT, then click Upload again.
**No COM port?** Try another USB-C cable (some only charge), or, if you're on the port labelled UART, install the CP210x or CH340 USB driver.
**Blank screen?** Check the SDA and SCL wires, then, near the top of `desk-demo.ino`, change `#define SCREEN_ADDRESS 0x3C` to `0x3D` and upload again. The message "SSD1306 allocation failed" in Serial Monitor (**Tools > Serial Monitor**, speed set to 9600 at the bottom right) means the ESP32 couldn't reserve memory for the screen. It's not a wiring fault.

More help: [ESP32 OLED tutorial for beginners](https://www.youtube.com/watch?v=u8g34BS8Ouw) (17 min) and the written [ESP32 + SSD1306 guide](https://randomnerdtutorials.com/esp32-ssd1306-oled-display-arduino-ide/).

## 4. Learn the basics

| Topic | Link |
| --- | --- |
| Addressable LEDs with FastLED | [Get started with WS2812B and FastLED](https://www.youtube.com/watch?v=JEwKKacCE2k) (30 min) |
| Timing without freezing the code | [millis() instead of delay()](https://www.youtube.com/watch?v=BYKQ9rk0FEQ) (14 min) |
| CAN bus | [CAN bus explained](https://www.youtube.com/watch?v=FqLDpHsxvf8) (CSS Electronics, 9 min) and the written [ESP32 CAN guide](https://lastminuteengineers.com/esp32-can-bus-tutorial/) |
| VESC basics | [VESC Tool 2024 setup](https://www.youtube.com/watch?v=YFl3VvZTRb0) (MBoards, 23 min) |
| PlatformIO (used by other Electrium repos, optional) | [ESP32 in VS Code with PlatformIO](https://www.youtube.com/watch?v=F3oPVm2n-fk) (11 min) |

## 5. What exists

[`firmware/README.md`](../../firmware/README.md) lists the known bugs in the 2024 code and the other Electrium repos that already read a VESC.

## 6. Pick a first task

Until you have a screen, your Stage 1 is Verify (section 3, steps 1 to 3) plus the board test (step 4 of Firmware Stage 1 in ONBOARDING.md). Post the Serial Monitor screenshot on [#12](https://github.com/Electrium-Mobility/Bakfiets-F26/issues/12), and add a screen photo once you have one. Then pick a Stage 2 task in [ONBOARDING.md](../../ONBOARDING.md#firmware-onboarding).

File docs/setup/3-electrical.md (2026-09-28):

# Setup for electrical

Do [Getting Started](../../ONBOARDING.md#getting-started) in the onboarding guide first. You need the safety training before battery work, but not for anything in this guide.

The steps you have to do are in [Electrical Stage 1](../../ONBOARDING.md#stage-1-read-a-real-board). This page repeats them with extra help, so you don't need to do anything twice.

## 1. Install KiCad 9

1. Download KiCad 9.0.9 for [Windows](https://downloads.kicad.org/kicad/windows/explore/stable/download/kicad-9.0.9-x86_64.exe) or [Mac](https://downloads.kicad.org/kicad/macos/explore/stable/download/kicad-unified-universal-9.0.9.dmg). Both links start the download straight away. It's free. Use 9, not KiCad 10: all the tutorial videos use 9, and a file saved in 10 can't be opened in 9.
2. Install with the default options, including the libraries.
3. Watch [KiCad 9.0 Getting Started, part 1](https://www.youtube.com/watch?v=0WCi1rhueH4) (DigiKey, 4 min) and continue through that series. For one video from schematic to finished board, try [Build your first PCB in KiCad 9](https://www.youtube.com/watch?v=moP6JxN7FWk) (16 min).

## 2. Your first hour: read a real board

1. In GitHub Desktop, choose **File > Clone repository > URL** and paste `Electrium-Mobility/anti-spark`.
2. In KiCad, choose **File > Open Project** and pick `Anti-Spark Switch.kicad_pro` in your `anti-spark` folder.
3. KiCad will say the project comes from an older version and offer to upgrade it. Click OK: that's expected. GitHub Desktop will then show those files as changed. Leave them, and don't commit them.
4. In the left panel, double-click `Anti-Spark Switch.kicad_sch` to open the schematic.
5. Find the three MOSFETs (Q1, Q2 and Q3, rated 100 V) and trace where the battery connects.

If you open the PCB, KiCad also warns that the `XT60PW-F` footprint library is missing. The 2023 designer kept it on their own computer, but it doesn't matter for reading the schematic.

## 3. Learn the basics

Before Stage 1 you only need the MOSFET video. Watch the rest when a task needs them.

| Topic | Video |
| --- | --- |
| Soldering | [Collin's Lab: Soldering](https://www.youtube.com/watch?v=QKbJxytERvg) (Adafruit, 5 min) |
| Multimeter | [How to use a multimeter](https://www.youtube.com/watch?v=SLkPtmnglOI) (SparkFun, 11 min) |
| Series and parallel cells | [Batteries in series vs parallel](https://www.youtube.com/watch?v=5lBDdcF6eAk) (3 min) |
| BMS | [BMS: properly protecting Li-ion packs](https://www.youtube.com/watch?v=rT-1gvkFj60) (GreatScott!, 13 min) |
| MOSFET as a switch | [Transistor (MOSFET) as a switch](https://www.youtube.com/watch?v=o4_NeqlJgOs) (GreatScott!, 6 min) |
| Buck converter | [DIY buck converter](https://www.youtube.com/watch?v=m8rK9gU30v4) (GreatScott!, 6 min) |
| VESC setup | [VESC Tool 2024: motor configuration and battery settings](https://www.youtube.com/watch?v=YFl3VvZTRb0) (MBoards, 23 min) |

## 4. What exists

[`electrical/README.md`](../../electrical/README.md) has the power flow diagram, explained step by step, and notes on which other Electrium boards you can reuse.

## 5. Pick a first task

Reading the anti-spark schematic (section 2) is your Stage 1. Post your notes on #8, then pick a Stage 2 task in [ONBOARDING.md](../../ONBOARDING.md#electrical-onboarding).

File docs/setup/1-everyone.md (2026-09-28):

# Setup for everyone

This page has moved into the onboarding guide, so there's one place to follow. Go to [ONBOARDING.md](../../ONBOARDING.md) and start with the to-do list at the top.

- Accounts, Discord and cloning the repo: [Getting Started](../../ONBOARDING.md#getting-started)
- Safety training and battery rules: [Safety Training](../../ONBOARDING.md#safety-training)
- Who leads what: [Who Leads What](../../ONBOARDING.md#who-leads-what)
- Sharing your work: [How to Submit](../../ONBOARDING.md#how-to-submit)

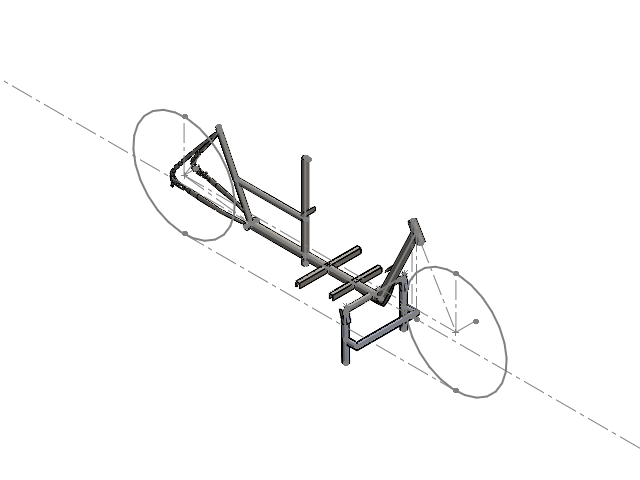
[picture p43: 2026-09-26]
docs/images/cad-previews/KickstandAssembly.png

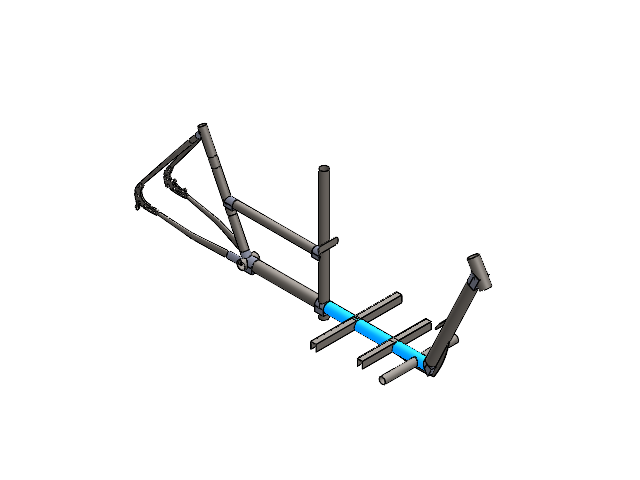
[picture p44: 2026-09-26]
docs/images/cad-previews/Notching_Assembly.png

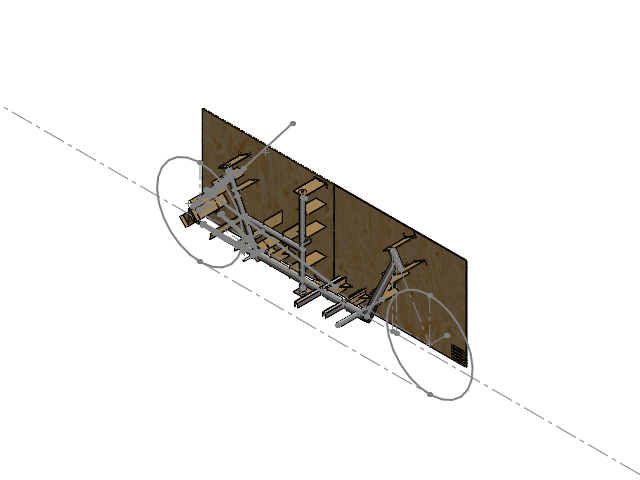
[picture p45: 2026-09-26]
docs/images/cad-previews/JigAssemblyMarch16.png

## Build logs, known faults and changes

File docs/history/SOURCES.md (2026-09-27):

# Where these files came from

Copied on 2026-09-26 from [Electrium-Mobility/bakfiets](https://github.com/Electrium-Mobility/bakfiets), which stays unchanged as the archive. Its full commit history is there.

| Folder here | Source | Commit |
| --- | --- | --- |
| `mechanical/cad-2024/` | `mechanical/` on `main` | 4b86a22 (2024-07-04) |
| `mechanical/cad-2025-coop/` | `mechanical/bakfiets_coop_version/` on `summer2025coop` | 6fc9958 (2025-05-28) |
| `mechanical/cad-2025-coop/edited-2024-parts/` | five top-level `mechanical/` files as edited on `summer2025coop` | 6fc9958 |
| `firmware/display-2024/` | `firmware/main.cpp`, `firmware/display-prototype.jpeg` on `main` | 4b86a22 |
| `firmware/desk-demo/` | copy of `firmware/main.cpp` with `LED_PIN` changed from 9 to 5 | new |
| `firmware/simulator-2024/` | `firmware/simulator/` on `main`, without the 314 MB `target/` build folder | 4b86a22 |
| `firmware/can-twai-2024/` | `twai_can_sender/`, `twai_can_receiver/` on `twai_can` (open pull request #2 there) | 34b9d66 (2024-11-11) |
| `electrical/diagrams/high-level-circuit-diagram-2024.png` | `firmware/high-level-circuit-diagram.png` on `main` | 4b86a22 |
| `electrical/diagrams/*.png` (other), `firmware/diagrams/`, `docs/diagrams/` | drawn this term by the `.py` script next to each image | new |
| `docs/images/doc_hw_*.png` | composited from `docs/images/cad-previews/` | new |
| `docs/history/website-*.md`, `docs/images/render-2024.png`, `team-w2024.png` | [electrium-w24website](https://github.com/Electrium-Mobility/electrium-w24website) bakfiets pages | |
| `docs/images/cad-previews/` | preview images extracted from inside the SolidWorks files | new |
| `docs/images/doc_elec_examples.png`, `doc_hw_longtail.png` | F25 Skateboard and W2025 longtail pages on the website, and esc-w26 | |

Left out on purpose: `Frame 2.0-Static 2.CWR` (95 MB FEA results; rerun the study), SolidWorks lock files (`~$*`), `.DS_Store`, `sdkconfig.old`, and the simulator's build folder.

## 2024 team (from the club website)

| Role | People |
| --- | --- |
| Team lead and mechanical lead | Jerry Chen |
| Firmware lead | Patrick He |
| Electrical lead | Samuel Ke |
| Mechanical | Kevin Ng, Aidan Thompson, Aiyesha Shibly, Samual Wong, Allen Lu |
| Firmware | Kimberley Hoang, Alisa Wu, Aman Zaveri |
| Electrical | Jacob Wielowieyski, Alex Liu, Suhyma Rahman |

Other contributors on GitHub: etanguan (steering, jig, Frame 2.0 FEA, 2024), Simra Khan (CAN code, Nov 2024), Anthony3141 (co-op CAD, May 2025).

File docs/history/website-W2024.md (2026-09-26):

---
sidebar_position: 1
---

# Bakfiets

Electric Bike
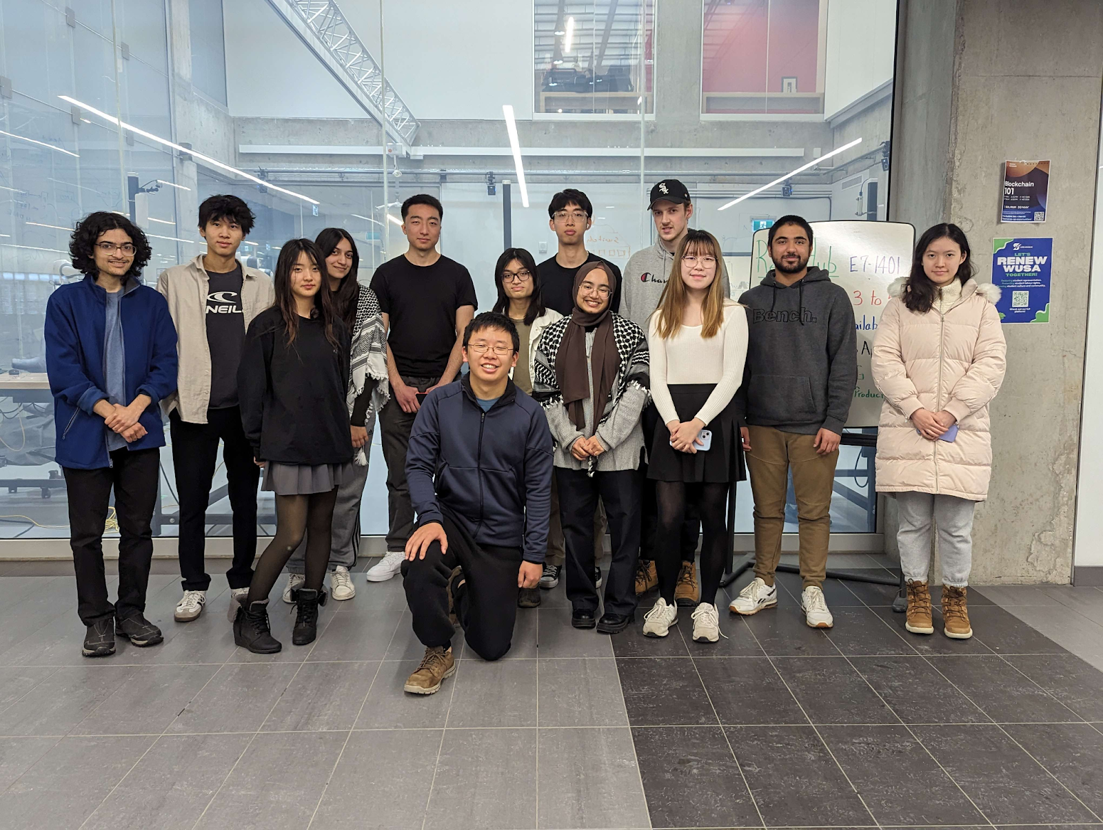
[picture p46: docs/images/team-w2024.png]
Electric Bike Team


### Project Info

| **Term:** | Winter 2024 |
| --- | ---|
| **Team Lead:** | Jerry Chen |
| **Mechanical Lead:** | Jerry Chen |
| **Firmware Lead:** | Patrick He |
| **Electrical Lead:** | Samuel Ke |
| **Mechanical Team:** | Jerry Chen, Kevin Ng, Aidan Thompson, Aiyesha Shibly, Samual Wong, Allen Lu |
| **Firmware Team:** | Patrick He, Kimberley Hoang, Alisa Wu, Aman Zaveri |
| **Electrical Team:** | Jacob Wielowieyski, Alex Liu, Samuel Ke, Suhyma Rahman |

### Project Description

Bakfiets is a front-loading cargo bike style popular in the Netherlands for carrying groceries or bringing kids to school. Our Bakfiets, “Bak Choy”, is an electrically-assisted bakfiets with a custom-built frame, 48V electrical system, dynamic lighting, and display interface.

### What We Do
- Custom Frame: Tailor-made 4130 chromoly frame designed using SolidWorks Weldments, featuring two 26” wheels, disc brakes, and suspension fork.
- Welding Jig: The rear triangle is welded using our standard adjustable aluminum extrusion bike jig, while the main frame is welded using a single-use laser cut MDF jig.
- Steering System: The steering is connected to the front fork via a linkage system using an adjustable-length steel tube with ball joints on either end. Steering linkage was optimized to provide a natural turning rate and to clear other components. A solid linkage was chosen over a cable driven system due to the increased simplicity and reliability.
- Kickstand: Heavy-duty spring-loaded mild steel kickstand with lowered middle to provide clearance for the steering linkage.
- 48V Electrical System: The bike features a 48V 12S3P 18650 quick-release battery pack, 500W hub motor, and a 48V/5V power distribution board to power the undermounted LED strip and microcontroller. We also attempted to design our own anti sparks to protect the battery.
- VESC Motor Controller: The bike uses an open-source FSESC6.7 VESC-based motor controller to run the motor and interface with the microcontroller.
- Display Interface: The bike features an OLED display powered by an ESP32 S3 Pico, which displays information like speed, battery, and power level. The microcontroller also runs the LED strip via the FastLED library, allowing for a variety of patterns, as well as segmented turn signal indication. 

### Our Goal

**Our goals are to improve our mechanical, electrical, and firmware abilities:**\
For many of us, it was our first time using SolidWorks weldments, designing electronics enclosures, and creating welding jigs. As well, we learned machining, notching tubing, and woodworking. The power distribution board and anti sparks were some of our first custom PCBs, and members learned how to solder XT30/60 connectors and SMD components. Members learned how to control VESC and program microcontrollers to respond to user inputs.

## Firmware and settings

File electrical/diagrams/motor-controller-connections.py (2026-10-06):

import sys, os
HERE = os.path.dirname(os.path.abspath(__file__))
sys.path.insert(0, os.path.join(HERE, '..', '..', 'docs', 'diagrams'))
from notebook import *
from matplotlib.patches import Rectangle, Circle

fig, ax = page(150, 94, (15, 9.4))
note(ax, 8, 90, 'What plugs into the motor controller', size=24, weight='bold')
note(ax, 8, 85.2, 'The FSESC 6.7 (a VESC) sits in the middle of everything. Thick lines carry battery power. Thin lines are signals.',
     size=11.5, color=PENCIL)

def block(x, y, w, h, title, sub, col):
    ax.add_patch(Rectangle((x, y), w, h, fc='#f3efe4', ec=col, lw=2, zorder=2))
    note(ax, x + w / 2, y + h - 3, title, size=12.5, weight='bold', ha='center', zorder=3)
    if sub: note(ax, x + w / 2, y + h / 2 - 2, sub, size=9.5, color=PENCIL, ha='center', linespacing=1.15, zorder=3)
def thick(xs, ys, c=RED, lw=5): ax.plot(xs, ys, color=c, lw=lw, solid_capstyle='round', zorder=1)
def thin(xs, ys, c, ls='-'): ax.plot(xs, ys, color=c, lw=2, ls=ls, solid_capstyle='round', zorder=1)

Y = 64
block(8, 56, 20, 16, 'battery', 'Pack 4, 12S2P\n36 to 50.4V', RED)
block(8, 39, 20, 11, 'BMS', 'pack B- in,\nP- out', RED)
thick([18, 18], [56, 50], INK, lw=4)
thick([28, 42, 42, 92], [44.5, 44.5, 54, 54], INK, lw=4)
note(ax, 44, 55.8, 'negative (P-) to the controller', size=9, color=INK)
block(40, 60, 9, 8, 'fuse', '', RED)
block(60, 58, 15, 12, 'antispark', 'soft on\nswitch', RED)
block(92, 44, 28, 30, 'FSESC 6.7', 'motor controller\n(VESC)', INK)
block(130, 56, 16, 16, 'hub motor', '2000W, set\nto 500W', INK)
thick([28, 40], [Y, Y]); thick([49, 60], [Y, Y]); thick([75, 92], [Y, Y])
note(ax, 30, Y + 1.8, 'B+', size=10, color=RED, weight='bold')
for dy in (-2.2, 0, 2.2):
    thick([120, 130], [Y + dy, Y + dy], INK, lw=3)
note(ax, 125, Y - 5.4, '3 phase\nwires', size=8.5, color=INK, ha='center', linespacing=1)
thin([138, 138, 120], [56, 52, 52], PENCIL, ls=(0, (3, 2)))
note(ax, 139, 53, 'hall cable, if the\nmotor has one', size=8.5, color=PENCIL, linespacing=1.05)
point(ax, (34, 78), (44.5, 68.5), 'fuse on the positive side, DC-rated for 60V\nor more. car blade fuses (32V) are not safe', color=RED, rad=-0.25)
point(ax, (58, 47), (67, 57.6), 'connect battery last,\nthrough the antispark', color=PENCIL, rad=0.2)

# laptop
ax.add_patch(Rectangle((98, 76.4), 18, 6, fc='#e4ebf5', ec=BLUE, lw=1.5, zorder=2))
note(ax, 107, 79.4, 'laptop: VESC Tool', size=10.5, ha='center', color=BLUE)
thin([107, 107], [76.4, 74], BLUE, ls=(0, (3, 2)))
note(ax, 108.5, 75.2, 'USB, for setup', size=8.5, color=BLUE)

# COMM port on the controller
px = [95, 99.5, 104, 108.5, 113, 117.5]
names = ['3.3V', 'ADC1', 'GND', 'TX', 'RX', '5V']
ax.add_patch(Rectangle((93.2, 44.6), 25.6, 5.6, fc='#e9e6df', ec=INK, lw=1.2, zorder=3))
for x, n in zip(px, names):
    ax.add_patch(Circle((x, 46.2), 0.9, fc=INK if n != '5V' else PAPER, ec=INK, lw=1, zorder=4))
    mono(ax, x, 48.8, n, size=7.6, ha='center', zorder=4, color=INK if n != '5V' else '#6f6a60')
note(ax, 122, 44, 'COMM port. the pin order here\nis only for the drawing: check\nthe Flipsky manual', size=9, color=PENCIL, linespacing=1.1)

# throttle, wires drop straight down then left, no crossings
block(22, 10, 24, 15, 'thumb throttle', 'hall sensor inside', GOLD)
for n, y in [('3.3V', 20.5), ('ADC1', 17.5), ('GND', 14.5)]:
    x = px[names.index(n)]
    thin([46, x, x], [y, y, 45.3], GOLD if n != 'GND' else INK)
    mono(ax, 45, y, n, size=7.6, color=GOLD if n != 'GND' else INK, ha='right', zorder=3)
point(ax, (6, 33.5), (26, 24.6), 'power it from 3.3V, not 5V.\nthe ADC input only takes 3.3V', color=RED, rad=-0.2)

# ESP32, to the right; RX->TX and TX->RX, GND shared
block(124, 4, 22, 24, 'ESP32-S3', '', BLUE)
thin([113, 113, 124], [45.3, 20.5, 20.5], BLUE)     # VESC RX <- ESP TX
thin([108.5, 108.5, 124], [45.3, 17.5, 17.5], BLUE) # VESC TX -> ESP RX
thin([104, 104, 124], [14.5, 11.5, 11.5], INK)      # shared ground
for n, y in [('TX  GPIO17', 20.5), ('RX  GPIO18', 17.5), ('GND', 11.5)]:
    mono(ax, 125, y, n, size=7.6, color=BLUE if n != 'GND' else INK, zorder=3)
point(ax, (58, 38), (108, 30), "TX to RX, RX to TX.\nthe two data wires swap", color=BLUE, rad=-0.2)
point(ax, (128, 36), (117.8, 45), "leave the controller's 5V\npin off the ESP32", color=RED, rad=-0.2, ha='left')
ax.annotate('', xy=(135, 25.2), xytext=(135, 31), arrowprops=dict(arrowstyle='->', color=GOLD, lw=2))
note(ax, 136.5, 29.5, '5V from the power board', size=9, color=GOLD)

mono(ax, 149, -1.5, 'wiring from issues #18 (throttle), #20 (fuse) and #22 (UART). GPIO choice is a suggestion.', size=7, color='#6f6a60', ha='right')
save(fig, os.path.join(HERE, 'motor-controller-connections.png'))

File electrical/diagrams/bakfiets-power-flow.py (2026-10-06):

import sys, os
HERE = os.path.dirname(os.path.abspath(__file__))
sys.path.insert(0, os.path.join(HERE, '..', '..', 'docs', 'diagrams'))
from notebook import *
from matplotlib.patches import Rectangle, Circle, FancyArrowPatch

fig, ax = page(150, 98, (15, 9.8))
note(ax, 8, 94, 'How power flows through the bakfiets', size=24, weight='bold')
note(ax, 8, 89.2, 'Follow the numbers, which match the list under this drawing. Red is the positive side, black the negative side, both at battery voltage.',
     size=11.5, color=PENCIL)

def block(x, y, w, h, title, sub, col, n=None):
    ax.add_patch(Rectangle((x, y), w, h, fc='#f3efe4', ec=col, lw=2, zorder=2))
    note(ax, x + w / 2, y + h - 3, title, size=12, weight='bold', ha='center', zorder=3)
    if sub: note(ax, x + w / 2, y + h / 2 - 2, sub, size=9.2, color=PENCIL, ha='center', linespacing=1.15, zorder=3)
    if n:
        ax.add_patch(Circle((x + 0.2, y + h - 0.2), 1.9, fc=col, ec=col, zorder=4))
        note(ax, x + 0.2, y + h - 0.3, str(n), size=10.5, color='white', weight='bold', ha='center', zorder=5)
def line(xs, ys, c=RED, lw=5): ax.plot(xs, ys, color=c, lw=lw, solid_capstyle='round', zorder=1)
def arrow(p, q, c, ls='-', lw=2, rad=0):
    ax.add_patch(FancyArrowPatch(p, q, arrowstyle='-|>', mutation_scale=14, color=c, lw=lw, ls=ls,
                                 connectionstyle=f'arc3,rad={rad}', zorder=1))

# positive side, top row
Y = 72
block(9, 66, 15, 12, 'charger', '12S, 50.4V', RED, 1)
block(34, 62, 18, 16, 'battery pack', 'Pack 4: 12S2P\nlithium-ion cells', RED, 2)
block(58, 68, 7, 8, 'fuse', '', RED)
block(72, 66, 15, 12, 'antispark', 'soft power-on', RED, 4)
block(108, 60, 20, 20, 'motor\ncontroller', '', RED, 5)
note(ax, 118, 62.5, 'FSESC 6.7 (VESC)', size=9.2, color=PENCIL, ha='center', zorder=3)
block(134, 63, 14, 14, 'hub\nmotor', '', INK)
note(ax, 141, 65.5, '2000W, set\nto 500W', size=9.2, color=PENCIL, ha='center', zorder=3)
line([24, 34], [Y, Y]); line([52, 58], [Y, Y]); line([65, 72], [Y, Y]); line([87, 108], [Y, Y])
for dy in (-2, 0, 2): line([128, 134], [Y + dy, Y + dy], INK, lw=2.6)
note(ax, 131, 80.5, '3 phase\nwires', size=8.5, color=INK, ha='center', linespacing=1)
note(ax, 29, 81.5, 'charging port,\nfused (DC 60V+)', size=8.2, color=RED, ha='center', linespacing=1)
note(ax, 61.5, 82, 'fuse on the + side,\nDC-rated 60V or more', size=9.5, color=RED, ha='center', linespacing=1.1)

# negative side through the BMS
block(34, 44, 18, 11, 'BMS', 'B- in, P- out', INK, 3)
line([43, 43], [62, 55], INK, lw=4)
note(ax, 44, 58.5, 'B-', size=10, color=INK, weight='bold')
line([52, 112, 112], [49.5, 49.5, 60], INK, lw=4)
note(ax, 58, 51.4, 'P-: charging and riding current both pass through the BMS', size=9.2, color=INK)
line([20, 20, 34], [66, 47, 47], INK, lw=2.6)
note(ax, 7.5, 57, 'charger\nnegative', size=8.5, color=INK, linespacing=1)
note(ax, 79.5, 64.2, 'the Electrium board likely\nswitches the - wire instead.\ncheck it in Stage 1', size=8.8, color=PENCIL, ha='center', va='top', linespacing=1.05)

# power board
block(88, 26, 22, 14, 'power board', 'steps battery power\ndown to 5V', GOLD, 6)
line([99, 99], [Y, 40], RED, lw=3.5)
line([104, 104], [49.5, 40], INK, lw=3.5)

# throttle and brakes into the controller
block(128, 40, 18, 11, 'throttle', 'thumb lever', BLUE)
arrow((134, 51), (124, 59.8), BLUE, ls=(0, (4, 3)))
note(ax, 136, 54.5, 'speed request\n(ADC, 3.3V)', size=8.8, color=BLUE, linespacing=1.05)

# electronics
block(34, 8, 24, 13, 'ESP32-S3', "the bike's small\ncomputer", BLUE, 7)
block(9, 9, 17, 10, 'screen', '128x64 OLED', BLUE)
block(84, 9, 22, 10, 'lights', 'LED strip, brake', GOLD)
block(34, 0.5, 24, 5.5, 'buttons', '', BLUE)
block(116, 9, 22, 10, 'brake levers', '', BLUE)
arrow((92, 26), (52, 21.2), GOLD, lw=2.4, rad=-0.1)
arrow((97, 26), (97, 19.2), GOLD, lw=2.4)
note(ax, 70, 25.6, '5V', size=10.5, color=GOLD, weight='bold')
note(ax, 98.5, 23, '5V', size=10.5, color=GOLD, weight='bold')
arrow((34, 14), (26.2, 14), BLUE, ls=(0, (4, 3)))
note(ax, 28.3, 16.4, 'I2C', size=9.5, color=BLUE)
arrow((58, 14), (83.8, 14), BLUE, ls=(0, (4, 3)))
note(ax, 63, 16.4, 'LED data', size=9.5, color=BLUE)
arrow((46, 6), (46, 7.8), BLUE, ls=(0, (4, 3)))
arrow((116, 14), (106.2, 14), BLUE, ls=(0, (4, 3)))
arrow((127, 19), (121, 59.8), BLUE, ls=(0, (4, 3)), rad=0.1)
note(ax, 131, 30, 'brake levers cut\nmotor power (#18)\nand light the\nbrake lights', size=8.8, color=BLUE, linespacing=1.05)
ax.plot([40, 40, 117, 117], [21, 43.5, 43.5, 60], color=BLUE, lw=1.8, ls=(0, (2, 3)), zorder=1)
note(ax, 56, 45.3, 'UART (#22): speed and battery data', size=9.3, color=BLUE)

# key
lx, ly = 9, 34
note(ax, lx, ly, 'key', size=12, weight='bold')
line([lx, lx + 4], [ly - 3.2, ly - 3.2], RED, 5); note(ax, lx + 5.5, ly - 3.2, 'battery +', size=9.5)
line([lx, lx + 4], [ly - 6.4, ly - 6.4], INK, 4); note(ax, lx + 5.5, ly - 6.4, 'battery -', size=9.5)
ax.plot([lx + 18, lx + 22], [ly - 3.2, ly - 3.2], color=GOLD, lw=2.4); note(ax, lx + 23.5, ly - 3.2, '5V', size=9.5)
ax.plot([lx + 18, lx + 22], [ly - 6.4, ly - 6.4], color=BLUE, lw=2, ls=(0, (4, 3))); note(ax, lx + 23.5, ly - 6.4, 'signals', size=9.5)
mono(ax, 149, -2, 'redrawn from the 2024 block diagram (high-level-circuit-diagram-2024.png). Fuse, BMS side, brake cut-off and UART added from issues #18 to #22', size=6.6, color='#6f6a60', ha='right')
save(fig, os.path.join(HERE, 'bakfiets-power-flow.png'))

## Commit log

2026-09-26 Link the handover doc; tidy electrical README
    Point README at the Bakfiets F26 Onboarding doc
    Setup guides: clearer steps, safety specifics, subteam lead roles; fix review findings
    - Add weldment profiles through SolidWorks File Locations (no admin rights needed)
    - Name SolidWorks 2026 as the team version; KiCad upgrade/library warnings; ESP32-S3 USB port and BOOT tips
    - Replace 'ask the lead' prompts with the actual information
    - Correct motor-decision reasoning, TVS wording and ESP32 pin wording
    Describe project lead and subteam lead roles
    Add clearer power flow diagram and record open-question decisions
    Set up Bakfiets F26: 2024 and 2025 files, setup guides, READMEs
    Copies the 2024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
    [3 hole connecting part.SLDPRT, 91280A626_Medium-Strength Class 8.8 Steel Hex Head Screw.SLDPRT, Aluminum Angle (1.25 x 0.125).SLDPRT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]
2026-09-26 Rename hardware/ to mechanical/; add term projects page
    [3 hole connecting part.SLDPRT, 91280A626_Medium-Strength Class 8.8 Steel Hex Head Screw.SLDPRT, Aluminum Angle (1.25 x 0.125).SLDPRT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]
2026-09-26 Apply review fixes: stage pointers, commit summary step, glossary terms, wording
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2026-09-26 Workbay 1002, board pickup note, SDC purchase process
2026-09-26 Add SDC welding test, shop hours, WatCard access, battery inventory and shared-space rules
2026-09-27 Apply four-reader review: safety, consistency, hedging, meeting agenda, diagram fixes
    [motor-controller-connections.py]
2026-09-27 Redraw power flow diagram in notebook style with fuse and UART
2026-09-27 Second review pass: BMS on both paths, brake cut-off, pack integration, WHMIS wording, term order, diagram fixes
    [bakfiets-power-flow.py, motor-controller-connections.py, pack-12s3p.py]
2026-09-27 Use real Discord names: #bakfiets-mech/elec/firm channels, Github usernames thread
2026-09-27 Bigger diagram text, frame welds term project (#30), name both Electrium team leads
2026-09-28 Bay access by lead (no WatCard), boards and 2024 parts in the bay, Electrium ordering; to-do list, Mac note; ONBOARDING is the single setup guide
2026-09-28 Arena rewrite of the guide's opening; pass-3 review: safe walkaround for the 2024 pack, pack clearing in #21, WHMIS 30 min, antispark ground note, consistency fixes
    [bakfiets-power-flow.py]
2026-09-28 Bike render at the top of the guide, and far fewer semicolons in docs, issues and diagrams
    [bakfiets-power-flow.py]
2026-09-28 First-year readability pass: what to skip, done-when checks, clearer battery rules, more glossary terms
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2026-09-28 Stay on KiCad 9, since the tutorial videos use it
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2026-09-30 new file
    [Part1_kira.SLDPRT, bakfiets_ball_joint.SLDPRT, bakfiets_cargo_box_low_detail.SLDPRT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]
2026-10-02 Restore cad-2025-coop files re-saved by SolidWorks in d3d1f25's parent push; remove stray assembly copy
    SolidWorks converted the frozen co-op files to 2026 format on save and they were pushed with a practice part. The practice part in cad-2026/ is kept.
    [bakfiets_ball_joint.SLDPRT, bakfiets_cargo_box_low_detail.SLDPRT, bakfiets_frame.SLDPRT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]
2026-10-06 Use the 2000 W hub motor and Pack 4 (48 V 12S2P); ESP32 boards found, board test until screens arrive; steering first
2026-10-06 Review fixes: Ontario 500 W rating note, screens to be found, safer bench test and pack check steps, new brakes and hub motor fit tasks
2026-10-06 Brakes and hub motor fit right after steering
2026-10-06 Add labelled bay photos and link them; BMS and charger already on hand
2026-10-06 Gantt chart: drop subtitle and footnote, tighten layout
2026-10-06 Stage 2: link every open task per subteam and name the bigger ones
2026-10-06 Stage 2 tables list every task that's open now
2026-10-07 After Ling: simpler Pack 4 check, motor okayed, screens likely bought
2026-10-07 Pack 4: just a look-over and a supervised first charge
2026-10-07 Pack 4 is charged and working: #21 is now getting it wired up
2026-10-07 Cut the 7 Oct meeting plan down to tasks
2026-10-10 Timeline: #2 due 21 Oct, add #3 and #27. #27 is after Stage 2
2026-10-10 Add brakes explainer for #32: bosses, mounts, hub motor, front and back plan
2026-10-10 Brakes doc: explain findings with labelled photos of our bike, open questions instead of a plan
2026-10-10 Brakes doc: restructure, clearer diagrams, dot-and-line photo labels, both front routes reach the axle
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2026-10-10 Brakes doc: give the reason for each open question
2026-10-10 Brakes doc: seat stays clearly have no bosses, drop the check
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2026-10-10 Brakes doc: second review round, reasons for every limit and question, clearer dropout tabs, diagram fixes
2026-10-10 Brakes doc: drop testing plan and load question, back brake due 28 Oct
2026-10-10 Gantt: split brakes into front (21 Oct) and back (28 Oct), front brake joins order 2
2026-10-10 Gantt: Pack 4 soldering moves to the days after reading week, #18 bench test follows it
2026-10-12 Power flow diagram: controller model unconfirmed, drop old antispark note. BOM lives in a sheet linked from #11
2026-10-12 Power flow diagram: label every connection with what it carries and why
2026-10-12 Power flow diagram: technical subtitle with pack voltage and line key
2026-10-12 ONBOARDING: add #34 to mech Stage 2, drop closed #4, wheel fit is #31, controller model unconfirmed. Brakes doc: cut-off wiring is #20
2026-10-13 Power flow diagram: negative runs through the antispark as in the photo, add hall sensor line
2026-10-13 Power flow diagram: add the antispark's power button. README: key covers black lines
2026-10-14 ONBOARDING: firmware Stage 1 can use the Wokwi simulator or a real board
2026-10-14 ONBOARDING: tested Wokwi steps for firmware Stage 1
2026-10-14 ONBOARDING: firmware Stage 1 Wokwi path, where to copy the code, how to post
2026-10-20 Brakes doc: front brake type not confirmed, front due 29 Oct (#32), back brake is #34 with Ling's rotor-on-motor idea
2026-10-28 Meeting plan for Wed 28 Oct (soldering, bench test)
2026-10-28 Meeting plan 28 Oct: steering rod + CAD date, front brake cable plan, torque arm CAD question
2026-10-28 Front brake is a cable disc brake (keep it, longer cable). Meeting plan: start #22 at the bench test
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2026-10-29 Power board: only the buck converters matter, antispark is store-bought
2026-10-29 Add labelled power board schematic images, narrow #9 note to the 5 V converter
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2026-10-31 Cut bms-charging.md to the BMS, charger and XLR socket
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2026-10-31 bms-charging.md: charge lead fuse depends on common or separate port
2026-11-01 Add docs/links.md with the team board, budget and every issue
2026-11-04 Move the motor test to the start of electrical's time
2026-11-04 Add the motor test setup diagram to the 4 Nov plan
2026-11-04 Name the exact parts and VESC settings in the 4 Nov plan
2026-11-04 Plan the motor test around Jack arriving at 7
2026-11-04 Add Ling's steering CAD review to the 4 Nov plan
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2026-11-07 Update the brake cut-off plan for the bay levers
2026-11-07 Add the bay lever photos to the brakes doc
2026-11-07 Add the remaining bay photos and plan for 3-wire levers
2026-11-07 Start the brake cut-off with the rear lever only
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2026-11-11 Add Y-cable, brake lever stamp and thumb throttle figures for issues
